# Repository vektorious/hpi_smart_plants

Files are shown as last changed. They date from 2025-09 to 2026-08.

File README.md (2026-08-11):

# Smart Plants Starter Kit

A hands-on introduction to building low-power, Wi-Fi-connected plant monitoring systems.
You'll learn the basics of microcontroller programming, soil moisture sensing, and Wi-Fi data
transfer — all while building a device that actually keeps your plants alive.

The device wakes from deep sleep, reads soil moisture (and optionally temperature, humidity,
light, and battery level), sends data to an online dashboard, then sleeps again to conserve
battery.

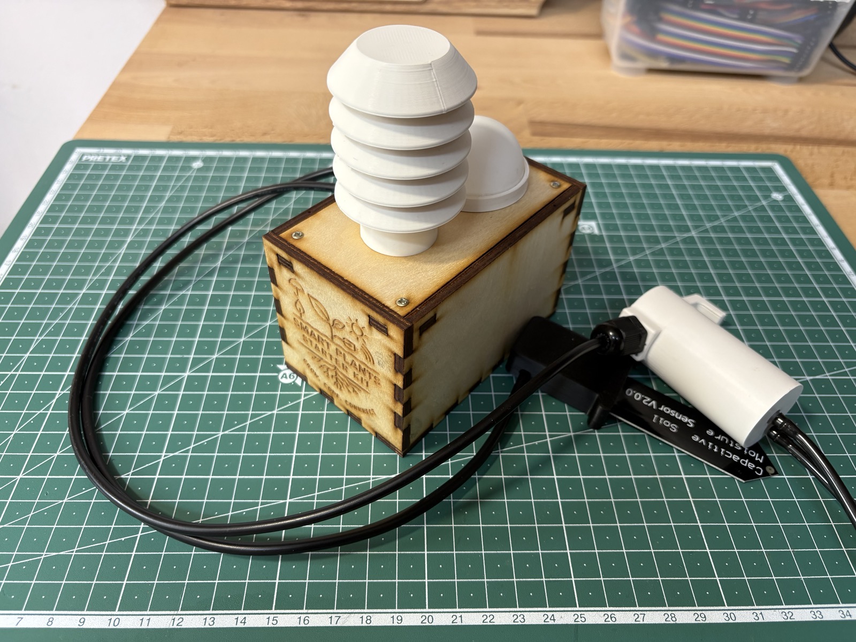
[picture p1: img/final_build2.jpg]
Smart Plants rev2 build


---

## What You'll Build

By the end of the workshop you'll have a battery-powered soil moisture sensor that:
- Measures soil moisture every hour (configurable)
- Sends data to an online dashboard via Wi-Fi
- Sleeps between measurements to conserve battery
- Waters your plant automatically when the soil gets too dry

No soldering experience required — but you'll get the chance to try!

---

## What's in the Kit

- Waveshare ESP32-C6 Zero microcontroller
- Smart Plants breakout PCB
- Capacitive soil moisture sensor + cable
- BME280 sensor (temperature, humidity, pressure)
- TSL2591 sensor (light)
- Mini diaphragm pump
- Battery pack
- Laser-cut housing
- 3D-printed sensor and pump housings
- Screws, velcro, cable gland

---

## Before You Begin

Make sure you have:
- A computer with a USB-C port (or adapter) and a **Chrome, Edge, or Opera** browser
  (used by the browser-based firmware installer)
- A USB-C **data** cable
- A 2.4 GHz Wi-Fi network

Everything else — firmware and configuration — is covered step by step in the build instructions
below. You install the firmware straight from the browser; only building it from source needs the
[Arduino IDE](https://www.arduino.cc/en/software).

---

## Build Instructions

**Start here:** [`instructions/build_instructions.md`](instructions/build_instructions.md)

That guide covers the full assembly, programming, calibration, and deployment for the main
Waveshare build — from soldering the PCB to seeing your first readings on the dashboard.

Firmware installs from the browser — no toolchain needed — via the web flasher:
**<https://vektorious.github.io/hpi_smart_plants/>**.

---

## Learning Goals

- Read analog sensor data and convert it to meaningful values
- Understand how to minimise power consumption with deep sleep
- Send data securely to a server over Wi-Fi using HTTP
- Learn how a cloud dashboard receives and displays live sensor readings

---

## Configured on the Device

All per-device settings — Wi-Fi, device name, sleep interval, moisture calibration, and
which sensors and the pump are enabled — are configured **on the device through a Wi-Fi setup
portal** after flashing, and stored in non-volatile memory. No code edits or recompiling: one
flashed binary works for every configuration.

The setup portal opens automatically on first boot (or on a double-press of the reset button) and
also shows **live sensor readings** and an **API connection test** so you can confirm everything
works. The `DEFAULT_*` values in `code/sp_modular/config.h` are only the factory defaults applied
on first boot. Building from source? See
[`instructions/firmware_from_source.md`](instructions/firmware_from_source.md).

---

## Board Variants

Two controller boards are supported. Both run the same firmware (`code/sp_modular/`).

| Variant | Board | PCB | Who it's for |
|---|---|-----|---|
| **Main build** | Waveshare ESP32-C6 Zero | `smart_plants_breakout_ws-board_rev2` | Student workshops |
| **Alternative** | SEEED Studio XIAO ESP32-C6 | `smart_plants_breakout_rev1` | Alternative / reference build |

---

## Repository Structure

```
code/
  sp_modular/              Modular firmware (current, for all builds)
    config.h               Factory defaults (DEFAULT_*), pin assignments, structs
    settings.ino           Runtime settings stored in NVS/Preferences
    portal.ino             WiFiManager setup portal + live sensor page
    sp_modular.ino         Entry point
    *.ino                  Sensor and actuator modules
  legacy/                  Old monolithic sketches (breadboard era, unsupported)

web-flasher/               Browser-based firmware installer (ESP Web Tools)

hardware/
  pcb/
    smart_plants_breakout_ws-board_rev2/   Main build PCB (Waveshare)
    smart_plants_breakout_rev1/            Alternative build PCB (XIAO)
    legacy/                                Older PCB revisions
    ext_files/                             KiCAD footprints and symbols
  3d-print/
    bme_housing/           Miniature Stevenson screen for BME280
    light_sensor/          TSL2591 mount with diffuser
    moisture_sensor/       Soil probe housing
    pump/                  Diaphragm pump enclosure
    cable_plugs/           M12 cable gland plug
  laser_files/
    SmartPlants_4mm_v3.svg Current enclosure template (4 mm material)
    legacy/                Older enclosure versions

instructions/
  build_instructions.md    Main build guide — start here
  firmware_from_source.md  Build/upload from Arduino IDE + component test sketches
  background_information.md Sensor theory, system overview, design rationale
  quick_reference/         Printable one-page build reference (md, html, pdf)
  legacy/                  Old breadboard-era guides (unsupported)

img/                       Photos and diagrams referenced by the instructions
```

---

## Background Reading

[`instructions/background_information.md`](instructions/background_information.md) covers:

- **Sensor selection** — why capacitive over resistive moisture sensors, why BME280 and TSL2591
  were chosen over simpler alternatives, and the trade-offs involved
- **Pump control** — how MOSFETs and relays work, and why this design uses an IRLZ14
- **How the system works** — the full data path from firmware wake-up cycle through the FastAPI
  server and PostgreSQL database to the live Grafana dashboard
- **Similar projects** — related open-source plant monitoring builds for further inspiration

Useful context for understanding *why* things are built the way they are.

---

## Licenses

| Component | License |
|---|---|
| Software (`code/`) | [MIT](LICENSE.code) |
| Hardware (`hardware/`) | [CERN-OHL-W 2.0](LICENSE.hardware) |
| Documentation (`instructions/`, `README.md`, `img/`) | [CC-BY 4.0](LICENSE.docs) |

Open Source Licenses

This project is certified open source hardware by OSHWA under certification ID `DE000173`.

OSHWA certification mark

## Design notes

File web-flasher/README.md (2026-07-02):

# Smart Plants — Web Flasher

A browser-based installer for the Smart Plants firmware, built on
[ESP Web Tools](https://esphome.github.io/esp-web-tools/). Students open a web page,
click **Connect**, and flash the board — no Arduino IDE or drivers needed.

## Files

| File | Purpose |
|---|---|
| `index.html` | The flasher page with the install button |
| `manifest.json` | Tells ESP Web Tools which chip + binary to flash |
| `firmware/smart_plants.bin` | The merged firmware image (generated — see below) |

## Requirements (for the student flashing)

- **Chrome, Edge, or Opera** on a desktop (Web Serial is not in Firefox/Safari or on iOS).
- The page must be served over **HTTPS** (or `http://localhost` for testing). Web Serial
  refuses to run on plain `http://`.
- A **USB-C data cable** (not charge-only).

## Building / updating the firmware image

The firmware is a single merged image flashed at offset `0x0`. The ESP32 Arduino core
produces this automatically — no manual `esptool merge_bin` step is needed.

### Option A — Arduino IDE

1. Open `code/sp_modular/` in Arduino IDE.
2. Select board **Waveshare ESP32-C6-Zero**, and under
   **Tools → Partition Scheme** choose **Huge APP (3MB No OTA/1MB SPIFFS)**.
   (The default partition is too small — the build won't fit.)
3. **Sketch → Export Compiled Binary.**
4. In the sketch's `build/…/` output folder, find `sp_modular.ino.merged.bin`.
5. Copy it to `web-flasher/firmware/smart_plants.bin`.

### Option B — arduino-cli

```bash
cd code
arduino-cli compile \
  --fqbn esp32:esp32:waveshare_esp32_c6_zero:PartitionScheme=huge_app \
  --output-dir /tmp/sp-build \
  sp_modular

cp /tmp/sp-build/sp_modular.ino.merged.bin \
   ../web-flasher/firmware/smart_plants.bin
```

After copying, bump `"version"` in `manifest.json` so returning users get the update.

> The merged image is a full 4 MB flash image starting at `0x0` (bootloader + partition
> table + app), which is exactly what the manifest expects: a single part at offset 0.

## Hosting

**Live at:** <https://vektorious.github.io/hpi_smart_plants/>
(served over HTTPS, which Web Serial requires).

GitHub Pages can only publish from a branch root or `/docs`, not an arbitrary subfolder, so the
site is published from a dedicated **`gh-pages`** branch that mirrors this folder at its root:

```
gh-pages/
├── index.html          # copy of web-flasher/index.html
├── manifest.json       # copy of web-flasher/manifest.json
├── .nojekyll
└── firmware/
    └── smart_plants.bin   # the merged image (tracked here, not on main)
```

The 4 MB binary lives only on `gh-pages` to keep `main` history clean.

**To publish a new firmware build:**

```bash
git worktree add /tmp/ghpages gh-pages           # check out the branch
cp web-flasher/index.html web-flasher/manifest.json /tmp/ghpages/
cp <build>/sp_modular.ino.merged.bin /tmp/ghpages/firmware/smart_plants.bin
# bump "version" in /tmp/ghpages/manifest.json
git -C /tmp/ghpages commit -am "Update flasher firmware" && git -C /tmp/ghpages push
git worktree remove /tmp/ghpages
```

## Local testing

```bash
cd web-flasher
python3 -m http.server 8000
# open http://localhost:8000  (localhost is treated as secure by Web Serial)
```

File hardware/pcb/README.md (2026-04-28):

# PCB Designs

Two active PCB designs are maintained, one per supported controller board. Both route sensors
to the same GPIO numbers, so no firmware changes are needed between variants.

## Active designs

### Waveshare ESP32-C6 Zero — `smart_plants_breakout_ws-board_rev2/` (main build)

The primary board used in student workshops. Designed for the
[Waveshare ESP32-C6 Zero](https://www.waveshare.com/wiki/ESP32-C6-Zero).

- **Gerber files:** `sp_ws_breakout_rev2/` folder and `sp_ws_breakout_rev2.zip`
- **KiCAD project:** `smart_plants_breakout_ws-board_rev2.kicad_pro`
- **Firmware pin config:** active block in `code/sp_modular/config.h`

### SEEED Studio XIAO ESP32-C6 — `smart_plants_breakout_rev1/` (alternative build)

Alternative build based on the [XIAO ESP32-C6](https://wiki.seeedstudio.com/xiao_esp32c6_getting_started/).

- **Gerber files:** `smart_plants_breakout_rev1_gerber/` folder and `smart_plants_breakout_rev1_gerber.zip`
- **KiCAD project:** `smart_plants_breakout_rev1.kicad_pro`
- **BOM:** `smart_plants_breakout_rev1.csv`
- **Firmware pin config:** see the commented-out XIAO block in `code/sp_modular/config.h` (TODO: GPIO numbers need to be verified)

## Ordering PCBs

1. Download the Gerber `.zip` file for your chosen variant.
2. Upload it to a PCB fab of your choice (e.g., JLCPCB, PCBWay, Aisler).
3. Default settings (1.6 mm FR4, 2 layers, HASL finish) work fine.

## Opening in KiCAD

Open the `.kicad_pro` file in KiCAD 8 or later. External footprint libraries are in
`ext_files/` — KiCAD will prompt you to resolve them on first open; point it to that folder.

## Legacy designs

Older PCB revisions are in `legacy/`. They are archived for reference only.

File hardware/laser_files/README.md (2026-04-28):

# Laser-Cut Housing Files

## Current design

**`SmartPlants_4mm_v3.svg`** — use this file.

Designed for **4 mm material** (plywood or MDF recommended). Cut on any CO2 or diode laser cutter.

## Legacy designs

Older versions are in the `legacy/` subfolder. They are kept for reference but are not recommended:

| File | Notes |
|---|---|
| `SmartPlants_4mm_with_holes_v2.svg` | Previous version with ventilation holes |
| `SmartPlants_4mm_with_holes.svg` | Earlier hole variant |
| `SmartPlants_4mm_no_top_holes.svg` | No top holes variant |
| `SmartPlants_4mm.svg` | Original 4 mm design |
| `SmartPlants_3mm.svg` | 3 mm material variant |

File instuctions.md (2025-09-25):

# Build Instructions
## 1. Collect All Parts
At the beginning get all the necessary parts together. 

**List of parts**
- Breadboard
- XIAO ESP32C6 Microcontroller
- Battery Case
- 3x AA Batteries
- Schottky Diode
- Moisture Sensor
- Sensor Cable
- Sensor Housing
- 3x Jumper Cable
- 2x 220k Ohm Resistors
- laser-cut Housing
- 8x Wood Screws
- Velcro Tape

## 2. Prepare Parts
Some parts have to be prepared (soldered/crimped/glued). You have the option to get them pre-prepared from us if you feel unconfortable using the tools but you are encouraged to try even if you never used them before!

Obviously all preparation don't have to be done in an particular order. So if you see that some tools are in use that you need, just do some other preparation.

**Solder Microcontroller (skip if in the workshop)**\
Solder the pin header to the microcontroller and add wires to the battery pads.

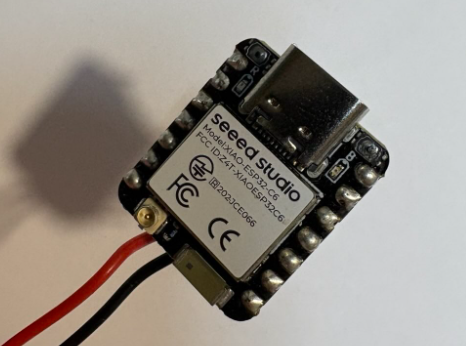
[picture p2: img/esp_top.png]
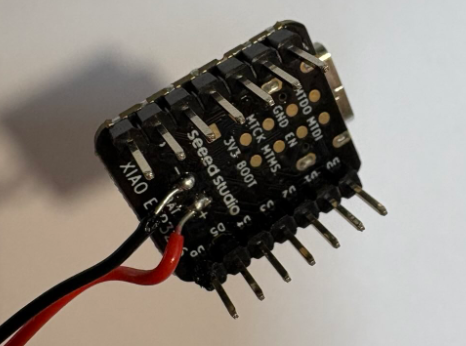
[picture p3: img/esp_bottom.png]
 

**Crimp Cable (skip if in the workshop)**\
Crimp one 3-pin JST (PH) connector on one side of the cable and a 3-pin male Dupont connector on the other. Make sure the wires follow the correct order: VCC (red), SIGNAL (yellow), GND (black). If you want the cable to fit tightly through the hole in the housing, feed the cable through the hole before crimping the connector, as crimped plugs won’t fit through small openings.

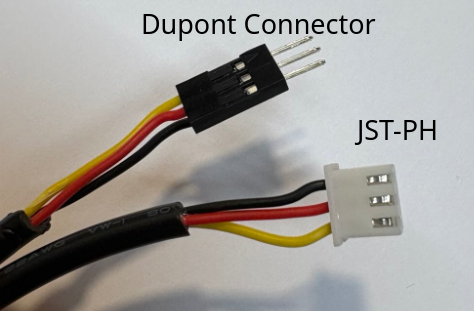
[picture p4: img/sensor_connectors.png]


**Prepare Sensor**\
_Discard the cable that comes with the sensor_ (give it to us). Connect the sensor with the longer round cable you just prepared. Put the sensor into the 3D-printed housing and screw it together. We recommend to push the black isolation of the cable into the housing hole so it seals it tightly.

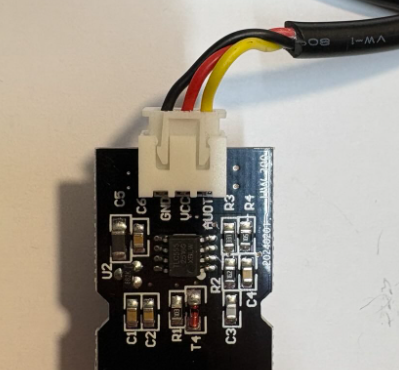
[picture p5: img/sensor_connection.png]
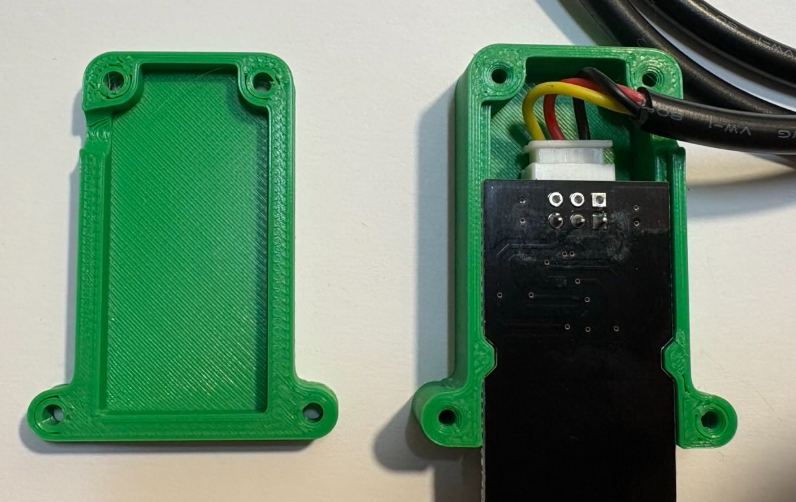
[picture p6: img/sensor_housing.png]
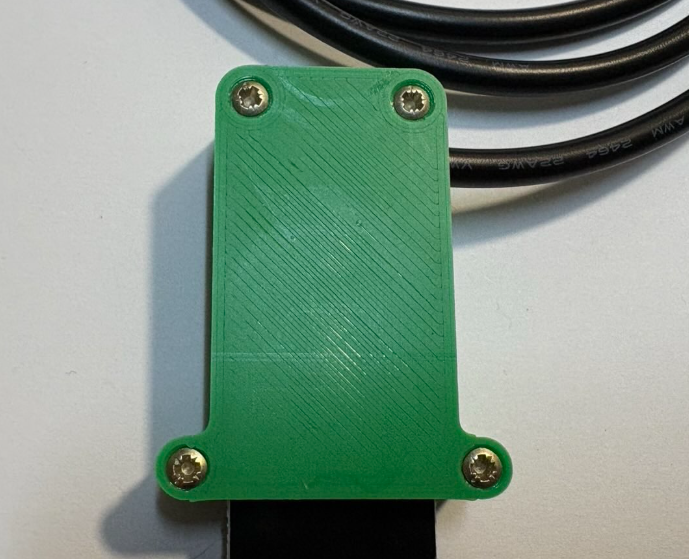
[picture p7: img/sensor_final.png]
  

**Prepare the Housing (skip if in the workshop and do it home or after everything else is done)**\
Assemble the laser-cut housing. Drill a hole into one wall for the sensor cable. Use a 8mm drill for the hole. If you want to have the cable fit very tightly in the hole, you can use a 5mm drill but you might need to remove the connector end of the cable to fit it through (or put it through the hole before crimping).

⚠️ Important: ADO NOT add the small corners at the end. Add them while you are connecting the sides. Otherwise you won't be able to fit them in there!

## 3. Assemble the Circuit
Add all parts to the breadboard as shown in the circuit below.
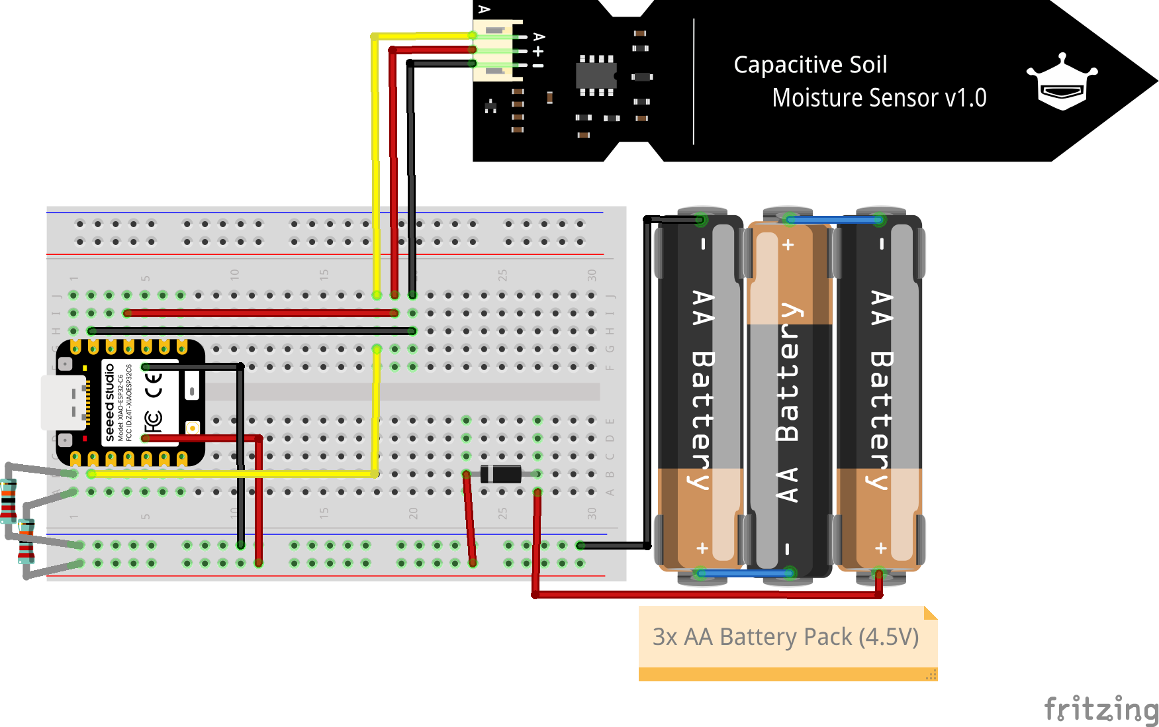
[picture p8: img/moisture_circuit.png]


XIAO ESP32C6 Pinout
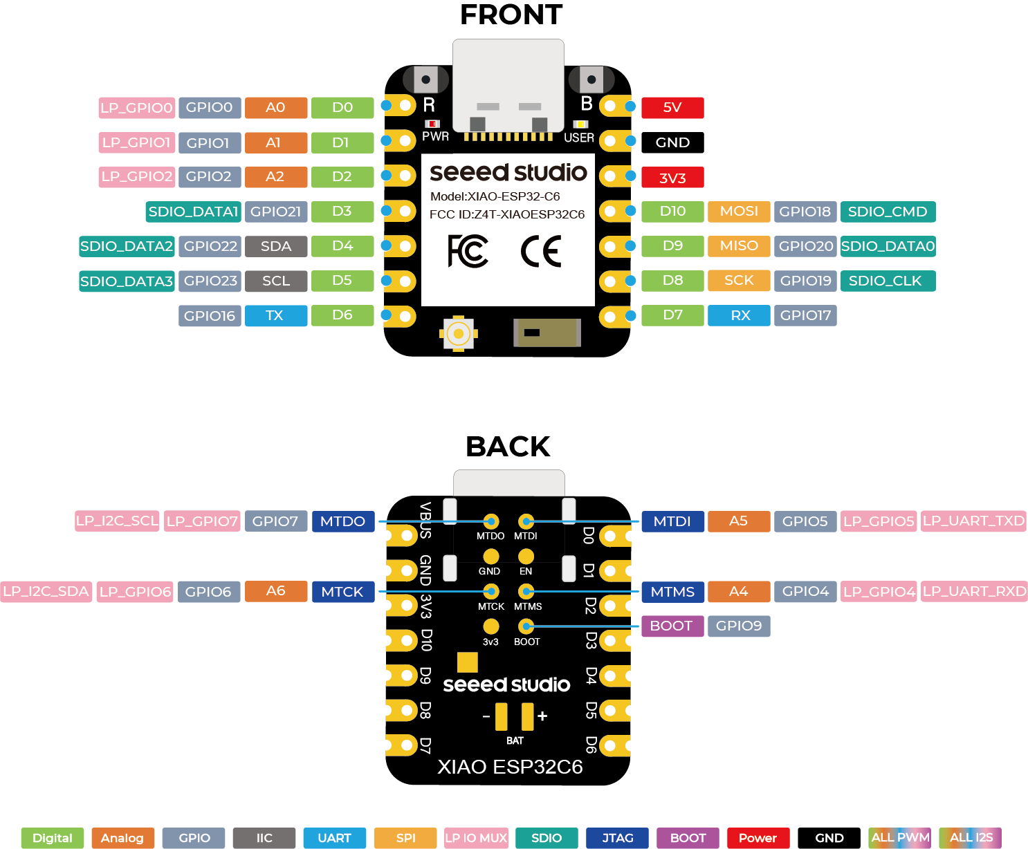
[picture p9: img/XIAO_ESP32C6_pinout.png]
XIAO ESP32C6 Pinout
 

⚠️ Important: Do not connect the battery pack yet. We’ll add it only after programming and testing to avoid accidental powering.

Here are all the connections written out:

Moisture Sensor:
- Signal pin (yellow cable) to board pin A1
- Vcc pin (power, red cable) to board pin D10
- GND pin (ground, black cable) to board GND

Microcontroller:
- Battery Pad + to the + rail in the breadboard
- Battery Pad - to the - rail in the breadboard
- Connect pin A0 to the + and - rail with a 220k Ohm Resistor (voltage divider). Be careful, the legs of the resistor on the rail side should not touch.

We will connect the battery pack through the Schottky diode in the last steps.

It should look like this in the end:

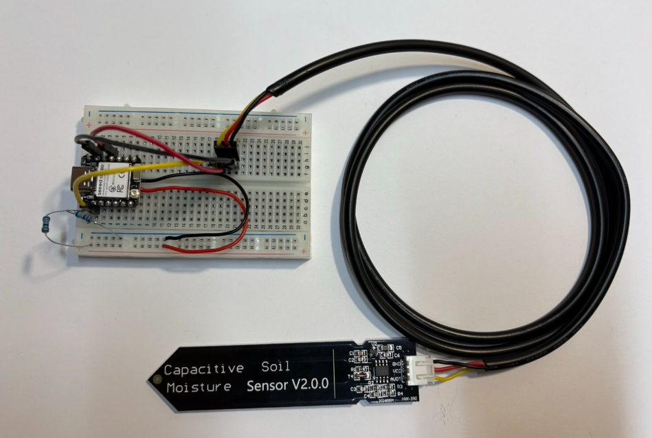
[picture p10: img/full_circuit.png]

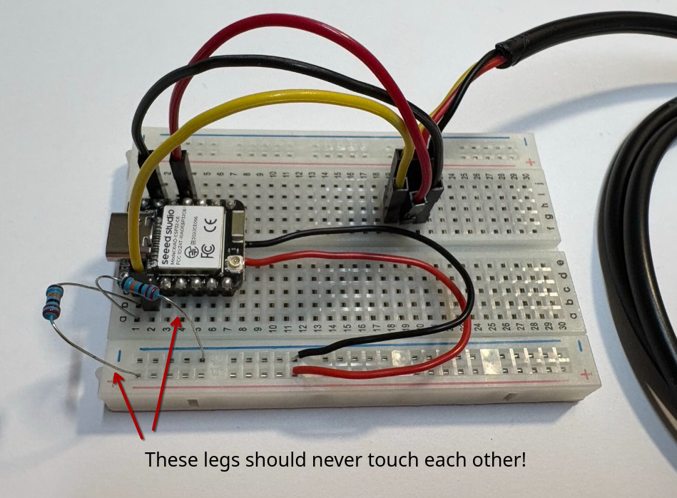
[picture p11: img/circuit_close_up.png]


## 4. Program the Microcontroller
### 4.1 Preparations
You should already have the Arduino IDE with the respective board libraries set up. If not, check out these [instructions](https://wiki.seeedstudio.com/xiao_esp32c6_getting_started/#software-preparation).

### 4.2 Install the WiFiManager Library
You still need to install the WiFiManager libary. In the Arduino IDE select Tools > Manage Libraries. In the search bar enter "wifimanager" and install the library from "tzapu" (see below).

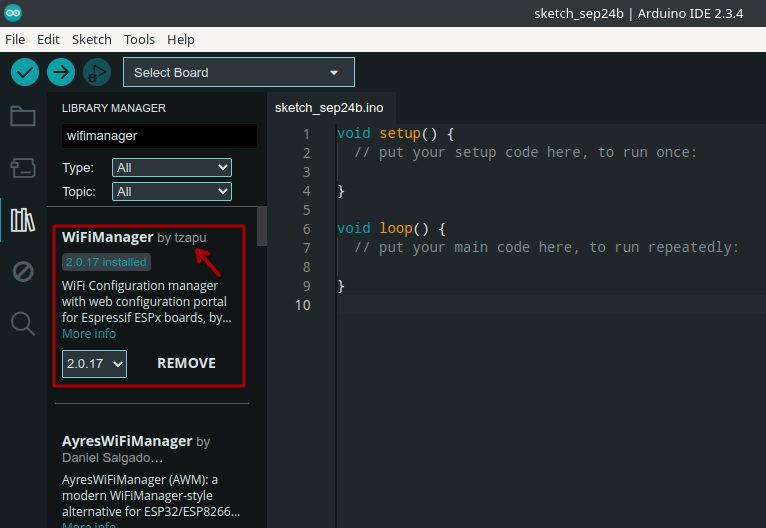
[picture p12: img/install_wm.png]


### 4.3 How to upload code to the Microcontroller
Here are the general steps to upload a programm to your microcontroller:
1. Connect your _XIAO ESP32-C6_ to your computer via USB
2. In the Arduino IDE:
    - Select the correct board under Tools > Board (the correct board is "XIAO_ESP32-C6")
    - Select the correct port under Tools > Port (this is usually already preselected)
3. Click the Upload button

⚠️ If the upload fails because the device is in deep sleep (only if you have programmed it before):

1. Unplug the board
2. Hold the BOOT button
3. Plug it back in while still holding BOOT
4. Release the button after 2 seconds
5. Try uploading again

### 4.4 Test Moisture Sensor
Copy this script into your Arduino IDE and flash the ESP with it. You should see output in the Serial Monitor (if not active yet, Tools>Serial Monitor)

Note: Make sure the sensor cable is fully plugged in and the metal prongs of the sensor are not touching each other. Readings may be unstable if the power to the sensor is not reliable.

```cpp
const int moisturePin = A1;
const int moisturePower = D10;

const float minMoistureVoltage = 0.5;
const float maxMoistureVoltage = 2.5;

float readMoistureVoltage() {
  uint32_t sum = 0;
  for (int i = 0; i < 16; i++) {
    sum += analogReadMilliVolts(moisturePin);
  }
  return sum / 16.0 / 1000.0;
}

float moistureVoltageToPercent(float voltage) {
  float percent = (maxMoistureVoltage - voltage) / (maxMoistureVoltage - minMoistureVoltage) * 100.0;
  return constrain(percent, 0.0, 100.0);
}

void setup() {
  Serial.begin(115200);
  delay(1000);
  Serial.println("Moisture Sensor Test");
  Serial.println();
}

void loop() {
  pinMode(moisturePower, OUTPUT);
  digitalWrite(moisturePower, HIGH);
  delay(200);  // sensor warm-up time

  float moistureVoltage = readMoistureVoltage();
  float moisturePercent = moistureVoltageToPercent(moistureVoltage);

  digitalWrite(moisturePower, LOW);

  Serial.println("Sensor Reading:");
  Serial.println("---------------------------");
  Serial.printf("Moisture Voltage : %.3f V\n", moistureVoltage);
  Serial.printf("Moisture Percent : %.1f %%\n", moisturePercent);
  Serial.println("---------------------------\n");

  delay(5000);  // wait 5 seconds
}

```

### 4.5 Moisture Sensor Calibration (skip if in the workshop)

The moisture sensor gives you a voltage that decreases as moisture increases. To convert this into a percentage, you need to define two reference points:

- Dry: The voltage when the sensor is in air or dry soil (corresponds to 0%).
- Wet: The voltage when the sensor is in water or fully saturated soil (corresponds to 100%).

These voltages vary slightly between sensors, so calibrating each one improves accuracy.

Steps:
Dry measurement:

- Leave the sensor in air.
- Wait a few seconds and note the voltage value printed to the Serial Monitor.
- This is your maximum voltage (corresponds to 0% moisture).

Wet measurement:

- Insert the sensor tips into very wet soil or a glass of water (only the metal part).
- Wait a few seconds and note the voltage value.
- This is your minimum voltage (corresponds to 100% moisture).

Update your code:

Set the minMoistureVoltage and maxMoistureVoltage constants in your code to match the measured values:

```cpp
const float minMoistureVoltage = 0.5;
const float maxMoistureVoltage = 2.5;

```
Note: Use these values in the final code as well!

### 4.6 Upload Final Script
Download or copy the final code from this repository.

Before uploading the final code, open the sketch in Arduino IDE and scroll to the "USER SETTINGS" section at the top. Adjust the following values to match your setup:

```cpp
#include <WiFi.h>
#include <HTTPClient.h>
#include <WiFiManager.h>  // https://github.com/tzapu/WiFiManager

// ================= USER SETTINGS =================

// Device identification
// Choose a unique name and short ID for your device
// You can use an UUID generator and just use the first part (8 symbols) of the generated ID
// https://www.uuidgenerator.net/version4
const char* deviceName = "Maker Universe";
const char* deviceUUID = "22593b21";

// API endpoint
const char* apiUrl  = "https://plants.makeruniverse.de/plants/measurements";
const char* apiKey  = "vKpsikScqRUt2CdC";

// Moisture sensor calibration
// Measure voltage when sensor is in water (100%) and dry soil or air (0%)
const float minMoistureVoltage = 0.60;
const float maxMoistureVoltage = 2.45;

// Battery voltage divider ratio
// Only change this if you are using a different resistor setup
const float batteryDividerRatio = 2.0;

// Measurement interval (in seconds)
// 300 = 5 minutes, 3600 = 1 hour
// Measuring every hour is recommended for longer battery life
#define TIME_TO_SLEEP 3600 

// ================= PIN CONFIG ====================
const int moisturePin     = A1;
const int batteryPin      = A0;
const int sensorPowerPin  = D10;

#define uS_TO_S_FACTOR 1000000ULL
RTC_DATA_ATTR int bootCount = 0;

/// ========== FUNCTIONS ==========

void printWakeupReason() {
  esp_sleep_wakeup_cause_t reason = esp_sleep_get_wakeup_cause();
  switch (reason) {
    case ESP_SLEEP_WAKEUP_TIMER:
      Serial.println("Wakeup: Timer");
      break;
    default:
      Serial.printf("Wakeup not from timer: %d\n", reason);
      break;
  }
}

void setupWiFi() {
  WiFi.mode(WIFI_STA);
  WiFi.begin();

  Serial.print("Connecting to Wi-Fi");
  int retries = 0;
  while (WiFi.status() != WL_CONNECTED && retries < 20) {
    delay(500);
    Serial.print(".");
    retries++;
  }
  Serial.println();

  if (WiFi.status() == WL_CONNECTED) {
    Serial.println("Wi-Fi connected: " + WiFi.localIP().toString());
    return;
  }

  Serial.println("Wi-Fi failed. Starting WiFiManager...");
  WiFiManager wm;
  String apName = "SmartPlant-Setup-" + String(deviceName);
  wm.setConfigPortalTimeout(120);  // 2 min timeout
  if (!wm.autoConnect(apName.c_str())) {
    Serial.println("WiFiManager failed or timed out. Sleeping...");
    shutdownAndSleep();
  }
}

float readBatteryVoltage() {
  analogRead(batteryPin);
  delay(50);
  uint32_t Vbatt = 0;
  for (int i = 0; i < 16; i++) {
    Vbatt += analogReadMilliVolts(batteryPin);
  }
  return batteryDividerRatio * Vbatt / 16 / 1000.0;
}

float readMoistureVoltage() {
  delay(50);
  uint32_t Vraw = 0;
  for (int i = 0; i < 16; i++) {
    Vraw += analogReadMilliVolts(moisturePin);
  }
  return Vraw / 16.0 / 1000.0;
}

float moistureVoltageToPercent(float voltage) {
  float percent = (maxMoistureVoltage - voltage) / (maxMoistureVoltage - minMoistureVoltage) * 100.0;
  return constrain(percent, 0.0, 100.0);
}

void sendData(float moistureVoltage, float moisturePercent, float batteryVoltage) {
  if (WiFi.status() == WL_CONNECTED) {
    HTTPClient http;
    http.begin(apiUrl);
    http.addHeader("Content-Type", "application/json");
    http.addHeader("x-api-key", apiKey);

    String json = "{";
    json += "\"name\": \"" + String(deviceName) + "\",";
    json += "\"device_uuid\": \"" + String(deviceUUID) + "\",";
    json += "\"sensors\": {";
    json += "\"moisture_voltage\": {\"value\": " + String(moistureVoltage, 3) + ", \"unit\": \"V\"},";
    json += "\"moisture\": {\"value\": " + String(moisturePercent, 1) + ", \"unit\": \"%\"},";
    json += "\"battery_voltage\": {\"value\": " + String(batteryVoltage, 2) + ", \"unit\": \"V\"}";
    json += "}}";

    int httpResponseCode = http.POST(json);
    Serial.println("POST response code: " + String(httpResponseCode));
    Serial.println("Payload: " + json);
    http.end();
  } else {
    Serial.println("WiFi not connected, skipping data send.");
  }
}

void shutdownAndSleep() {
  digitalWrite(sensorPowerPin, LOW);
  WiFi.disconnect(true);
  WiFi.mode(WIFI_OFF);
  delay(200);
  Serial.flush();
  Serial.end();
  esp_sleep_enable_timer_wakeup(TIME_TO_SLEEP * uS_TO_S_FACTOR);
  esp_deep_sleep_start();
}

// ========== MAIN ==========

void setup() {
  Serial.begin(115200);
  delay(1000);

  ++bootCount;
  Serial.println("Boot #" + String(bootCount));
  printWakeupReason();

  setupWiFi();

  pinMode(sensorPowerPin, OUTPUT);
  digitalWrite(sensorPowerPin, HIGH);
  delay(200);
  float moistureVoltage = readMoistureVoltage();
  float moisturePercent = moistureVoltageToPercent(moistureVoltage);
  digitalWrite(sensorPowerPin, LOW);

  float batteryVoltage = readBatteryVoltage();

  Serial.println("Moisture voltage: " + String(moistureVoltage, 3) + " V");
  Serial.println("Moisture percent: " + String(moisturePercent, 1) + " %");
  Serial.println("Battery voltage: " + String(batteryVoltage, 2) + " V");

  sendData(moistureVoltage, moisturePercent, batteryVoltage);
  shutdownAndSleep();
}

void loop() {
  // Nothing here
}

```

### 4.7 How to Use the Sensor
This project uses WiFiManager, a user-friendly tool that allows the device to connect to a Wi-Fi network without hardcoded credentials. When powered on for the first time (or if no connection can be established), the device automatically starts a temporary Wi-Fi access point for 2 minutes, where users can enter their home Wi-Fi details via a web interface. After configuration, the device connects automatically in future sessions without needing to re-enter the credentials. You can always re-trigger the launch of the access point by switching the device off and on again.

Upload the code, look out for a Wi-Fi access point named "SmartPlant-Setup-DEVICE_NAME". Connect to it and enter the Wifi credentials. Now monitor the dashboard at ([plants.makeruniverse.de](plants.makeruniverse.de). You should see your plant/device coming up soon! If that worked, you are ready for the final Assembly.

Tip: For battery-powered operation, it's best to set the sleep time to 3600 seconds (1 hour). This gives you a good balance between data frequency and battery life.

## 5.Final Test and Assembly

Unplug the Microcontroller and add the battery pack to the circuit (keep it switched off first). Connect the - of the battery pack to the - rail. Connect  the + of the pack to the + rail through the Schottky diode. The diode protects the batteries. Take a close look at the orientation of the diode!

If everything is connected correctly (double check) and no USB is connected to the microcontroller, flip the switch of the battery pack and watch for your data coming in on the dashboard.

If that worked, you are ready for putting everything into the housing. Switch off the battery pack first! I recommend gluing the the breadboard to the back of the housing by removing parts of the cover of the tape on the back of it. Add the velco tape to the battery pack and the inner side of the housing lid so it can be attached there. Before you screw on the lid, switch on the battery pack again. 

⚠️ Note: Switching the battery off and on again, re-triggers a measurement. If there is a Wifi connection, you should see the values appearing on the dashboard.

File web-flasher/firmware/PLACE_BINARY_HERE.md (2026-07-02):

# Firmware image goes here

The flasher expects the merged firmware image at:

    web-flasher/firmware/smart_plants.bin

It is **not committed** — generate it with Arduino IDE or arduino-cli and copy it here.
See [`../README.md`](../README.md) → "Building / updating the firmware image".

Once `smart_plants.bin` is in this folder, the flasher page is ready to serve.

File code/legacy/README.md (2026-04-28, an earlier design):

# Legacy Sketches

These are the original monolithic Arduino sketches from the breadboard era of this project.

They are **no longer maintained or supported**. The current firmware is `code/sp_modular/`.

## Why they are kept

Preserved here for reference in case you want to understand the project's history or run a
stripped-down build without the full modular setup. The full breadboard-era repository state
is also available at git tag `v0-breadboard`.

## What's here

| Folder | What it does |
|---|---|
| `moisture/` | Moisture sensor only — no pump, no I2C sensors |
| `moisture-pump/` | Moisture sensor + pump control |
| `moisture-pump-BME280/` | + BME280 (temperature, humidity, pressure) |
| `moisture-pump-BME280-TSL2591/` | + TSL2591 light sensor (full feature set) |

## Important differences from sp_modular

- These sketches use **different GPIO pin assignments** than the current PCB design.
- They are **monolithic** — all code is in one `.ino` file per sketch.
- They target **breadboard wiring**, not the PCB.
- No `SensorPacket` struct — sensor values are passed as individual function parameters.

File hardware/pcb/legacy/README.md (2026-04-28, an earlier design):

# Legacy PCB Designs

These PCB revisions have been superseded and are kept here for reference only.

| Folder | Board | Notes |
|---|---|---|
| `smart_plants_breakout_ws-board_rev1/` | Waveshare ESP32-C6 Zero | First PCB iteration, superseded by rev2 |

The current Waveshare board design is `hardware/pcb/smart_plants_breakout_ws-board_rev2/`.

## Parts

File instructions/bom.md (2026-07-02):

# Bill of Materials — Smart Plants Starter Kit (ws-board rev2)

Complete parts list for one device. PCB components are the discrete parts soldered onto the
Smart Plants Breakout PCB; the Electronics, Mechanical, and Tools sections cover everything
else needed for the full build.

## PCB Components

| Reference | Component | Qty | Value | Notes |
|---|---|-----|---|---|
| — | Smart Plants Breakout PCB (bare board) | 1 | ws-board rev2 | Populated with the components below |
| R1, R2 | Resistor | 2 | 220 kΩ | Battery voltage divider |
| R3 | Resistor | 1 | 10 kΩ | MOSFET gate pull-down |
| R4 | Resistor | 1 | 22 Ω | MOSFET gate protection |
| R5, R6 | Resistor | 2 | 4.7 kΩ | I2C pull-up |
| D1 | Diode | 1 | 1N4001 | Flyback diode — stripe (cathode) faces pump + |
| D2 | Diode | 1 | 1N5817 | Schottky diode — stripe (cathode) per silkscreen |
| C2 | Capacitor | 1 | 220 µF | Electrolytic — long leg to + hole |
| C3 | Capacitor | 1 | 22 µF | Electrolytic — long leg to + hole |
| Q1 | MOSFET | 1 | IRLZ14 | Flat side matches silkscreen outline |
| J3, J5, J6, J11 | I2C JST connector | 4 | 4-pin JST XH | |
| J9 | Moisture sensor connector | 1 | 3-pin JST XH | |
| J7, SW1 | Battery / switch connector | 2 | 2-pin JST XH | |
| J10 | Pump connector | 1 | 2-pin JST XH | |
| J4 | USB-C power connector | 1 | 2-pin JST PH | Smaller pitch (2.0 mm) than the XH connectors |
| J1, J2 | Microcontroller socket | 2 | 9-pin pin socket | Solder to PCB; insert the Waveshare board after |

## Electronics

| Item | Qty | Spec | Notes |
|---|-----|---|---|
| Microcontroller | 1 | Waveshare ESP32-C6 Zero | |
| Capacitive soil moisture sensor | 1 | | |
| 3-core cable | 1 | | Self-crimped for the moisture sensor |
| 3-pin female JST XH connector | 2 | 3-pin JST XH | For the moisture sensor cable (both ends) |
| BME280 sensor module | 1 | Temperature/humidity/pressure | |
| TSL2591 sensor module | 1 | Light | |
| Pre-crimped 4-core cable | 2 | 4-pin JST XH | For BME280 and TSL2591 sensors |
| Mini diaphragm pump | 1 | | |
| 2-core cable | 1 | | Self-crimped for the pump |
| 2-pin female JST XH connector | 1 | 2-pin JST XH | For the pump cable |
| Battery pack | 1 | 3× AA | |
| USB-C connector | 1 | | With cable |
| On/Off switch | 1 | | |
| Pre-crimped 2-core cable | 1 | 2-pin JST XH | For the on/off switch |

## Mechanical

| Item | Qty | Notes |
|---|-----|---|
| 3D-printed battery housing and PCB mount | 1 | |
| 3D-printed moisture sensor housing + lid | 1 | |
| 3D-printed pump housing | 1 | |
| 3D-printed BME280 housing | 1 | Stevenson Screen |
| 3D-printed TSL2591 housing | 1 | |
| Ping pong ball half | 1 | Diffusor for the TSL2591 light sensor |
| 3D-printed cable plugs | 2 | |
| Laser-cut enclosure | 1 | |
| Wood screws | 12 | |
| Velcro tape | 1 | |
| PG7 cable gland | 1 | For pump cable |
| Tubes | 2 | Pump inlet/outlet |

## Tools

| Item | Qty | Notes |
|---|-----|---|
| Soldering iron + solder | 1 | |
| Crimping tool | 1 | For JST connectors |
| Wire cutters / flush cutters | 1 | |
| Wire strippers | 1 | |
| Screwdriver | 1 | |
| Hot-glue gun | 1 | Or other glue |
| Drill with 8 mm bit | 1 | Only needed if the housing cable hole is not pre-cut |

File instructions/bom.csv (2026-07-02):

Category | Item | Reference | Qty | Value/Spec | Notes
PCB Component | Smart Plants Breakout PCB (bare board) |  | 1 | ws-board rev2 | Populated with the components below
PCB Component | Resistor | R1, R2 | 2 | 220 kΩ | Battery voltage divider
PCB Component | Resistor | R3 | 1 | 10 kΩ | MOSFET gate pull-down
PCB Component | Resistor | R4 | 1 | 22 Ω | MOSFET gate protection
PCB Component | Resistor | R5, R6 | 2 | 4.7 kΩ | I2C pull-up
PCB Component | Diode | D1 | 1 | 1N4001 | Flyback diode — stripe (cathode) faces pump +
PCB Component | Diode | D2 | 1 | 1N5817 | Schottky diode — stripe (cathode) per silkscreen
PCB Component | Capacitor | C2 | 1 | 220 µF | Electrolytic — long leg to + hole
PCB Component | Capacitor | C3 | 1 | 22 µF | Electrolytic — long leg to + hole
PCB Component | MOSFET | Q1 | 1 | IRLZ14 | Flat side matches silkscreen outline
PCB Component | I2C JST connector | J3, J5, J6, J11 | 4 | 4-pin JST XH
PCB Component | Moisture sensor connector | J9 | 1 | 3-pin JST XH
PCB Component | Battery / switch connector | J7, SW1 | 2 | 2-pin JST XH
PCB Component | Pump connector | J10 | 1 | 2-pin JST XH
PCB Component | USB-C power connector | J4 | 1 | 2-pin JST PH | Smaller pitch (2.0 mm) than the XH connectors
PCB Component | Microcontroller socket | J1, J2 | 2 | 9-pin pin socket | Solder to PCB; insert the Waveshare board after
Electronics | Microcontroller |  | 1 | Waveshare ESP32-C6 Zero
Electronics | Capacitive soil moisture sensor |  | 1
Electronics | 3-core cable |  | 1 |  | Self-crimped for the moisture sensor
Electronics | 3-pin female JST XH connector |  | 2 | 3-pin JST XH | For the moisture sensor cable (both ends)
Electronics | BME280 sensor module |  | 1 | Temperature/humidity/pressure
Electronics | TSL2591 sensor module |  | 1 | Light
Electronics | Pre-crimped 4-core cable |  | 2 | 4-pin JST XH | For BME280 and TSL2591 sensors
Electronics | Mini diaphragm pump |  | 1
Electronics | 2-core cable |  | 1 |  | Self-crimped for the pump
Electronics | 2-pin female JST XH connector |  | 1 | 2-pin JST XH | For the pump cable
Electronics | Battery pack |  | 1 | 3× AA
Electronics | USB-C connector |  | 1 |  | With cable
Electronics | On/Off switch |  | 1
Electronics | Pre-crimped 2-core cable |  | 1 | 2-pin JST XH | For the on/off switch
Mechanical | 3D-printed battery housing and PCB mount |  | 1
Mechanical | 3D-printed moisture sensor housing + lid |  | 1
Mechanical | 3D-printed pump housing |  | 1
Mechanical | 3D-printed BME280 housing |  | 1 | Stevenson Screen
Mechanical | 3D-printed TSL2591 housing |  | 1
Mechanical | Ping pong ball half |  | 1 |  | Diffusor for the TSL2591 light sensor
Mechanical | 3D-printed cable plugs |  | 2
Mechanical | Laser-cut enclosure |  | 1
Mechanical | Wood screws |  | 12
Mechanical | Velcro tape |  | 1
Mechanical | PG7 cable gland |  | 1 |  | For pump cable
Mechanical | Tubes |  | 2 |  | Pump inlet/outlet
Tool | Soldering iron + solder |  | 1
Tool | Crimping tool |  | 1 |  | For JST connectors
Tool | Wire cutters / flush cutters |  | 1
Tool | Wire strippers |  | 1
Tool | Screwdriver |  | 1
Tool | Hot-glue gun |  | 1 |  | Or other glue
Tool | Drill with 8 mm bit |  | 1 |  | Only needed if the housing cable hole is not pre-cut

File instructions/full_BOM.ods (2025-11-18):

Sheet: recommended_equipment
Part | Comment
Crimp Equipment
JST Connectors
Dupont Connectors
Velcro tape
3-core cable
2-core cable
jumper cable
tubing

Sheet: base_module_batteries
Part | Quantity | Comment
Breadboard | 1
ESP32C6 board | 1
Battery case | 1
AA Alkaline batteries | 3
Schottky diode | 1
Moisture sensor | 1
3D-printed moisture sensor housing | 1
220k Ohm resistor | 2
Device housing | 1
Wood screws | 8

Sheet: base_module_li-ion
Part | Quantity | Comment
Breadboard | 1
ESP32C6 board | 1
18650 battery holder | 1
18650 li-ion cell | 1
Moisture sensor | 1
3D-printed moisture sensor housing | 1
220k Ohm resistor | 2
Laser-cut device housing | 1
Wood screws | 8

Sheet: pump_add-on
Part | Quantity | Comment
Diaphragm pump | 1
MOSFET (IRLZ14) | 1
PG cable gland | 1
3D-printed pump housing | 1
10k Ohm resistor | 1
22 Ohm resistor | 1
Schottky diode | 1

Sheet: i2c_sensor_add-on
Part | Quantity | Comment
GY-BME280 Sensor breakout | 1
TSL25911 Sensor breakout | 1
3D-printed BME280 housing (4 parts) | 1
3D-printed TSL25911 housing | 1
Half ping pong ball | 1 | diffusor for the TSL25911 housing

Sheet: convenience_add-on
Part | Quantity | Comment
Power switch | 1
USB-C Power socket | 1

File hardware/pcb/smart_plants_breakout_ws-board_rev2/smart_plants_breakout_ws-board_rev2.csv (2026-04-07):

# | Reference | Qty | Value | Footprint | DNP
1 | C2 | 1 | 220µF | Capacitor_THT:CP_Radial_D8.0mm_P3.50mm
2 | C3 | 1 | 22µF | Capacitor_THT:CP_Radial_D8.0mm_P3.50mm
3 | D1 | 1 | 1N4001 | Diode_THT:D_DO-41_SOD81_P10.16mm_Horizontal
4 | D2 | 1 | 1N5817 | Diode_THT:D_DO-41_SOD81_P10.16mm_Horizontal
5 | J1, J2 | 2 | Conn_01x09_Pin | Connector_PinSocket_2.54mm:PinSocket_1x09_P2.54mm_Vertical
6 | J3, J6 | 2 | I2C | Connector_JST:JST_XH_B4B-XH-A_1x04_P2.50mm_Vertical
7 | J4 | 1 | USB-C Power | Connector_JST:JST_PH_B2B-PH-K_1x02_P2.00mm_Vertical
8 | J5 | 1 | I2C D2-powered | Connector_JST:JST_XH_B4B-XH-A_1x04_P2.50mm_Vertical
9 | J7 | 1 | Battery | Connector_JST:JST_XH_B2B-XH-A_1x02_P2.50mm_Vertical
10 | J9 | 1 | Moisture Sensor | Connector_JST:JST_XH_B3B-XH-A_1x03_P2.50mm_Vertical
11 | J10 | 1 | Pump | Connector_JST:JST_XH_B2B-XH-A_1x02_P2.50mm_Vertical
12 | J11 | 1 | I2C D3-powered | Connector_JST:JST_XH_B4B-XH-A_1x04_P2.50mm_Vertical
13 | Q1 | 1 | IRLZ14 | Package_TO_SOT_THT:TO-220-3_Vertical
14 | R1, R2 | 2 | 220k | Resistor_THT:R_Axial_DIN0207_L6.3mm_D2.5mm_P10.16mm_Horizontal
15 | R3 | 1 | 10k | Resistor_THT:R_Axial_DIN0207_L6.3mm_D2.5mm_P10.16mm_Horizontal
16 | R4 | 1 | 22R | Resistor_THT:R_Axial_DIN0207_L6.3mm_D2.5mm_P10.16mm_Horizontal
17 | R5, R6 | 2 | 4k7 | Resistor_THT:R_Axial_DIN0207_L6.3mm_D2.5mm_P10.16mm_Horizontal
18 | SW1 | 1 | Power Switch | Connector_JST:JST_XH_B2B-XH-A_1x02_P2.50mm_Vertical
19 | U1 | 1 | Waveshare ESP32-C6-Nano | ws-esp32c6:Waveshare-ESP32-C6-Zero

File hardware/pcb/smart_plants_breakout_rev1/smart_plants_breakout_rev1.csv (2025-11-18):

Reference | Qty | Value | DNP | Exclude from BOM | Exclude from Board | Footprint | Datasheet
C1 | 1 | 100nF |  |  |  | Capacitor_THT:C_Disc_D3.0mm_W1.6mm_P2.50mm | ~
C2 | 1 | 470µF |  |  |  | Capacitor_THT:CP_Radial_D8.0mm_P3.50mm | ~
D1 | 1 | 1N4001 |  |  |  | Diode_THT:D_DO-41_SOD81_P10.16mm_Horizontal | http://www.vishay.com/docs/88503/1n4001.pdf
J1,J2 | 2 | Conn_01x07_Pin |  |  |  | Connector_PinHeader_2.54mm:PinHeader_1x07_P2.54mm_Vertical | ~
J3,J4,J5,J6 | 4 | Conn_01x04_Pin |  |  |  | Connector_JST:JST_XH_B4B-XH-A_1x04_P2.50mm_Vertical | ~
J7,J8,J10 | 3 | Conn_01x02_Pin |  |  |  | Connector_JST:JST_XH_B2B-XH-A_1x02_P2.50mm_Vertical | ~
J9 | 1 | Conn_01x03_Pin |  |  |  | Connector_JST:JST_XH_B3B-XH-A_1x03_P2.50mm_Vertical | ~
Q1 | 1 | Q_NMOS_GDS |  |  |  | Package_TO_SOT_THT:TO-220-3_Vertical | ~
R1,R2 | 2 | 220k |  |  |  | Resistor_THT:R_Axial_DIN0207_L6.3mm_D2.5mm_P10.16mm_Horizontal | ~
R3 | 1 | 10k |  |  |  | Resistor_THT:R_Axial_DIN0207_L6.3mm_D2.5mm_P10.16mm_Horizontal | ~
R4 | 1 | 22R |  |  |  | Resistor_THT:R_Axial_DIN0207_L6.3mm_D2.5mm_P10.16mm_Horizontal | ~
R5,R6,R7,R8,R9,R10,R11,R12 | 8 | 4k7 |  |  |  | Resistor_THT:R_Axial_DIN0207_L6.3mm_D2.5mm_P10.16mm_Horizontal | ~
SW1 | 1 | SW_SPST |  |  |  | Connector_JST:JST_XH_B2B-XH-A_1x02_P2.50mm_Vertical | ~
U1 | 1 | XIAO-ESP32-C6 |  |  |  | XIAO ESP32 Family:XIAO-ESP32C6-DIP

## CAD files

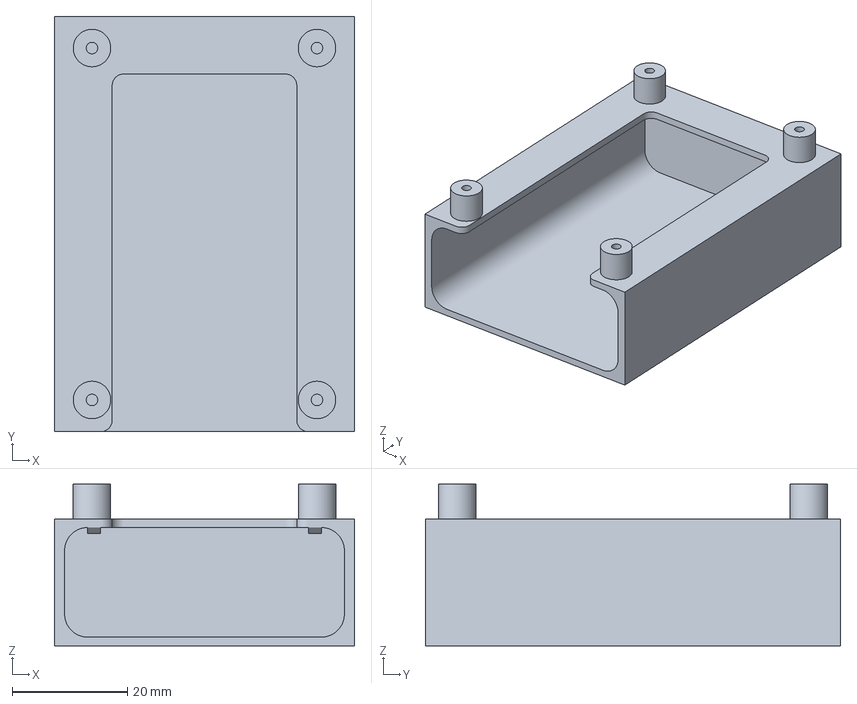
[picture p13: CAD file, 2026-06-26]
hardware/3d-print/battery_pcb_mount/battery_case-Body6.3mf
52.0 x 72.0 x 28.0 mm

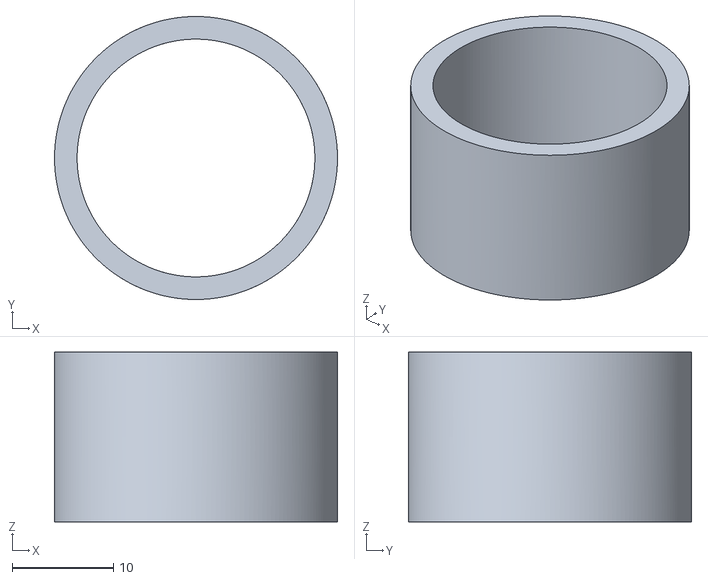
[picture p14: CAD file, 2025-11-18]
hardware/3d-print/bme_housing/tube_scaled.stl
28.0 x 28.0 x 16.8

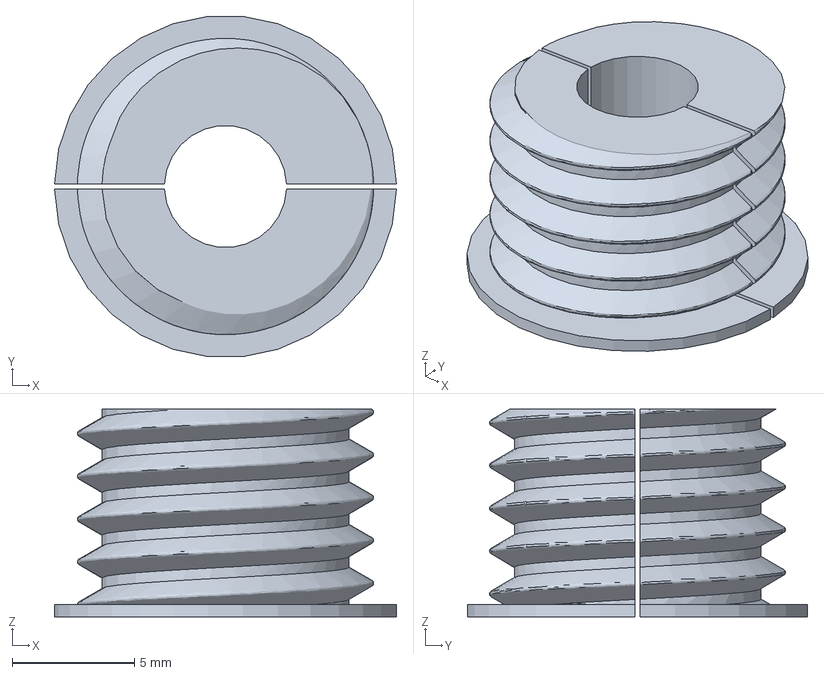
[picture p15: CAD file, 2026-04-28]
hardware/3d-print/cable_plugs/cable_plug_m12.3mf
14.0 x 13.9 x 8.50 mm

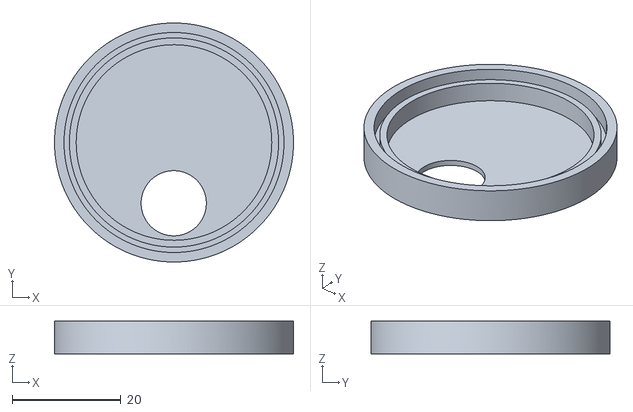
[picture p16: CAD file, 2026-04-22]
hardware/3d-print/light_sensor/light_sensor_bottom.stl
44.0 x 44.0 x 6.00

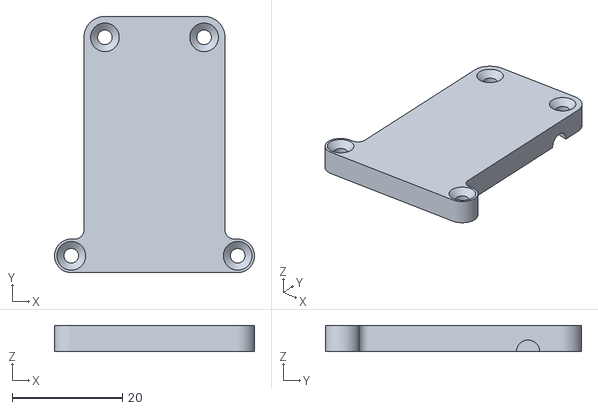
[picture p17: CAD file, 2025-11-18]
hardware/3d-print/moisture_sensor/moisture_sensor_lid.stl
36.3 x 46.5 x 4.80

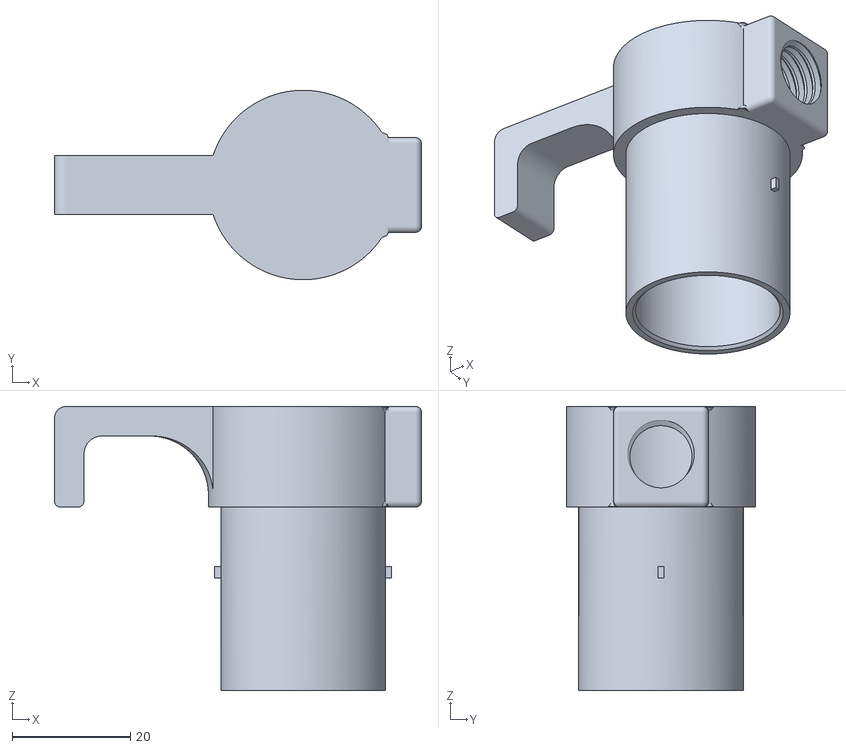
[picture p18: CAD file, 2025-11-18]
hardware/3d-print/pump/pump_housing-Top_large.obj
62.0 x 32.0 x 48.0

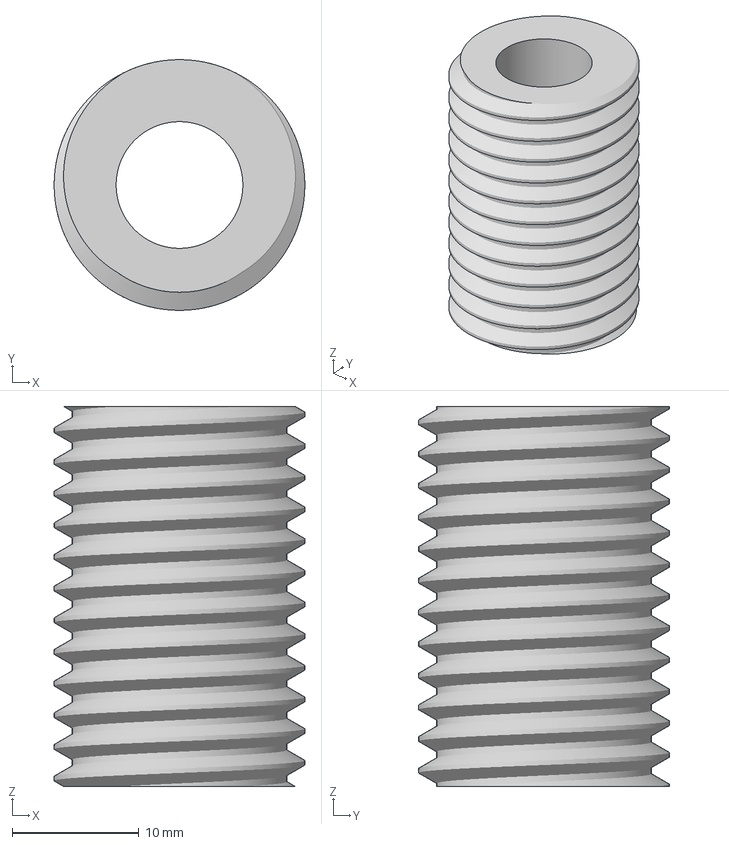
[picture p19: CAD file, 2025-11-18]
hardware/3d-print/src/thread.3mf
19.8 x 19.8 x 30.0 mm

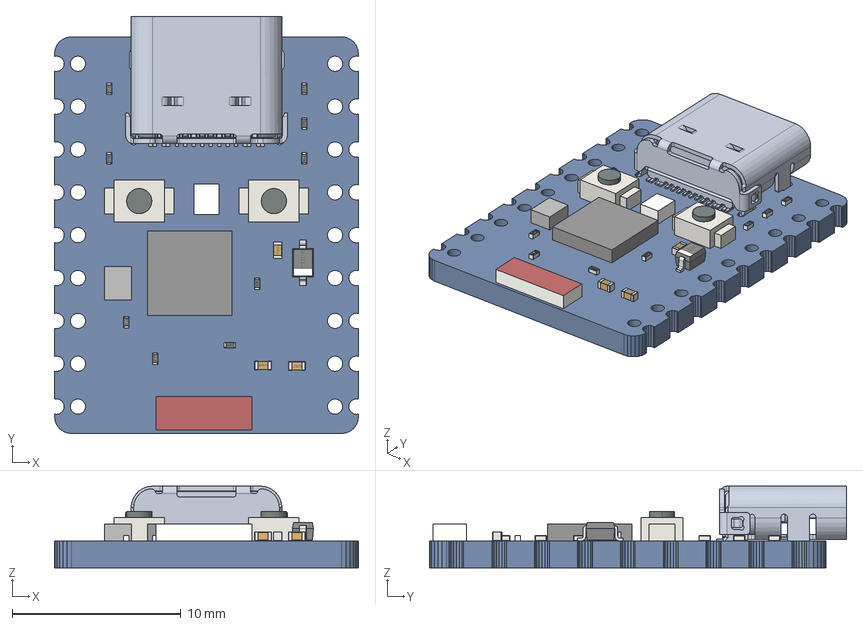
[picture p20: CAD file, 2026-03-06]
hardware/pcb/ext_files/Waveshare-ESP32-C6-Zero.step
18.0 x 24.7 x 4.85 mm
BOARD
USER_LIBRARY-RES_0603-0201_1 x 9
USER_LIBRARY-RES_0603-0201_2 x 9
USER_LIBRARY-RES_0603-0201_3 x 9
USER_LIBRARY-RES_0603-0201_4 x 9
EXTRUDED-29178
2_A x 13
EXTRUDED-51780
EXTRUDED-52493 x 2
SOD323
3_1_A x 3
CORE
CA-C03

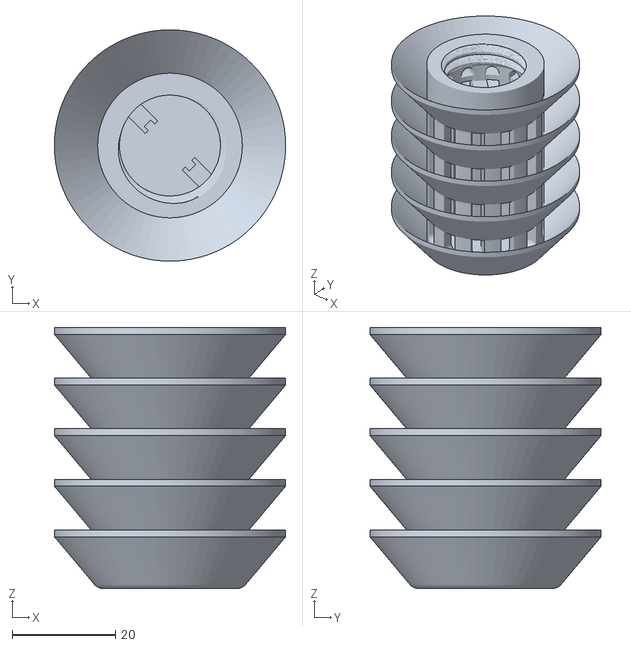
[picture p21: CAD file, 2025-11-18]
hardware/3d-print/bme_housing/stevenson_hat_scaled.stl
44.8 x 44.8 x 50.6

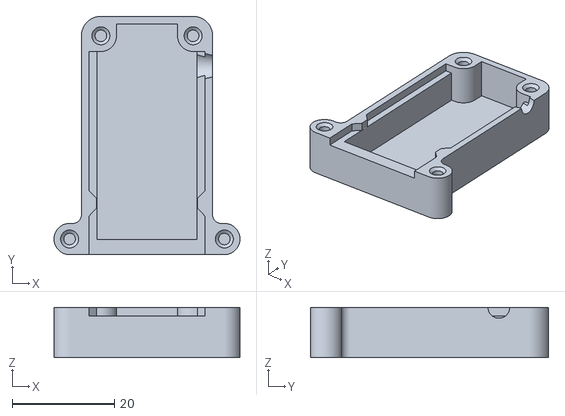
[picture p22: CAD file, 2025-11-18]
hardware/3d-print/moisture_sensor/moisture_sensor_housing.stl
36.3 x 46.5 x 9.80

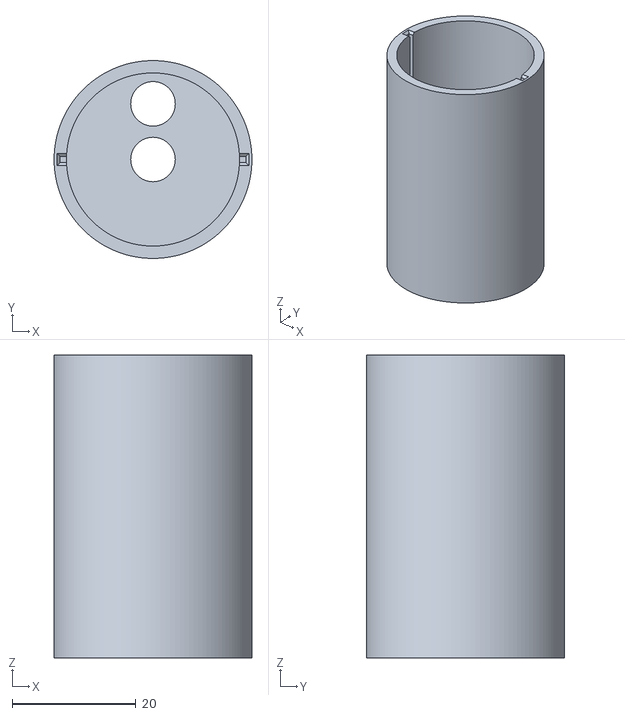
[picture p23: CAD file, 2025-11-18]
hardware/3d-print/pump/pump_housing-Bottom.obj
32.0 x 32.0 x 49.0

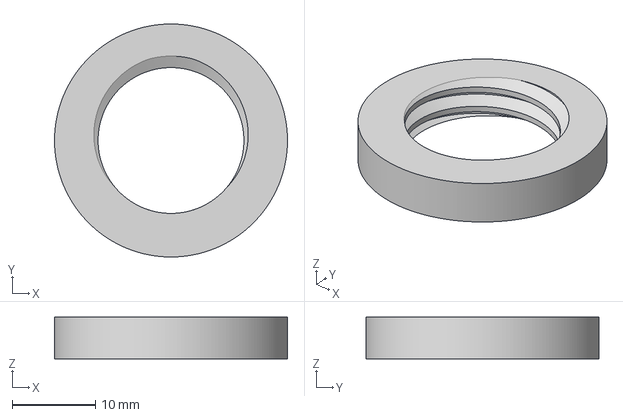
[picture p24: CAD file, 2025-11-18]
hardware/3d-print/src/ring_smaller.3mf
28.0 x 28.0 x 5.00 mm

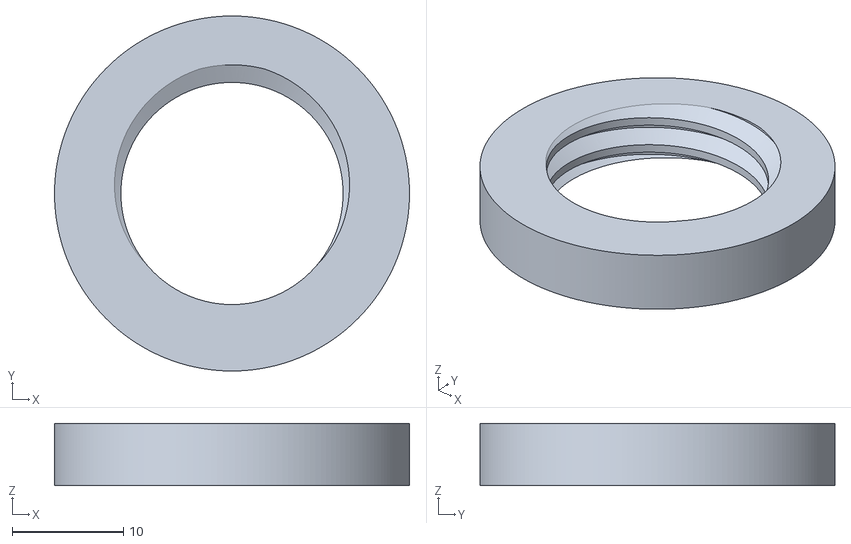
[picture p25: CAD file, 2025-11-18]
hardware/3d-print/bme_housing/ring_smaller_scaled.stl
31.9 x 31.9 x 5.60

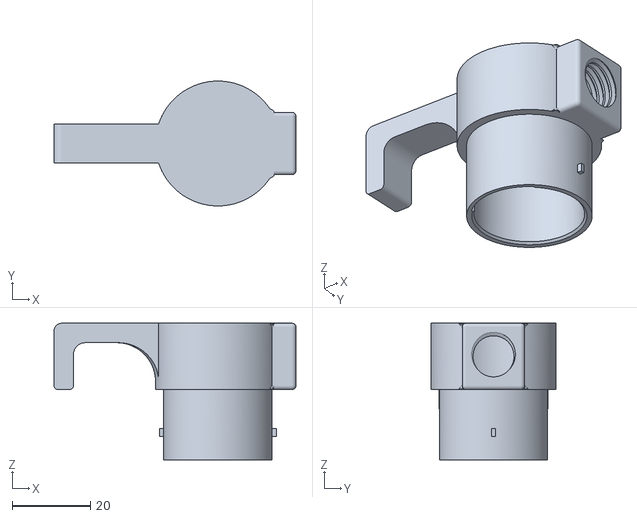
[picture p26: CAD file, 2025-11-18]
hardware/3d-print/pump/pump_housing-Top.obj
62.0 x 32.0 x 35.0

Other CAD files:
hardware/3d-print/src/light_sensor_bottom.3mf
hardware/3d-print/bme_housing/thread_scaled.stl
hardware/3d-print/pump/pump_housing-Bottom_large.obj
hardware/3d-print/src/ring.3mf
hardware/3d-print/cable_plugs/cable_plug_nut_m12.stl
hardware/3d-print/src/tube.3mf

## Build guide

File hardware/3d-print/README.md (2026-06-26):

# 3D-Printed Parts

All parts can be printed in PLA. No supports needed unless otherwise noted.

## Parts by folder

| Folder | Parts | Used for |
|---|---|---|
| `battery_pcb_mount/` | `battery_case-Body6.3mf` | Battery housing and mount for the PCB |
| `moisture_sensor/` | `moisture_sensor_housing.stl`, `moisture_sensor_lid.stl` | Enclosure for the capacitive soil moisture sensor |
| `bme_housing/` | `ring_smaller_scaled.stl`, `stevenson_hat_scaled.stl`, `thread_scaled.stl`, `tube_scaled.stl` | Stevenson screen — protects the BME280 from direct sun/rain while allowing airflow |
| `light_sensor/` | `light_sensor_bottom.stl` | Mount for the TSL2591 light sensor |
| `pump/` | `pump_housing-Bottom.obj`, `pump_housing-Top.obj` | Housing for the diaphragm pump (`_large` variants for wider pumps) |
| `cable_plugs/` | `a8-i48-t3_cable_plug-Body.obj`, etc. | JST/Dupont cable strain-relief plugs |
| `src/` | `.3mf` files | Editable source files for the models above (open in PrusaSlicer / Bambu Studio) |

## Attribution

- Moisture sensor housing adapted from:
  https://www.printables.com/model/247398-capacitive-soil-moisture-sensor-v20-cover
- Stevenson screen adapted from:
  https://www.printables.com/model/411004-compact-stevenson-screen

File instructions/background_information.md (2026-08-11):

# Background Information

## Sensor Choice
### Soil Moisture Sensors
#### Overview

| Sensor Type | Measurement Principle | Advantages | Limitations |
|---|---|---|---|
| Capacitive | Measures dielectric constant of the soil | Durable, accurate | Sensitive to nearby objects and interference |
| Resistive | Measures electrical resistance | Cheap, easy to use | Corrodes over time (potentially toxic) |

In addition to resistive and capacitive sensors, there are more advanced methods used in agriculture and research, such as tensiometers, Time Domain Reflectometry or Frequency Domain Reflectometry TDR/FDR sensors, and thermal or capillary-based systems. These offer higher accuracy or different measurement principles (like soil water tension) but are often more complex or expensive.

#### DIY Sensors

Tension Sensors (e.g. Tensiometer, Capillary Sensor)
- Measure how tightly water is held in the soil.
- Simulate what plants "feel" when extracting water.
- Use porous ceramic tips and water-filled tubes to show suction or pressure changes.
- analog output but requires pressure sensor to read electronically -> fun but complex to integrate.

Resistive Sensors (e.g. Nail Electrodes, Gypsum Block)
- Measure electrical resistance between two conductors.
- Moist soil conducts better, dry soil worse (but soil type/quality has an impact too!).
- Simple to build with nails, wires, or embedded in gypsum for more stability.
- analog output (voltage) which is very easy to read with microcontrollers -> simple and easy to integrate.

Tensiometers provide more biologically meaningful data, but are harder to read electronically. Resistive sensors are easier to connect and automate, making them ideal for basic watering systems.

#### Workshop Sensor Choice

For this workshop I recommend using the an off-the-shelf capacitive sensor. They are are more stable and durable than resistive ones. They don’t corrode as quickly, provide smoother readings, and are widely available as well as affordable. This makes them ideal for beginner projects and long-term use in automated watering systems. There are standard sensors that are sold by various shops (see image below). However, they are often faulty. Check this video before you buy some: [Capacitive Soil Moisture Sensors don't work correctly + Fix for v2.0 v1.2 Arduino ESP32 Raspberry Pi](https://www.youtube.com/watch?app=desktop&v=IGP38bz-K48)



### Environmental Sensors (Temperature, Humidity, Pressure)

#### Overview

| Sensor | Measures | Interface | Advantages | Limitations |
|---|---|---|---|---|
| DHT11 / DHT22 | Temperature, humidity | 1-Wire | Cheap, very common in tutorials | Slow (1 reading/sec), low accuracy |
| SHT31 / SHT40 | Temperature, humidity | I2C | High accuracy, fast, compact | Slightly more expensive |
| BMP280 | Temperature, pressure | I2C / SPI | Compact, low power | No humidity |
| **BME280** | **Temperature, humidity, pressure** | **I2C / SPI** | **All-in-one, accurate, low power, well-supported** | **Sensitive to self-heating if powered continuously** |

#### Background

Temperature and humidity sensors are used in countless IoT projects. The main trade-offs are accuracy, update speed, and what quantities they measure. Simple sensors like the DHT11 are popular in beginner tutorials due to their low cost, but they are slow and imprecise. More modern I2C sensors are generally faster, more accurate, and easier to wire since they share the bus with other components.

Pressure adds another useful dimension: it reflects altitude, weather trends, and — in indoor setups — rough air quality changes. Few sensors combine all three at a good price point.

#### Workshop Sensor Choice

For this project we use the **Bosch BME280**. It measures temperature, relative humidity, and barometric pressure in a single compact package. It communicates over I2C (address `0x76` on this PCB), is well-supported by the Adafruit BME280 library, and draws very little current in forced mode — important for a battery-powered device.

One caveat: the BME280 is sensitive to heat from nearby components. The PCB isolates the sensor from the microcontroller, and the 3D-printed miniature Stevenson screen in `hardware/3d-print/bme_housing/` illustrates the principle of shielding a sensor from direct sunlight and rain while allowing airflow. At this scale it has a limited practical effect, but it is a good way to understand why professional weather stations use the same concept at a much larger scale.

---

### Light Sensors

#### Overview

| Sensor | Measurement | Interface | Dynamic Range | Advantages | Limitations |
|---|---|---|---|---|---|
| LDR (photoresistor) | Relative light level | Analog  | Low | Extremely cheap, no library needed | Not calibrated, non-linear response |
| BH1750 | Lux | I2C | 1 – 65535 lux | Simple, calibrated lux output | Saturates in direct sunlight |
| VEML7700 | Lux, white channel | I2C | 0.0036 – 120000 lux  | Very wide range, low power | Slower at high gain settings |
| **TSL2591** | **Lux, IR, full spectrum** | **I2C** | **188 μlux – 88000 lux** | **Extremely wide dynamic range, separate IR channel** | **Can saturate in direct noon sun** |

#### Background

Light is a key factor in plant health, but the range of light intensities that matter spans many orders of magnitude — from a dimly lit indoor shelf (~50 lux) to bright outdoor sun (~100 000 lux). Simple sensors like LDRs give a rough relative reading but are not calibrated to any physical unit. Calibrated lux sensors give more meaningful data that can be compared across devices and locations.

The separate IR channel available on some sensors is particularly useful: plants respond mainly to visible light (photosynthetically active radiation), while IR is absorbed less. Comparing the full-spectrum and IR channels gives a rough estimate of the visible component.

#### Workshop Sensor Choice

For this project we use the **AMS TSL2591**. Its extremely wide dynamic range makes it useful both indoors and outdoors without needing to change settings. It exposes both a full-spectrum channel and a separate IR channel over I2C, which the firmware uses to calculate lux and log raw channel values for later analysis.

The sensor is housed in the small mount in `hardware/3d-print/light_sensor/` to shield it from direct contact while keeping it exposed to ambient light. A half ping-pong ball glued over the sensor acts as a diffuser: it scatters incoming light so the sensor integrates illumination from a wide angle rather than a narrow beam. This makes readings less sensitive to the exact orientation of the device and prevents direct sunlight from saturating the sensor from a single direction — the same principle used in professional lux meters and pyranometers.

---

### Pump Systems

| Pump Type | Working Principle | Advantages | Suitable For |
|---|---|---|---|
| Submersible Pump  | Impeller submerged in water reservoir | High flow rate, robust | Raised beds, greenhouses |
| Diaphragm Pump | Oscillating membrane creates pressure/vacuum  | Stable pressure, self-priming | Distributed watering systems |
| Peristaltic Pump  | Fluid pushed through flexible tube by rollers | Precise dosage, no backflow | Potted plants, indoor setups |

For this workshop, we will use a diaphragm pump. They are reliable, self-priming, and can handle small amounts of water with consistent pressure. They work well in compact systems and are easy to control with a relay or MOSFET. Their sealed design also makes them less prone to leaking or clogging — perfect for small-scale automated irrigation projects.

### Controlling the Pump

Microcontrollers like ESP32 or Arduinos cannot power pumps directly. You need an electronic switch that can handle higher current. There are two common ways to do this: Using a relay or a MOSFET.

| Feature | Relay Module | MOSFET Module |
|---|---|---|
| Switching type | Mechanical (electromagnetic switch) | Electronic (transistor-based) |
| Sound | Audible “click” when switching | Silent |
| Speed | Slow switching (ms range) | Fast switching (μs range), suitable for PWM |
| Load types | Good for AC and DC | Typically used for DC only |
| Efficiency | Some power loss (mechanical contact) | High efficiency, low heat generation |
| Use case example | Simple on/off pump control | Precise or PWM pump control (e.g. speed) |
| Complexity | Easy to wire and understand | Requires correct polarity and pin setup |

For this workshop, we will use a MOSFET (IRLZ14). This logic-level MOSFET can be triggered directly from a microcontroller (e.g. Arduino or micro:bit) and is capable of switching up to 60 V DC and 10 A — more than enough for most small pumps or valves. It's silent, efficient, and ideal for low-voltage DC systems.
While the pumps used in this setup typically draw far less current (around 500 mA), using a higher-rated MOSFET gives us more flexibility. It ensures that the same circuit can also be used safely with larger pumps or other components in future projects.

(Wiring example check [here](https://learn.adafruit.com/rgb-led-strips/usage)) 

NOTE: Microcontroller AND MOSFET/Pump Power Source MUST HAVE THE SAME GROUND!!

## How the System Works

### The Firmware

The code running on the microcontroller follows the same cycle every time the device wakes up:

1. **Wake up** — the ESP32 wakes from deep sleep on a timer (default: every hour). Deep sleep draws less than 10 µA, which is why the batteries last weeks instead of hours.
2. **Read sensors** — moisture, battery voltage, temperature, humidity, air pressure, and light level are all read in sequence.
3. **Connect to Wi-Fi** — the device connects to the saved Wi-Fi network. If no network is saved yet, it opens a temporary access point so you can enter your credentials.
4. **Send data** — the readings are packaged as a JSON message and sent to the API server over HTTPS.
5. **Go back to sleep** — Wi-Fi is switched off and the chip enters deep sleep until the next cycle.

The code lives in `code/sp_modular/`. The main file (`sp_modular.ino`) ties the modules together; everything you need to configure is in `config.h`.

### Sending Data — What is an API?

An **API** (Application Programming Interface) is a defined way for two programs to talk to each other. In this project, the device acts as a *client* that sends data, and a server receives it.

Each time the device wakes up, it sends a small **JSON** message — a structured text format that both machines and humans can read — that looks roughly like this:

```json
{
  "name": "my-plant",
  "device_id": "smartplant-a1b2c3d4",
  "project": "workshop-2026",
  "sensors": {
    "moisture": { "value": 62.3, "unit": "%" },
    "temperature": { "value": 21.4, "unit": "C" },
    "battery_voltage": { "value": 4.1, "unit": "V" }
  }
}
```

This message is sent using **HTTP POST** — the same protocol your browser uses when you submit a form on a website. The server checks the API key in the request header to confirm the device is authorised, then stores the reading.

### The Server

The server runs a **FastAPI** service at `diy-sensor.org`. FastAPI is a modern Python web framework designed for building APIs quickly. When it receives a reading from your device, it validates the data and writes it to an **SQLite** database. Every measurement from every device in the workshop is stored there, identified by the device ID (generated automatically from the board's chip ID — see the portal home page). The optional `project` field lets the dashboard group a whole class's devices together. The database schema is generic — one row per (device, sensor, time) — so any sensor a device reports shows up on the dashboard without server-side changes.

### The Dashboard

The readings are visualised on a dashboard that builds itself from the data: every sensor a device reports becomes a chart. Your plant's page is at `https://diy-sensor.org/dashboard/device/<device-id>` (the device ID is shown at the top of the setup portal), and if you set a **project**, the whole class's devices are overlaid at `https://diy-sensor.org/dashboard/project/<project>`.

```
[Device]
   │  wakes up, reads sensors
   │  sends JSON over HTTPS
   ▼
[FastAPI server]
   │  validates API key
   │  stores reading
   ▼
[PostgreSQL database]
   │  queried by Grafana
   ▼
[Grafana dashboard]
   │  shows live + historical data
   ▼
[You]
```

---

## Similar Projects

### Self-Watering Flower Pot "Flaura"
This 3D-printable self-watering flower pot project integrates a soil moisture sensor, a microcontroller (ESP8266), and a small water pump to automate plant care. It also includes a mobile app interface using Blynk, allowing users to monitor soil moisture and trigger manual watering remotely.

https://www.thingiverse.com/thing:4921885

### Watering System without microcontroller
This project builds a simple automatic plant watering system without using a microcontroller. It uses soil probes to detect moisture, a BC547 transistor to trigger a relay, and a small water pump. When the soil is dry, the pump automatically turns on; when the soil is wet, it turns off. It's a low-cost solution with no programming required.

https://circuitdigest.com/electronic-circuits/automatic-plant-watering-system-without-arduino

### Elecrow Smart Plant

A compact IoT plant monitor built around an ESP32‑S2 microcontroller, featuring a built‑in capacitive soil moisture probe, ambient light and air temperature/humidity sensors, and an optional 2.9″ e‑paper display for live data. It streams data over Wi‑Fi (compatible with Home Assistant via ESPHome) and is ideal for visualizing plant health, though it does not include a pump or watering system

https://www.elecrow.com/smart-plant.html

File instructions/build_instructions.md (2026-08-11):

# Build Instructions — Waveshare ESP32-C6 Zero + PCB

This guide covers the **main workshop build**: the Waveshare ESP32-C6 Zero on the
`smart_plants_breakout_ws-board_rev2` PCB powered by 3 AA batteries. All sensors (BME280, TSL2591) and the
pump circuit are integrated on the PCB — no breadboard or loose resistors needed.

---

> **Known issue — PCB rev2 silkscreen:** The moisture sensor power connector is labelled
> **"D1-powered"** on the board, but the correct GPIO is **21**. This is a labelling error
> on the PCB and does not affect functionality — just ignore the label and plug the connector
> in as shown in the instructions.

---

## 1. Collect All Parts

Get all parts together before you start. The PCB replaces the breadboard, jumper wires,
and discrete resistors from the old build.

> For a complete itemised parts list (including all PCB components, cables, and quantities),
> see the [Bill of Materials](bom.md) ([CSV version](bom.csv)).

**Electronics**
- Waveshare ESP32-C6 Zero microcontroller
- Smart Plants Breakout PCB (ws-board rev2) + all components
  - 2× 220 kΩ resistor (R1, R2 — battery voltage divider)
  - 1× 10 kΩ resistor (R3 — MOSFET gate pull-down)
  - 1× 22 Ω resistor (R4 — MOSFET gate protection)
  - 2× 4.7 kΩ resistor (R5, R6 — I2C pull-up)
  - 1× 1N4001 diode (D1 — flyback diode)
  - 1× 1N5817 Schottky diode (D2)
  - 1× 220 µF electrolytic capacitor (C2)
  - 1× 22 µF electrolytic capacitor (C3)
  - 1× IRLZ14 MOSFET (Q1)
  - 4× 4-pin JST XH connector (J3, J5, J6, J11 — I2C)
  - 1× 3-pin JST XH connector (J9 — moisture sensor)
  - 2× 2-pin JST XH connector (J7, SW1 — battery / switch)
  - 1× 2-pin JST XH connector (J10 — pump)
  - 1× 2-pin JST PH connector (J4 — USB-C power, 2.0 mm pitch)
  - 2× 9-pin pin socket (J1, J2 — microcontroller socket)
- Capacitive soil moisture sensor + 3-core cable
- BME280 sensor module (temperature, humidity, pressure) + pre-crimped 4-core cable
- TSL2591 sensor module (light) + pre-crimped 4-core cable
- Mini diaphragm pump + 2-core cable
- Battery pack (3× AA)
- USB-C connector with cable
- On/Off Switch

**Mechanical**
- 3D-printed battery housing and PCB mount
- 3D-printed moisture sensor housing + lid
- 3D-printed pump housing
- 3D-printed BME280 housing (Stevenson Screen)
- 3D-printed TSL2591 housing + half ping pong ball as diffusor
- 3D-printed cable plugs (2x)
- Laser-cut enclosure
- 12× wood screws
- Velcro tape
- PG7 cable gland (for pump cable)
- Tubes (pump inlet/outlet)

**Tools**
- Soldering iron + solder
- Crimping tool (for JST connectors)
- Wire cutters / flush cutters
- Wire strippers
- Screwdriver
- Hot-glue gun (or other glue)
- Drill with 8 mm bit (only needed if the housing cable hole is not pre-cut)

---

## 2. Prepare Parts

Several parts need preparation before assembly. These steps can be done in any order —
if a tool you need is in use, move on to another step.

### 2.1 Prepare the PCB

Solder all components on the PCB (suggested order below). Component orientation is indicated by the silkscreen markings. All components but the resistors are orientation sensitive!

| Reference | Component | Qty | Value | Notes |
|---|---|-----|---|---|
| R1, R2 | Resistor | 2 | 220 kΩ | Battery voltage divider |
| R3 | Resistor | 1 | 10 kΩ | MOSFET gate pull-down |
| R4 | Resistor | 1 | 22 Ω | MOSFET gate protection |
| R5, R6 | Resistor | 2 | 4.7 kΩ | I2C pull-up |
| D1 | Diode | 1 | 1N4001 | Flyback diode — stripe (cathode) faces pump + |
| D2 | Diode | 1 | 1N5817 | Schottky diode — stripe (cathode) per silkscreen |
| C2 | Capacitor | 1 | 220 µF | Electrolytic — long leg to + hole |
| C3 | Capacitor | 1 | 22 µF | Electrolytic — long leg to + hole |
| Q1 | MOSFET | 1 | IRLZ14 | Flat side matches silkscreen outline |
| J3, J5, J6, J11 | I2C JST connector | 4 | 4-pin JST XH | |
| J9 | Moisture sensor connector | 1 | 3-pin JST XH | |
| J7, SW1 | Battery / switch connector | 2 | 2-pin JST XH | |
| J10 | Pump connector | 1 | 2-pin JST XH | |
| J4 | USB-C power connector | 1 | 2-pin JST PH | Smaller pitch (2.0 mm) than the XH connectors |
| J1, J2 | Microcontroller socket | 2 | 9-pin pin socket | Solder to PCB; insert the Waveshare board after |

Resistors are not orientation-sensitive. All other components are — match the silkscreen carefully.

Suggested soldering order:
1. Resistors, Diodes
2. JST connectors. Tip: place all connectors, put a paper on it and try to flip the PCB holding all connectors in place with the paper. Solder the connector pins on the back
3. Microcontroller socket
4. Capacitors, Mosfet
5. optional: pin header to expose microcontroller pins

> **First time soldering?** Ask a workshop helper for a quick demo. A cold solder joint here will cause intermittent problems that are hard to debug later.

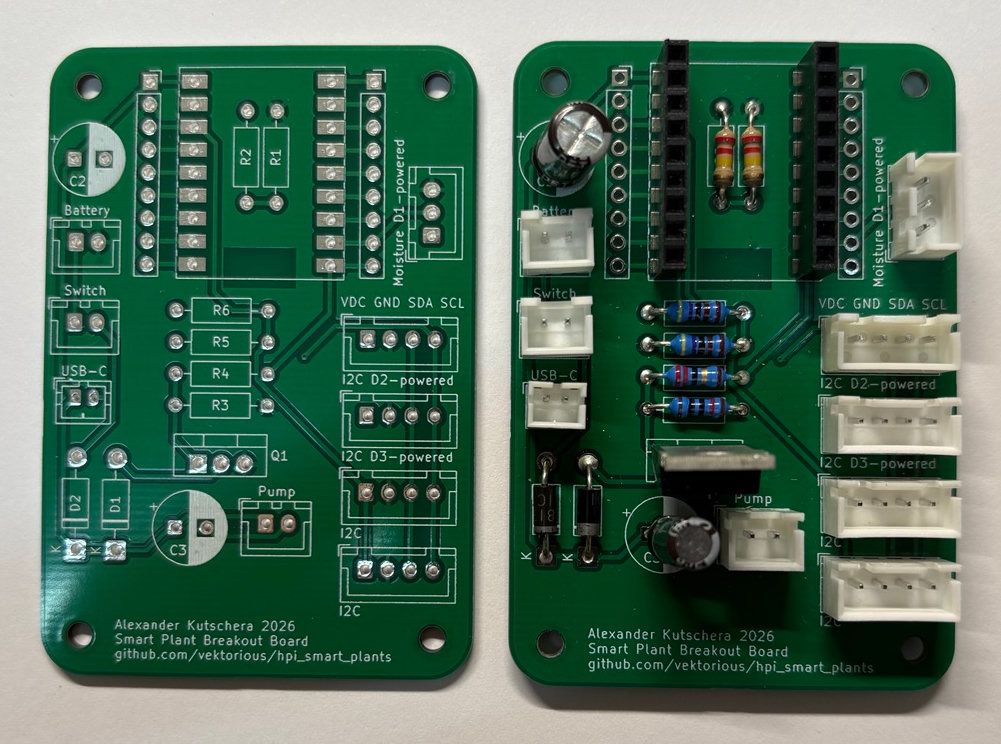
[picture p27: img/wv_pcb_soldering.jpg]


### 2.2 Crimp the Moisture Sensor Cable

The moisture sensor uses a custom cable with a JST connector on either side.

1. Cut the 3-core cable to your preferred length.
2. Crimp **3-pin JST PH** connectors on both ends.
3. Wire order: **GND (black) — VCC (red) — SIGNAL (yellow)** . This must match the sensor
   connector and the PCB header labels.

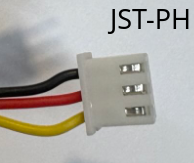
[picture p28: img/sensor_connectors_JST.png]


### 2.3 Assemble the Moisture Sensor

1. Discard the short cable that ships with the sensor — use the cable you just crimped.
2. Connect the sensor to the cable.
3. Insert the sensor into the 3D-printed housing and screw on the lid.
4. Push the cable jacket into the housing hole to seal it against dirt and moisture.

  

### 2.4 Prepare the Pump

1. Solder a two-core cable to the pump terminals.
2. Insert the pump into the 3D-printed pump housing.
3. Thread the cable through the housing hole, fit the PG7 cable gland, and screw it tight.
4. Crimp a **2-pin JST PH** connector on the free cable end.

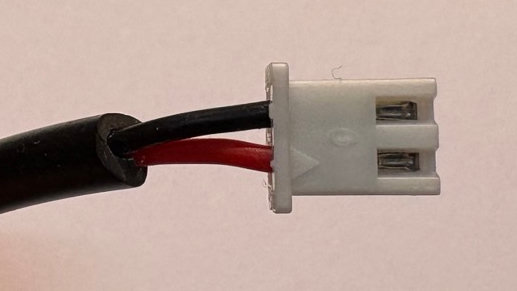
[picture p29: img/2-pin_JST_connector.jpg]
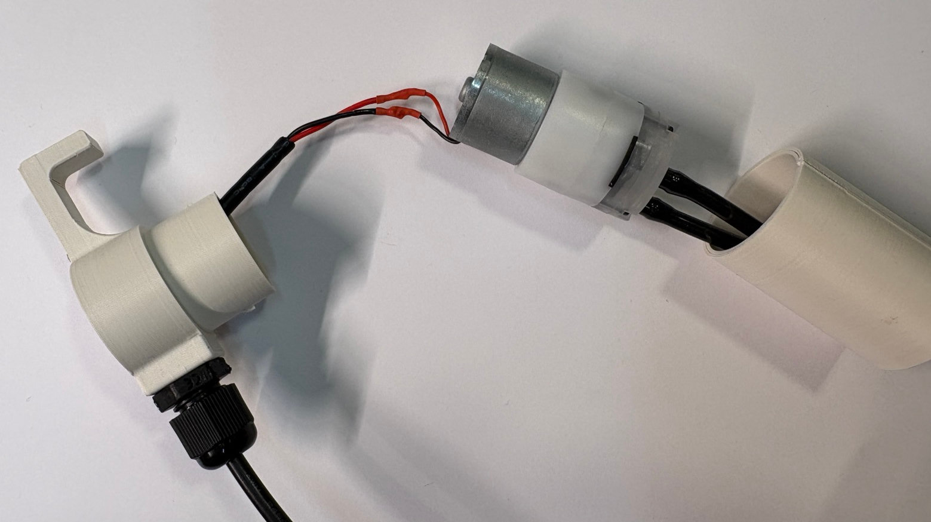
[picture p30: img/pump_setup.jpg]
 

### 2.5 Prepare the BME280 Sensor

1. Solder the pre-crimped cable to the sensor.
2. Wire order: **VCC (black) — GND (red) — SCL (yellow) — SDA (white)**
3. Insert the sensor into the 3D-printed mini Stevenson screen.
4. Thread the cable through the threaded tube and screw it into the Stevenson screen.

> **Note:** The black/red wire colours are swapped relative to convention — black is VCC and red is GND. This is a quirk of the pre-crimped cables. Double-check against the labels above before soldering.

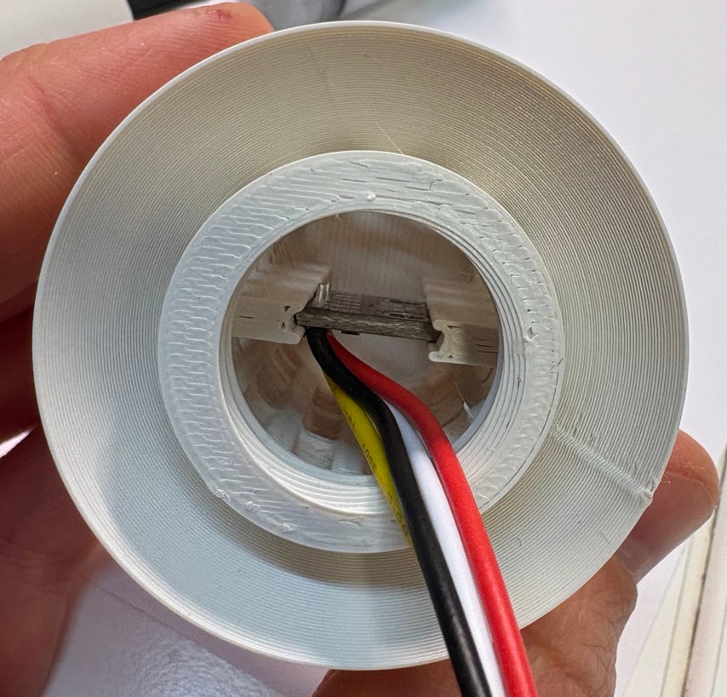
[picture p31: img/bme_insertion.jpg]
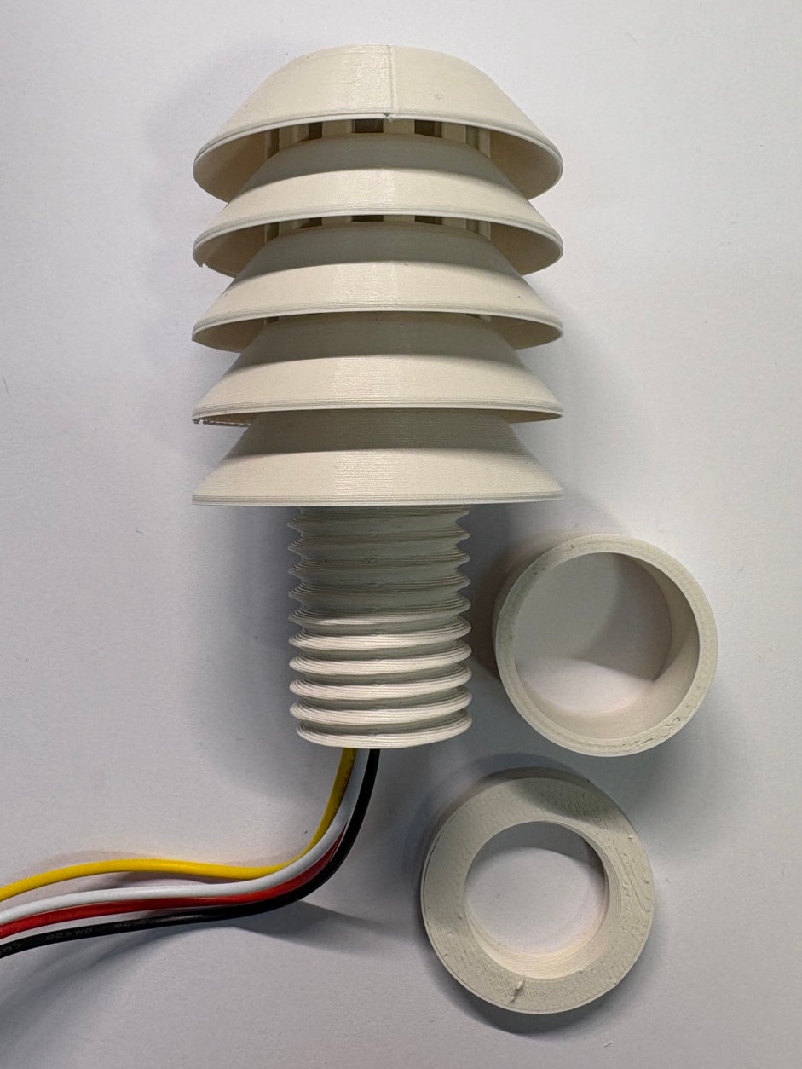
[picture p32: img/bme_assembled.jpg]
 

### 2.6 Prepare the TSL2591 Sensor

1. Solder the pre-crimped cable to the sensor. Wires should not be on the sensor side (see pictures).
2. Wire order: **VCC (black) — GND (red) — SCL (yellow) — SDA (white)**
3. Thread the cables through the housing bottom and hot-glue the sensor onto it. The sensor should face upwards.
4. Cut a ping-pong ball in half and glue it onto the sensor housing as a diffuser. It should fit tightly into the groove.

> **Note:** The black/red wire colours are swapped relative to convention — black is VCC and red is GND. This is a quirk of the pre-crimped cables. Double-check against the labels above before soldering.

The ping-pong ball half acts as a diffuser: it scatters incoming light so the sensor measures ambient light from a wide angle rather than a narrow beam from one direction. This makes readings less sensitive to the exact orientation of the housing and reduces the effect of direct sunlight hitting the sensor from a single spot. The same principle is used in professional lux meters and pyranometers.

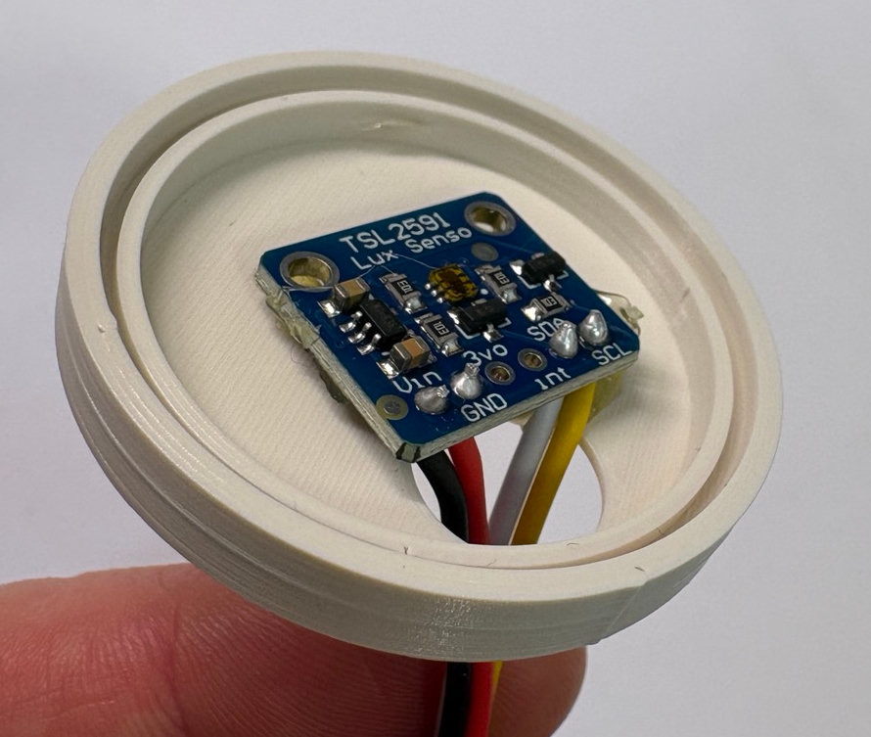
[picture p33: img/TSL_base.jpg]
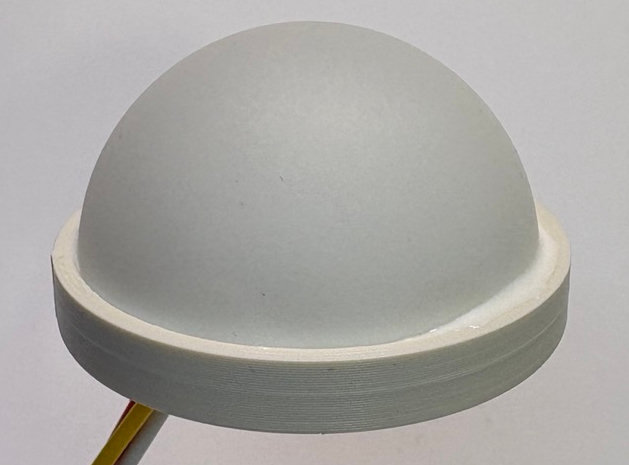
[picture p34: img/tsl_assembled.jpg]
 

### 2.7 Prepare the Switch

1. Solder two wires to the switch.
2. Add a 2-pin JST XH connector.
3. Wire order does not matter for a switch, but to stay consistent: VCC (black), GND (red).

### 2.8 Prepare the battery pack

1. Add a 2-pin JST XH connector to the battery cables.
2. Wire order: VCC (black), GND (red).

### 2.9 Assemble the Laser-Cut Enclosure

Assemble the housing panels before anything goes inside — it is much harder to add panels
after components are mounted.

1. Slot the side panels together. Add the small corner pieces **while joining the sides**,
   not after — they won't fit in later.
2. If the sensor cable hole is not pre-cut, drill one with an **8 mm bit**. For a tighter
   fit use 5 mm, but you may need to thread the cable before crimping.

---

## 3. Assembly

### 3.1 Mount Sensors to the Lid

1. BME280: slide the distance piece onto the threaded tube, insert it through the hole in the housing lid, and fix it with the locking piece on the other side.
2. Hot-glue the TSL2591 housing to the lid.

> Keep as much distance between the two sensors as possible — the Stevenson screen can otherwise cast a shadow on the TSL2591.

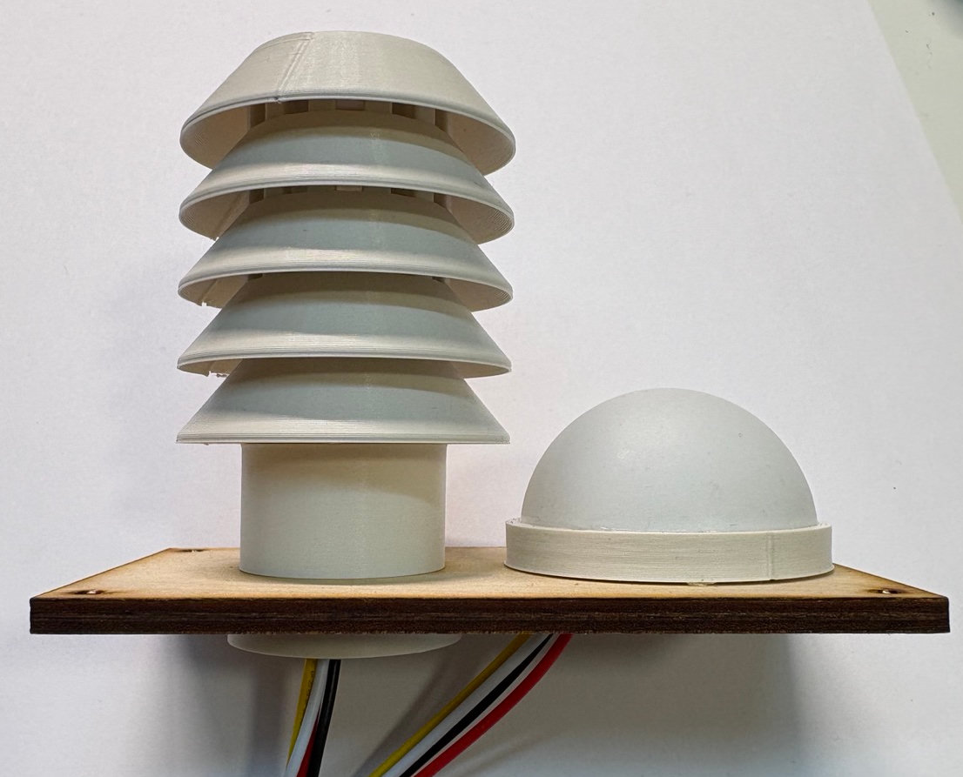
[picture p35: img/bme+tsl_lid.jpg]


### 3.2 Prepare the Housing

1. Insert the switch into the housing. Make sure it is switched off (flipped to the O-marked side).
2. Insert the USB-C connector into the housing.
3. Feed the pump and moisture sensor cables into the housing.
4. Optional: secure both cables using the 3D-printed cable plugs.

### 3.3 Add the PCB Mount

1. Insert the battery pack into the battery/PCB mount with the switch facing outward.
2. Screw the PCB to the PCB mount.
3. Insert the Waveshare microcontroller into the PCB socket.
4. Attach a small strip of velcro (~2 cm) to the bottom of the PCB mount and a matching strip inside the housing. Keeping it short makes it easier to remove later.
5. You can now fix the battery/PCB mount inside the housing — but wait until after programming. If you position the PCB mount close to the walls, you might be able to access the microcontroller for programming while inside the housing. Just try it. (Section 4).

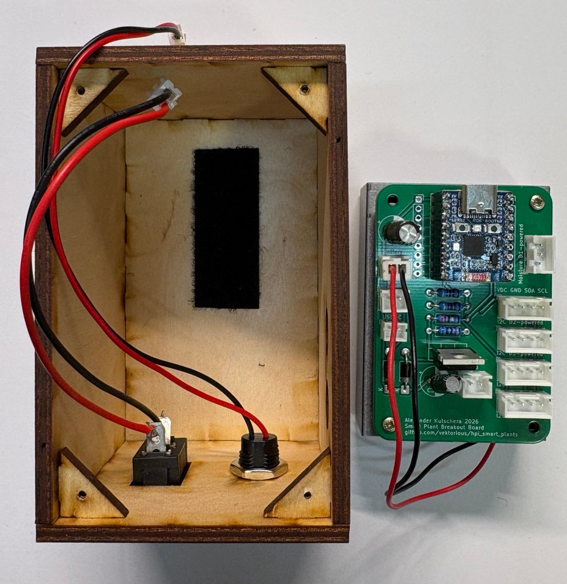
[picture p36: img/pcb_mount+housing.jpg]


### 3.4 Connect Components to the PCB

The PCB has labelled connectors for every component. Match the connector to its label on
the silkscreen. Connect the BME280 to "I2C D2-powered" and the TSL2591 to "I2C D3-powered".

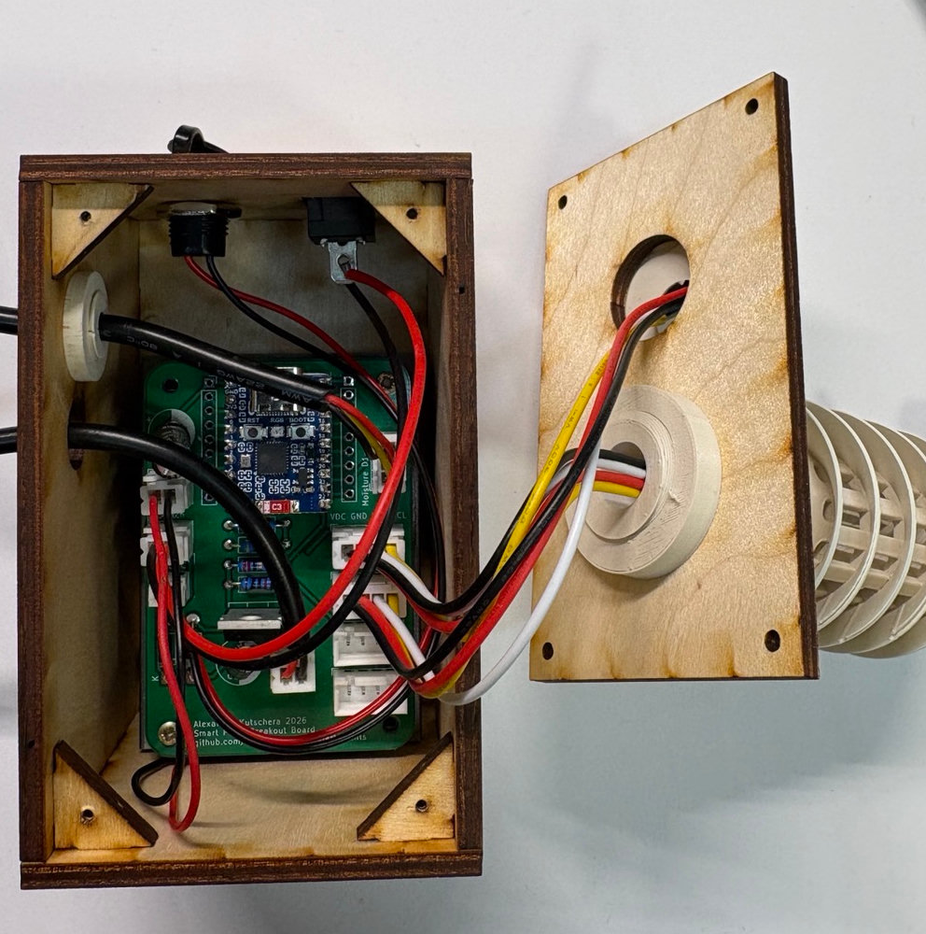
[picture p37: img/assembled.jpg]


---

## 4. Install & Configure the Firmware

You flash the firmware from your **browser** — no Arduino IDE or drivers needed — then configure
everything (Wi-Fi, sensors, calibration) on the device itself through a setup page. Nothing in the
code needs editing.

> Prefer to build and upload from source (to change the code, or if your browser isn't supported)?
> See [`firmware_from_source.md`](firmware_from_source.md), then come back to
> [4.2 Configure via the setup portal](#42-configure-via-the-setup-portal).

### 4.1 Flash the firmware (web flasher)

You'll need **Chrome, Edge, or Opera** on a desktop computer (Web Serial isn't in Firefox/Safari
or on phones) and a USB-C **data** cable.

1. **Put the board into flashing mode.** The firmware sleeps a few seconds after boot, which
   disconnects the USB port, so start it in its bootloader first:
   1. Unplug the board.
   2. Hold the **BOOT** button.
   3. Plug in the USB-C cable while still holding BOOT.
   4. Release BOOT after ~2 seconds.
2. Open the flasher page: **[vektorious.github.io/hpi_smart_plants](https://vektorious.github.io/hpi_smart_plants/)**.
3. Click **Connect**, choose the `USB JTAG/serial debug unit` port, then **Install Smart Plants
   Firmware** and wait for it to finish.
4. The board reboots automatically. Continue below.

### 4.2 Configure via the setup portal

On first boot the device has no Wi-Fi yet, so it opens its own temporary Wi-Fi access point.

1. On your phone or laptop, connect to the network named **`SmartPlant-XXXXXXXX-Setup`**
   (each board has a unique name/ID, so many students can set up side by side without clashing).
   No password required.
2. A setup page opens automatically (if not, browse to `http://192.168.4.1`).
3. Tap **Configure WiFi**, pick your network, and enter the password. You can also set:
   - **Device name** — change it to something friendlier for the dashboard if you like,
   - **Project** — an optional group name (e.g. `workshop-2026`) that clusters your class's
     devices together on the dashboard; leave it blank to stay ungrouped,
   - which **sensors / pump** are enabled (tick/untick),
   - **sleep interval**, **moisture calibration**, and **pump** thresholds.
   The **API key** is already filled in. Your **Device ID** — the board's permanent ID, derived
   from its chip (e.g. `smartplant-1a2b3c4d`) — is shown at the top of the setup menu, together with
   the dashboard link for your plant. It identifies your plant on the dashboard and **can't be
   changed**.
4. **Save.** The device connects to your Wi-Fi and keeps the setup page open so you can check it
   works (next step). The saved-confirmation page links you straight there.

> **Reopen the setup page later** (to change Wi-Fi or settings) by **pressing the reset button
> twice quickly** (a double-press). It also opens automatically whenever the saved Wi-Fi can't be
> found.

### 4.3 Check the sensors and test the connection

From the setup menu, open **Live Sensor Readings**:

- The values **refresh every 10 seconds** — gently breathe on the humidity sensor or shade the
  light sensor and watch them change.
- The **Wi-Fi badge** at the top turns green with your network name and IP once connected.
- If a sensor shows **"not detected"**, its cable or wire order is wrong — re-check the
  colour order from sections 2.5 / 2.6.
- Click **Send to API (test connection)**. A green **✓ 200 OK** confirms the whole chain works
  (Wi-Fi + API key + server). The very first send of a brand-new device answers **201** instead —
  that means the server just registered your device ID, and is equally fine. Anything else points
  at the Wi-Fi or key.

### 4.4 Finish

Click **Finish setup & start monitoring**. The device takes a measurement and begins its normal
cycle: wake every hour, read sensors, send data, sleep. Your device appears on the dashboard at
`https://diy-sensor.org/dashboard/device/<your-device-id>` — the link is printed under the Device
ID on the setup menu.

---

## 5. Troubleshooting

Most problems can be diagnosed right in the **Live Sensor Readings** page (section 4.3) — no extra
tools needed:

| Symptom | Likely cause / fix |
|---|---|
| Sensor shows **"not detected"** | Connector not fully seated, or wrong wire order — recheck sections 2.5 / 2.6. |
| **Moisture** stuck near 0 % or 100 % | Sensor cable not seated, or needs calibration (below). |
| **Send to API** not `200` | `Not connected to WiFi` → Wi-Fi wrong; other codes → wrong API key or server issue. |
| Wi-Fi badge stays red | Wrong password, or network out of range / 5 GHz-only (the ESP32-C6 needs 2.4 GHz). |
| No setup AP appears | Board is asleep — press reset twice, or power-cycle, to open the portal. |

### Calibrate the moisture sensor

The moisture-to-percent conversion uses a wet and a dry reference voltage that vary slightly per
sensor. On the **Live Sensor Readings** page, read the **moisture voltage**:

- **In open air** → this is your **dry** voltage (0 %). Enter it as *Moisture dry voltage*.
- **With only the metal prongs in water / saturated soil** → this is your **wet** voltage (100 %).
  Enter it as *Moisture wet voltage*.

Set both in the setup portal (double-press reset to reopen it) and **Save** — no reflash needed.

### Deeper component testing

For standalone test sketches (moisture, pump, I2C bus scan) and Serial-Monitor debugging, see
[`firmware_from_source.md` → Component test sketches](firmware_from_source.md#5-component-test-sketches-advanced-troubleshooting).

---

## 6. Final Test and Deployment

1. With the USB cable still connected, confirm data appears on the dashboard at
   `https://diy-sensor.org/dashboard/device/<your-device-id>`.
2. **Disconnect USB** and flip the power switch on.
3. The device should wake, connect to Wi-Fi, send a reading, and go back to sleep.
4. Confirm a new reading appears on the dashboard.

Once confirmed:

5. Fix the PCB mount inside the housing using the velcro strips.
6. Place the moisture sensor cable through the housing hole.
7. Screw on the lid.

> Switching the device off and on again triggers an immediate measurement — useful for
> testing without waiting an hour.

---

## What's Next?

Your device now measures soil moisture, temperature, humidity, light, and battery voltage,
and waters automatically when the soil gets too dry. All readings appear on the dashboard.

For background on how the sensors work and why certain design choices were made, see
[`background_information.md`](background_information.md).

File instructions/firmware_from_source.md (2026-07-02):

# Firmware from Source (Arduino IDE)

> **Most people should use the web flasher instead** — see
> [`build_instructions.md` → Install the Firmware](build_instructions.md#4-install--configure-the-firmware).
> It flashes the exact same firmware from the browser with no toolchain to install.

Use this guide only if you want to **build and upload the firmware yourself** — for example to
change the code, if your browser doesn't support the web flasher (only Chrome/Edge/Opera do), or
for advanced component testing with the sketches at the end.

All per-device settings (WiFi, device name, calibration, which sensors are enabled) are configured
at runtime in the setup portal after flashing — you do **not** need to edit the code for a normal
build. See [Configure via the setup portal](build_instructions.md#42-configure-via-the-setup-portal).

---

## 1. Install Arduino IDE and the ESP32 board package

1. Download and install [Arduino IDE](https://www.arduino.cc/en/software).
2. Open **File > Preferences** and add this URL to *Additional Boards Manager URLs*:
   `https://dl.espressif.com/dl/package_esp32_index.json`
3. Go to **Tools > Board > Boards Manager**, search for `esp32`, and install the
   **ESP32 by Espressif Systems** package.
4. Select board: **Tools > Board > ESP32 Arduino > Waveshare ESP32-C6-Zero**
   (or search for "ESP32-C6-Zero" in the board list).

## 2. Install the required libraries

In **Tools > Manage Libraries**, search for and install:

| Library | Author |
|---|---|
| WiFiManager | tzapu |
| Adafruit BME280 Library | Adafruit |
| Adafruit TSL2591 Library | Adafruit |
| Adafruit Unified Sensor | Adafruit |

> All sensor libraries are required even if you don't use every sensor — the firmware compiles
> all sensor code in and enables/disables each one at runtime. When installing the Adafruit BME280
> or TSL2591 libraries, click **Install All** if asked about dependencies.



## 3. Set the partition scheme

**Tools > Partition Scheme > "Huge APP (3MB No OTA/1MB SPIFFS)".**

This is required — the firmware does not fit the default partition. If you leave it on the
default you'll get a "text section exceeds available space" / "sketch too big" error.

## 4. Upload

1. Open `code/sp_modular/sp_modular.ino` in Arduino IDE.
2. (Optional) Open `code/sp_modular/config.h` if you want to change the **factory defaults** —
   e.g. the device-name prefix or default calibration. These only apply on first boot or after a
   factory reset; a configured device keeps whatever you set in the portal. You do **not** need to
   touch this file for a normal build.
3. Connect the Waveshare board via USB-C, select **Tools > Port**, and click **Upload**.

> **Upload fails?** The board may be in deep sleep from the running firmware, which disconnects
> the USB port. Put it into flashing mode:
> 1. Unplug the board.
> 2. Hold the **BOOT** button.
> 3. Plug back in while holding BOOT.
> 4. Release after ~2 seconds, then retry Upload.

After uploading, continue with
[Configure via the setup portal](build_instructions.md#42-configure-via-the-setup-portal).

### Building a web-flasher image (optional)

The ESP32 core also emits a single merged image at `sp_modular.ino.merged.bin` (in the
Export-Compiled-Binary output). That's what the web flasher serves — see
[`../web-flasher/README.md`](../web-flasher/README.md) for details.

---

## 5. Component test sketches (advanced troubleshooting)

For a quick "is this sensor alive?" check you normally don't need these — use the **Live Sensor
Readings** page in the portal instead. These standalone sketches are for deeper debugging: upload
each separately and open the **Serial Monitor** at **115200 baud**.

### 5.1 Test the moisture sensor

```cpp
const int moisturePin   = 1;   // GPIO 1 (A1) on Waveshare
const int moisturePower = 21;  // GPIO 21 — sensor power gate

const float minMoistureVoltage = 0.60;
const float maxMoistureVoltage = 2.45;

float readMoistureVoltage() {
  uint32_t sum = 0;
  for (int i = 0; i < 16; i++) sum += analogReadMilliVolts(moisturePin);
  return sum / 16.0 / 1000.0;
}

float moistureVoltageToPercent(float v) {
  return constrain((maxMoistureVoltage - v) /
    (maxMoistureVoltage - minMoistureVoltage) * 100.0, 0.0, 100.0);
}

void setup() {
  Serial.begin(115200);
  delay(1000);
}

void loop() {
  pinMode(moisturePower, OUTPUT);
  digitalWrite(moisturePower, HIGH);
  delay(200);

  float v = readMoistureVoltage();
  Serial.printf("Voltage: %.3f V  |  Moisture: %.1f %%\n", v, moistureVoltageToPercent(v));

  digitalWrite(moisturePower, LOW);
  delay(5000);
}
```

You should see a reading every 5 seconds. The voltage decreases as the soil gets wetter.
If you see a constant value near 0 V or 3.3 V, check that the sensor cable is fully seated.

### 5.2 Calibrate the moisture sensor

You can calibrate straight from the portal's **Live Sensor Readings** page — read the moisture
voltage in the two states below and enter them into the portal's *Moisture wet/dry voltage*
fields. To do it from this sketch instead:

**Dry (= 0 % moisture):** hold the sensor in open air — this voltage is `MAX_MOIST_V` (dry).
**Wet (= 100 % moisture):** put only the metal prongs into water or saturated soil — this
voltage is `MIN_MOIST_V` (wet).

Enter both values in the setup portal (they're saved per device), or, if building from source,
update the `DEFAULT_MIN_MOIST_V` / `DEFAULT_MAX_MOIST_V` defaults in `code/sp_modular/config.h`.

### 5.3 Test the pump

```cpp
const int PIN_PUMP = 22;  // GPIO 22 on Waveshare

void setup() {
  Serial.begin(115200);
  delay(1000);
  pinMode(PIN_PUMP, OUTPUT);

  Serial.println("Pump ON for 2 seconds...");
  digitalWrite(PIN_PUMP, HIGH);
  delay(2000);
  digitalWrite(PIN_PUMP, LOW);
  Serial.println("Pump OFF.");
}

void loop() {}
```

You should hear the pump run and see water flow through the tube. If nothing happens,
check that the pump connector is fully seated and that the power supply can deliver
enough current (USB power alone may be insufficient — use batteries).

### 5.4 Test the I2C sensors (BME280 + TSL2591)

This sketch scans the I2C bus and reads both sensors. Expected I2C addresses are
`0x76` (BME280) and `0x29` (TSL2591).

```cpp
#include <Wire.h>
#include <Adafruit_BME280.h>
#include <Adafruit_TSL2591.h>

const int PIN_BME_POWER = 2;
const int PIN_TSL_POWER = 3;
const int PIN_SDA       = 4;
const int PIN_SCL       = 5;

Adafruit_BME280    bme;
Adafruit_TSL2591   tsl(2591);

void setup() {
  Serial.begin(115200);
  delay(1000);

  pinMode(PIN_BME_POWER, OUTPUT);
  pinMode(PIN_TSL_POWER, OUTPUT);
  digitalWrite(PIN_BME_POWER, HIGH);
  digitalWrite(PIN_TSL_POWER, HIGH);
  delay(300);

  Wire.begin(PIN_SDA, PIN_SCL);

  // I2C bus scan
  Serial.println("Scanning I2C bus...");
  int found = 0;
  for (byte addr = 1; addr < 127; addr++) {
    Wire.beginTransmission(addr);
    if (Wire.endTransmission() == 0) {
      Serial.printf("  Device at 0x%02X\n", addr);
      found++;
    }
  }
  if (found == 0) Serial.println("  No devices found — check wiring and power gates.");
  Serial.println();

  // BME280
  if (bme.begin(0x76, &Wire)) {
    Serial.printf("BME280  — Temp: %.1f °C  Humidity: %.1f %%  Pressure: %.0f hPa\n",
      bme.readTemperature(), bme.readHumidity(), bme.readPressure() / 100.0f);
  } else {
    Serial.println("BME280  — not found. Check connector and wire order.");
  }

  // TSL2591 (Adafruit_I2CDevice requires Wire to be re-initialised)
  Wire.begin(PIN_SDA, PIN_SCL);
  if (tsl.begin()) {
    tsl.setGain(TSL2591_GAIN_MED);
    tsl.setTiming(TSL2591_INTEGRATIONTIME_100MS);
    uint32_t lum  = tsl.getFullLuminosity();
    uint16_t ir   = lum >> 16;
    uint16_t full = lum & 0xFFFF;
    Serial.printf("TSL2591 — Lux: %.1f  IR: %d  Full: %d\n",
      tsl.calculateLux(full, ir), ir, full);
  } else {
    Serial.println("TSL2591 — not found. Check connector and wire order.");
  }
}

void loop() {}
```

If a sensor is not found but appears on the I2C scan, the most likely cause is a
wrong wire order on the connector — double-check the colour order from section 2.5/2.6 of the
[build instructions](build_instructions.md).

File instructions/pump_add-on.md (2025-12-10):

# Pump Add-On Build Instructions
The pump add-on lets your SmartPlants device automatically water your plant whenever the soil gets too dry. You will upgrade your base module with a pump, a MOSFET switch, and a flyback diode for protection.

## 1. Collect All Parts

**List of parts**
- Mini diaphragm pump (3–6 V, depending on your power source)
- IRLZ14 (or other logic-level N-MOSFET)
- 1× 1N4148 or 1N4001 diode (flyback diode)
- 1× 22 Ω resistor (gate protection resistor, optional but recommended)
- 1× 10k Ω resistor (gate pull-down resistor, optional but recommended)
- 1x PG7 cable gland (optional but recommended)
- 1x 3D-printed pump-housing
- 1x 2-core cable (0.5 - 1m)
- Extra jumper cables
- Tubes (for pump inlet/outlet)
- Water container

## 2. Understand the Pump Circuit

The ESP32 cannot power a pump directly. It uses a MOSFET that acts as an electronic switch.

- D7 → Gate (through 22 Ω, pulled-down to GND through a 10k Ω resistor)
- Pump + → Battery +
- Pump – → MOSFET Drain
- MOSFET Source → Ground
- Diode across pump wires (stripe to pump +)

⚠️ Important: The MOSFET must share ground with the ESP32!

## 3. Prepare the Pump

Solder a two-core cable to the pumps connectors. Insert the pump into the housing and pull the cable through the hole. Add the PG7 cable gland and screw it into the pump housing. Crimp a 2-pin dupont connector to the other end of the pump cable. 

## 4. Assemble the Pump Add-On Circuit

Follow the diagram:

**Battery Pack Version**
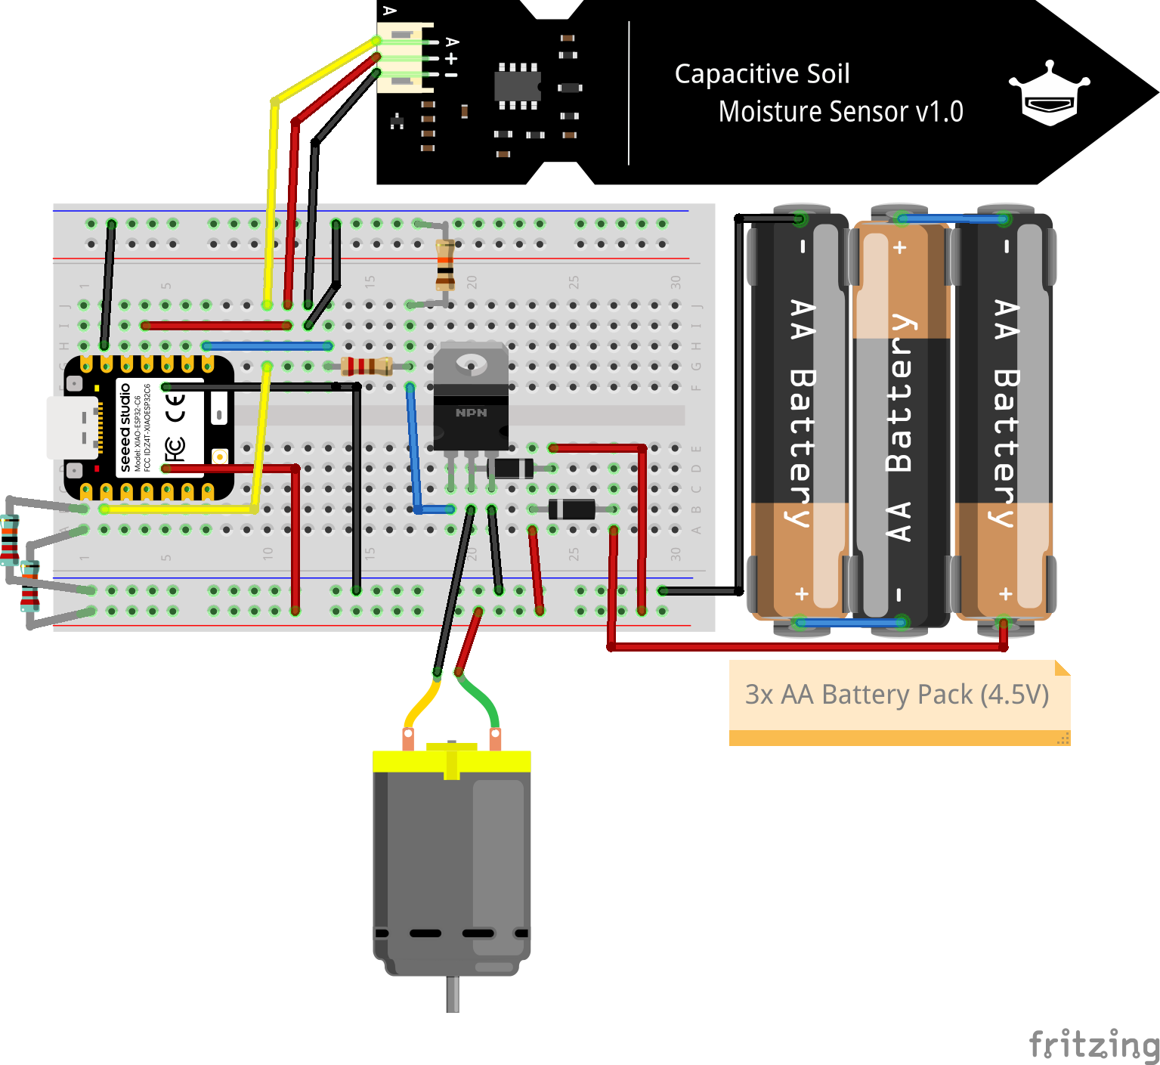
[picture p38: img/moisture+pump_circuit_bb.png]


**Li-ion/Lipo Version**
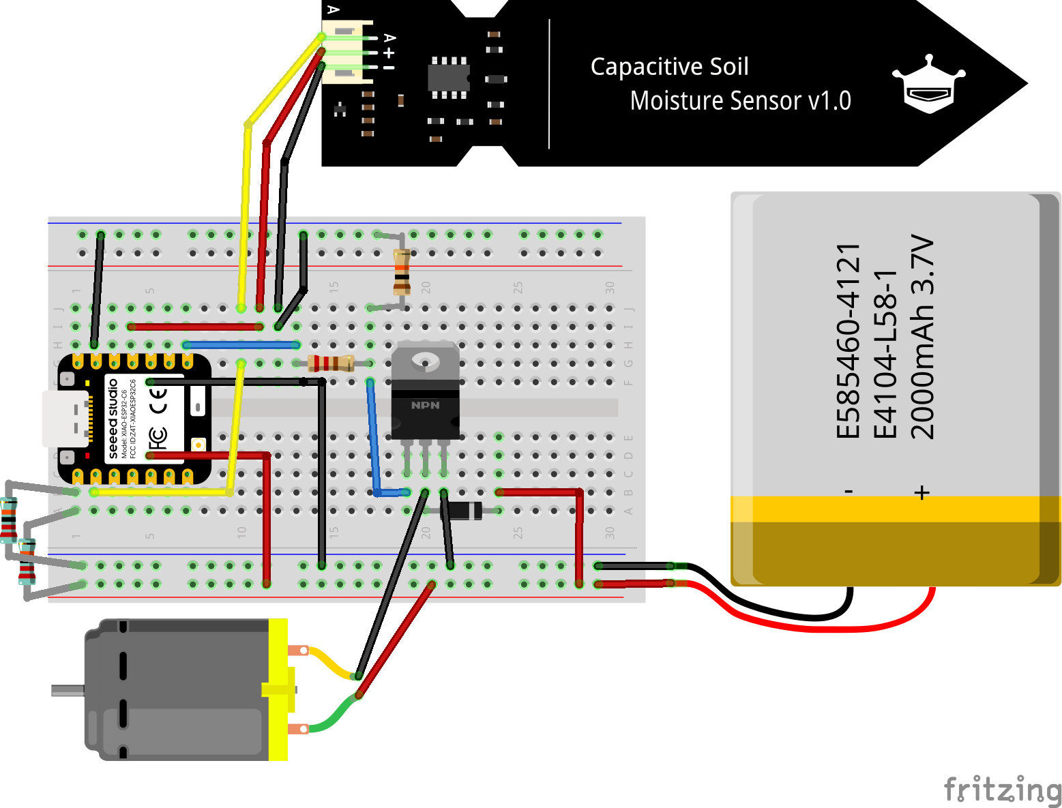
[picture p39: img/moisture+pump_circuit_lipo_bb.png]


Here are all the connections written out:

Pump
- Pump + → Battery +
- Pump – → MOSFET Drain

MOSFET IRLZ14 (Front view, legs down: Gate, Drain, Source = GDS)
- Gate → D7 via 22 Ω resistor, pulled-down to GND through a 10k Ω resistor 
- Drain → Pump –
- Source → GND

Diode
- Stripe → Pump +
- Other side → Pump –

## 5. Test the pump
Copy this script into your Arduino IDE and flash the ESP with it. The pump should turn on and off two times. 

```cpp
// Simple Pump Test for XIAO ESP32-C6
// Turns pump on/off two times for 1 second each

const int pumpPin = D7;  // MOSFET gate pin

void setup() {
  Serial.begin(115200);
  delay(1000);
  Serial.println("Pump Test Starting...");

  pinMode(pumpPin, OUTPUT);
  digitalWrite(pumpPin, LOW);  // ensure pump is off

  for (int i = 1; i <= 2; i++) {
    Serial.printf("Test cycle %d: Pump ON\n", i);
    digitalWrite(pumpPin, HIGH);   // turn pump on
    delay(1000);

    Serial.printf("Test cycle %d: Pump OFF\n", i);
    digitalWrite(pumpPin, LOW);    // turn pump off
    delay(1000);
  }

  Serial.println("Pump Test Completed.");
}

void loop() {
  // nothing here
}

```

## 6. Upload final script

Upload the full code from code/moisture-pump and adjust the user settings. Under "Pump control" you can set the "moistureThreshold" and the "pumpDuration".

⚠️ Note: After pumping the water the moisture is measured again in the next wakeup cycle. This allows for the soil to soak up all the water. If the moisture increases only by a few percent, increase the pump duration.

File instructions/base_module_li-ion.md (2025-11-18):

# Build Instructions Base Module
## 1. Collect All Parts
At the beginning get all the necessary parts together. 

**List of parts**
- Breadboard
- XIAO ESP32C6 Microcontroller
- 18650 battery holder
- 18650 Li-ion cell
- Moisture Sensor
- Sensor Cable
- Sensor Housing
- 3x Jumper Cable
- 2x 220k Ohm Resistors
- laser-cut Housing
- 8x Wood Screws
- Velcro Tape

## 2. Prepare Parts
Some parts have to be prepared (soldered/crimped/glued). You have the option to get them pre-prepared from us if you feel unconfortable using the tools but you are encouraged to try even if you never used them before!

Obviously all preparation don't have to be done in an particular order. So if you see that some tools are in use that you need, just do some other preparation.

**Solder Microcontroller**\
Solder the pin header to the microcontroller and add wires to the battery pads.

 

**Crimp Cable**\
Crimp one 3-pin JST (PH) connector on one side of the cable and a 3-pin male Dupont connector on the other. Make sure the wires follow the correct order: VCC (red), SIGNAL (yellow), GND (black). If you want the cable to fit tightly through the hole in the housing, feed the cable through the hole before crimping the connector, as crimped plugs won’t fit through small openings.



**Prepare Sensor**\
_Discard the cable that comes with the sensor_ (give it to us). Connect the sensor with the longer round cable you just prepared. Put the sensor into the 3D-printed housing and screw it together. We recommend to push the black isolation of the cable into the housing hole so it seals it tightly.

  

**Prepare the Housing**\
Assemble the laser-cut housing. If there is not yet a hole for the sensor cable, drill one (use a 8mm drill). If you want to have the cable fit very tightly in the hole, you can use a 5mm drill but you might need to remove the connector end of the cable to fit it through (or put it through the hole before crimping). You can also use the cable plugs to have neat cable exits. 

⚠️ Important: ADO NOT add the small corners of the housing at the end. Add them while you are connecting the sides. Otherwise you won't be able to fit them in there!

## 3. Assemble the Circuit
Add all parts to the breadboard as shown in the circuit below.
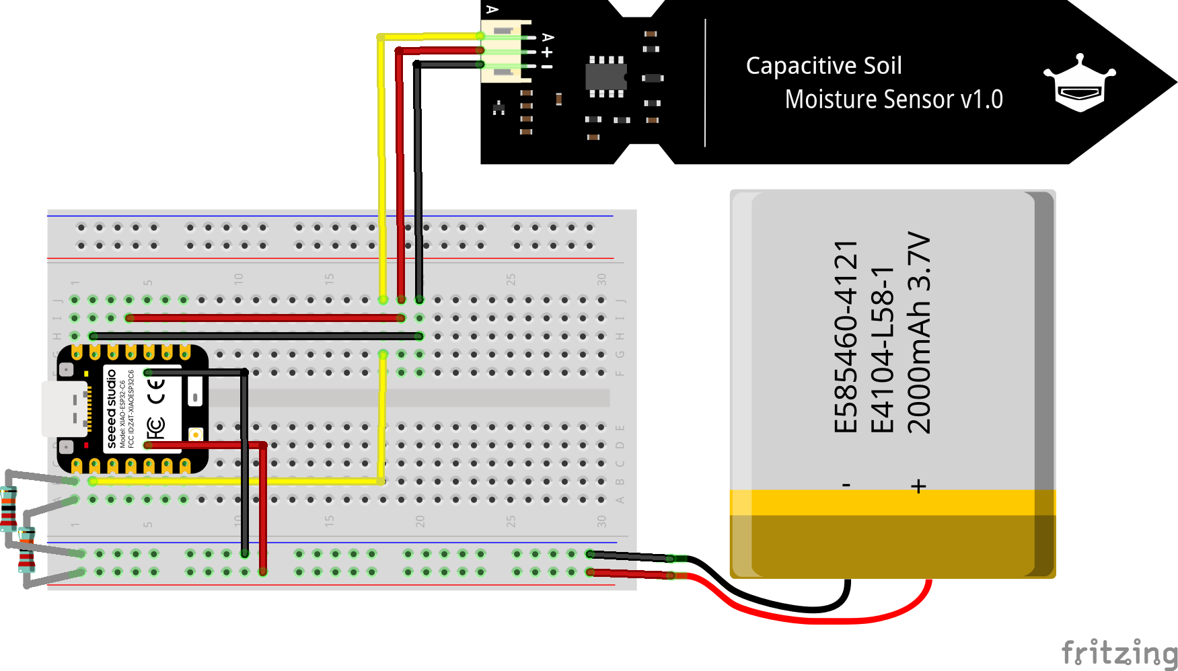
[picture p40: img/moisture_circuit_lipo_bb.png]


XIAO ESP32C6 Pinout
XIAO ESP32C6 Pinout 

⚠️ Important: Do not connect the li-ion battery yet. We’ll add it only after programming and testing to avoid accidental powering.

Here are all the connections written out:

Moisture Sensor:
- Signal pin (yellow cable) to board pin A1
- Vcc pin (power, red cable) to board pin D10
- GND pin (ground, black cable) to board GND

Microcontroller:
- Battery Pad + to the + rail in the breadboard
- Battery Pad - to the - rail in the breadboard
- Connect pin A0 to the + and - rail with a 220k Ohm Resistor (voltage divider). Be careful, the legs of the resistor on the rail side should not touch.

It should look like this in the end:




## 4. Program the Microcontroller
### 4.1 Preparations
You should already have the Arduino IDE with the respective board libraries set up. If not, check out these [instructions](https://wiki.seeedstudio.com/xiao_esp32c6_getting_started/#software-preparation).

### 4.2 Install the WiFiManager Library
You still need to install the WiFiManager libary. In the Arduino IDE select Tools > Manage Libraries. In the search bar enter "wifimanager" and install the library from "tzapu" (see below).



### 4.3 How to upload code to the Microcontroller
Here are the general steps to upload a programm to your microcontroller:
1. Connect your _XIAO ESP32-C6_ to your computer via USB
2. In the Arduino IDE:
    - Select the correct board under Tools > Board (the correct board is "XIAO_ESP32-C6")
    - Select the correct port under Tools > Port (this is usually already preselected)
3. Click the Upload button

⚠️ If the upload fails because the device is in deep sleep (only if you have programmed it before):

1. Unplug the board
2. Hold the BOOT button
3. Plug it back in while still holding BOOT
4. Release the button after 2 seconds
5. Try uploading again

### 4.4 Test Moisture Sensor
Copy this script into your Arduino IDE and flash the ESP with it. You should see output in the Serial Monitor (if not active yet, Tools>Serial Monitor)

Note: Make sure the sensor cable is fully plugged in and the metal prongs of the sensor are not touching each other. Readings may be unstable if the power to the sensor is not reliable.

```cpp
const int moisturePin = A1;
const int moisturePower = D10;

const float minMoistureVoltage = 0.5;
const float maxMoistureVoltage = 2.5;

float readMoistureVoltage() {
  uint32_t sum = 0;
  for (int i = 0; i < 16; i++) {
    sum += analogReadMilliVolts(moisturePin);
  }
  return sum / 16.0 / 1000.0;
}

float moistureVoltageToPercent(float voltage) {
  float percent = (maxMoistureVoltage - voltage) / (maxMoistureVoltage - minMoistureVoltage) * 100.0;
  return constrain(percent, 0.0, 100.0);
}

void setup() {
  Serial.begin(115200);
  delay(1000);
  Serial.println("Moisture Sensor Test");
  Serial.println();
}

void loop() {
  pinMode(moisturePower, OUTPUT);
  digitalWrite(moisturePower, HIGH);
  delay(200);  // sensor warm-up time

  float moistureVoltage = readMoistureVoltage();
  float moisturePercent = moistureVoltageToPercent(moistureVoltage);

  digitalWrite(moisturePower, LOW);

  Serial.println("Sensor Reading:");
  Serial.println("---------------------------");
  Serial.printf("Moisture Voltage : %.3f V\n", moistureVoltage);
  Serial.printf("Moisture Percent : %.1f %%\n", moisturePercent);
  Serial.println("---------------------------\n");

  delay(5000);  // wait 5 seconds
}

```

### 4.5 Moisture Sensor Calibration (optional!)

The moisture sensor gives you a voltage that decreases as moisture increases. To convert this into a percentage, you need to define two reference points:

- Dry: The voltage when the sensor is in air or dry soil (corresponds to 0%).
- Wet: The voltage when the sensor is in water or fully saturated soil (corresponds to 100%).

These voltages vary slightly between sensors, so calibrating each one improves accuracy.

Steps:
Dry measurement:

- Leave the sensor in air.
- Wait a few seconds and note the voltage value printed to the Serial Monitor.
- This is your maximum voltage (corresponds to 0% moisture).

Wet measurement:

- Insert the sensor tips into very wet soil or a glass of water (only the metal part).
- Wait a few seconds and note the voltage value.
- This is your minimum voltage (corresponds to 100% moisture).

Update your code:

Set the minMoistureVoltage and maxMoistureVoltage constants in your code to match the measured values:

```cpp
const float minMoistureVoltage = 0.5;
const float maxMoistureVoltage = 2.5;

```
Note: Use these values in the final code as well!

### 4.6 Upload Final Script
Download or copy the final code from this repository.

Before uploading the final code, open the sketch in Arduino IDE and scroll to the "USER SETTINGS" section at the top. Adjust the following values to match your setup:

```cpp
#include <WiFi.h>
#include <HTTPClient.h>
#include <WiFiManager.h>  // https://github.com/tzapu/WiFiManager

// ================= USER SETTINGS =================

// Device identification
// Choose a unique name and short ID for your device
// You can use an UUID generator and just use the first part (8 symbols) of the generated ID
// https://www.uuidgenerator.net/version4
const char* deviceName = "Maker Universe";
const char* deviceUUID = "22593b21";

// API endpoint
const char* apiUrl  = "https://plants.makeruniverse.de/plants/measurements";
const char* apiKey  = "vKpsikScqRUt2CdC";

// Moisture sensor calibration
// Measure voltage when sensor is in water (100%) and dry soil or air (0%)
const float minMoistureVoltage = 0.60;
const float maxMoistureVoltage = 2.45;

// Battery voltage divider ratio
// Only change this if you are using a different resistor setup
const float batteryDividerRatio = 2.0;

// Measurement interval (in seconds)
// 300 = 5 minutes, 3600 = 1 hour
// Measuring every hour is recommended for longer battery life
#define TIME_TO_SLEEP 3600 

// ================= PIN CONFIG ====================
const int moisturePin     = A1;
const int batteryPin      = A0;
const int sensorPowerPin  = D10;

#define uS_TO_S_FACTOR 1000000ULL
RTC_DATA_ATTR int bootCount = 0;

/// ========== FUNCTIONS ==========

void printWakeupReason() {
  esp_sleep_wakeup_cause_t reason = esp_sleep_get_wakeup_cause();
  switch (reason) {
    case ESP_SLEEP_WAKEUP_TIMER:
      Serial.println("Wakeup: Timer");
      break;
    default:
      Serial.printf("Wakeup not from timer: %d\n", reason);
      break;
  }
}

void setupWiFi() {
  WiFi.mode(WIFI_STA);
  WiFi.begin();

  Serial.print("Connecting to Wi-Fi");
  int retries = 0;
  while (WiFi.status() != WL_CONNECTED && retries < 20) {
    delay(500);
    Serial.print(".");
    retries++;
  }
  Serial.println();

  if (WiFi.status() == WL_CONNECTED) {
    Serial.println("Wi-Fi connected: " + WiFi.localIP().toString());
    return;
  }

  Serial.println("Wi-Fi failed. Starting WiFiManager...");
  WiFiManager wm;
  String apName = "SmartPlant-Setup-" + String(deviceName);
  wm.setConfigPortalTimeout(120);  // 2 min timeout
  if (!wm.autoConnect(apName.c_str())) {
    Serial.println("WiFiManager failed or timed out. Sleeping...");
    shutdownAndSleep();
  }
}

float readBatteryVoltage() {
  analogRead(batteryPin);
  delay(50);
  uint32_t Vbatt = 0;
  for (int i = 0; i < 16; i++) {
    Vbatt += analogReadMilliVolts(batteryPin);
  }
  return batteryDividerRatio * Vbatt / 16 / 1000.0;
}

float readMoistureVoltage() {
  delay(50);
  uint32_t Vraw = 0;
  for (int i = 0; i < 16; i++) {
    Vraw += analogReadMilliVolts(moisturePin);
  }
  return Vraw / 16.0 / 1000.0;
}

float moistureVoltageToPercent(float voltage) {
  float percent = (maxMoistureVoltage - voltage) / (maxMoistureVoltage - minMoistureVoltage) * 100.0;
  return constrain(percent, 0.0, 100.0);
}

void sendData(float moistureVoltage, float moisturePercent, float batteryVoltage) {
  if (WiFi.status() == WL_CONNECTED) {
    HTTPClient http;
    http.begin(apiUrl);
    http.addHeader("Content-Type", "application/json");
    http.addHeader("x-api-key", apiKey);

    String json = "{";
    json += "\"name\": \"" + String(deviceName) + "\",";
    json += "\"device_uuid\": \"" + String(deviceUUID) + "\",";
    json += "\"sensors\": {";
    json += "\"moisture_voltage\": {\"value\": " + String(moistureVoltage, 3) + ", \"unit\": \"V\"},";
    json += "\"moisture\": {\"value\": " + String(moisturePercent, 1) + ", \"unit\": \"%\"},";
    json += "\"battery_voltage\": {\"value\": " + String(batteryVoltage, 2) + ", \"unit\": \"V\"}";
    json += "}}";

    int httpResponseCode = http.POST(json);
    Serial.println("POST response code: " + String(httpResponseCode));
    Serial.println("Payload: " + json);
    http.end();
  } else {
    Serial.println("WiFi not connected, skipping data send.");
  }
}

void shutdownAndSleep() {
  digitalWrite(sensorPowerPin, LOW);
  WiFi.disconnect(true);
  WiFi.mode(WIFI_OFF);
  delay(200);
  Serial.flush();
  Serial.end();
  esp_sleep_enable_timer_wakeup(TIME_TO_SLEEP * uS_TO_S_FACTOR);
  esp_deep_sleep_start();
}

// ========== MAIN ==========

void setup() {
  Serial.begin(115200);
  delay(1000);

  ++bootCount;
  Serial.println("Boot #" + String(bootCount));
  printWakeupReason();

  setupWiFi();

  pinMode(sensorPowerPin, OUTPUT);
  digitalWrite(sensorPowerPin, HIGH);
  delay(200);
  float moistureVoltage = readMoistureVoltage();
  float moisturePercent = moistureVoltageToPercent(moistureVoltage);
  digitalWrite(sensorPowerPin, LOW);

  float batteryVoltage = readBatteryVoltage();

  Serial.println("Moisture voltage: " + String(moistureVoltage, 3) + " V");
  Serial.println("Moisture percent: " + String(moisturePercent, 1) + " %");
  Serial.println("Battery voltage: " + String(batteryVoltage, 2) + " V");

  sendData(moistureVoltage, moisturePercent, batteryVoltage);
  shutdownAndSleep();
}

void loop() {
  // Nothing here
}

```

### 4.7 How to Use the Sensor
This project uses WiFiManager, a user-friendly tool that allows the device to connect to a Wi-Fi network without hardcoded credentials. When powered on for the first time (or if no connection can be established), the device automatically starts a temporary Wi-Fi access point for 2 minutes, where users can enter their home Wi-Fi details via a web interface. After configuration, the device connects automatically in future sessions without needing to re-enter the credentials. You can always re-trigger the launch of the access point by switching the device off and on again.

Upload the code, look out for a Wi-Fi access point named "SmartPlant-Setup-DEVICE_NAME". Connect to it and enter the Wifi credentials. Now monitor the dashboard at ([plants.makeruniverse.de](plants.makeruniverse.de). You should see your plant/device coming up soon! If that worked, you are ready for the final Assembly.

Tip: For battery-powered operation, it's best to set the sleep time to 3600 seconds (1 hour). This gives you a good balance between data frequency and battery life.

## 5.Final Test and Assembly

Unplug the Microcontroller and add the li-ion battery to the circuit (keep it switched off first). Connect the - of the battery holder to the - rail. 

If everything is connected correctly (double check) watch for your data coming in on the dashboard.

If that worked, you are ready for putting everything into the housing. I recommend gluing the the breadboard to the back of the housing by removing parts of the cover of the tape on the back of it. Add the velco tape to the battery holder and the inner side of the housing lid so it can be attached there.

⚠️ Note: Switching the battery connection off and on again, re-triggers a measurement. If there is a Wifi connection, you should see the values appearing on the dashboard.

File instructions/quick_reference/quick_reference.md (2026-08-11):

# Smart Plants — Quick Build Reference

## 1. Solder the PCB

Orientation-sensitive components must match the silkscreen. Resistors are not orientation-sensitive.

| Ref | Component | Value  | Notes |
| --- | --- | --- | --- |
| R1, R2 | Resistor | 220 kΩ | Battery voltage divider |
| R3 | Resistor | 10 kΩ  | MOSFET gate pull-down |
| R4 | Resistor | 22 Ω | MOSFET gate protection |
| R5, R6 | Resistor | 4.7 kΩ | optional, I2C pull-up |
| D1 | Diode | 1N4001 | orientation sensitive, Flyback — stripe per silkscreen |
| D2 | Diode | 1N5817 | orientation sensitive, Schottky — stripe per silkscreen |
| J3, J5, J6, J11 | JST XH 4-pin | — | I2C connectors, you only need the first two from the top.  |
| J9 | JST XH 3-pin | — | Moisture sensor |
| J7, SW1 | JST XH 2-pin | — | Battery, switch |
| J10 | JST XH 2-pin | — | Pump |
| J4 | JST PH 2-pin | — | USB-C power (2.0 mm pitch — smaller than XH) |
| J1, J2 | 9-pin socket | — | Microcontroller — insert Waveshare board after soldering |
| C2 | Capacitor | 220 µF | orientation sensitive, Electrolytic — long leg to + hole |
| C3 | Capacitor | 22 µF  | orientation sensitive, Electrolytic — long leg to + hole |
| Q1 | MOSFET | IRLZ14 | Flat side matches silkscreen outline |

Suggested soldering order: resistors + diodes → JST connectors → pin sockets → capacitors + MOSFET.

> **legacy PCB bug:** On old PCB versions the moisture connector (J9) is labelled "D1-powered" — the correct GPIO is 21. Ignore the label.

---

## 2. Prepare Sensors and Actuators

**Moisture sensor cable** — cut 3-core cable to length, crimp 3-pin JST XH on both ends.
Wire order: SIGNAL (yellow) — GND (black) — VCC (red). Discard the short cable that ships with the sensor.
Insert sensor into housing, screw on lid.

**Pump** — solder 2-core cable to pump terminals. Insert pump into housing, fit PG7 cable gland.
Crimp 2-pin JST XH on free end.

**BME280** — solder pre-crimped cable. Wire order: VCC (black) — GND (red) — SCL (yellow) — SDA (white).
⚠ Black = VCC, red = GND (reversed from convention). Insert into Stevenson screen housing, thread cable through tube.

**TSL2591** — solder pre-crimped cable (wires away from sensor face). Same wire order as BME280.
Hot-glue sensor into housing bottom, sensor facing up. Glue half a ping-pong ball into the groove as diffuser.

**Switch** — solder 2-core cable, crimp 2-pin JST XH. Wire order doesn't matter.

**Battery pack** — crimp 2-pin JST XH. Wire order: VCC (red) — GND (black).

---

## 3. Assemble the Enclosure

1. Slot the laser-cut side panels together; add corner pieces while joining — they won't fit in later.
2. Drill an 8 mm hole for sensor cables if not pre-cut.
3. Mount BME280 through the lid hole (distance piece + locking piece). Hot-glue TSL2591 housing to lid.
   Keep the two sensors as far apart as possible.
4. Insert switch and USB-C connector into the housing. Feed pump and moisture sensor cables in.
5. Insert battery pack into the PCB mount. Screw PCB to mount. Insert Waveshare board into socket.
6. Stick velcro to the PCB mount bottom and matching strip inside housing. Fix mount in place.
7. Connect all components to the labelled PCB connectors. BME280 → "I2C D2-powered", TSL2591 → "I2C D3-powered".

---

## 4. Flash the Firmware (from the browser)

Use **Chrome, Edge, or Opera** and a USB-C **data** cable.

1. Put the board in flashing mode: **unplug → hold BOOT → plug in → release after ~2 s**
   (the firmware sleeps quickly and drops the USB port, so start it in the bootloader).
2. Open **[vektorious.github.io/hpi_smart_plants](https://vektorious.github.io/hpi_smart_plants/)**.
3. **Connect** → pick the `USB JTAG/serial debug unit` port → **Install Smart Plants Firmware**.

> Building from source instead? See [`firmware_from_source.md`](../firmware_from_source.md).

---

## 5. Configure (setup portal)

On first boot the device opens a Wi-Fi hotspot named **`SmartPlant-XXXXXXXX-Setup`** (unique per board).

1. Connect to it (no password); the setup page opens automatically (or browse to `192.168.4.1`).
2. Set your **Wi-Fi**, and optionally the device name, which sensors/pump are enabled, and
   calibration. The API key is pre-filled. **Save.**

> Reopen the setup page later to change anything: **double-press the reset button**.

---

## 6. Check & Calibrate

Open **Live Sensor Readings** in the portal:

- Values refresh every 10 s; the Wi-Fi badge shows the connection.
- **Send to API** → green **200 OK** confirms Wi-Fi + API key + server.
- A sensor showing **"not detected"** → check that sensor's cable / wire order.

**Calibrate the moisture sensor** from the same page — read the *moisture voltage*:
- **In open air** (dry, 0 %) → enter as *Moisture dry voltage*.
- **Prongs in water** (wet, 100 %) → enter as *Moisture wet voltage*.

Save in the portal — no reflash. Defaults: wet 0.60 V, dry 2.45 V.

---

## 7. Finish & Deploy

Click **Finish setup** → the device takes a reading and starts its hourly cycle. Confirm it
appears on `diy-sensor.org/dashboard/device/<device-id>` (link shown in the portal). Disconnect USB, flip the
power switch on, screw the lid on. Done.

> A single reset triggers an immediate reading; a double-press reopens the setup page.

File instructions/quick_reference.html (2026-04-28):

# Smart Plants — Quick Build Reference

Waveshare ESP32-C6 Zero · smart_plants_breakout_ws-board_rev2

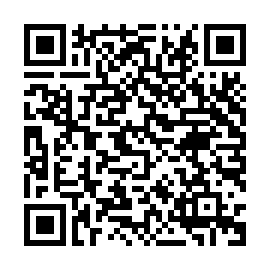
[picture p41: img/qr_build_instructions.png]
QR code
 Full instructions

## 1. Solder the PCB

Match orientation-sensitive components to the silkscreen. Resistors are not orientation-sensitive. Suggested order: resistors + diodes → JST connectors → pin sockets → capacitors + MOSFET.

Ref | Component | Value | Notes
R1, R2 | Resistor | 220 kΩ | Battery voltage divider
R3 | Resistor | 10 kΩ | MOSFET gate pull-down
R4 | Resistor | 22 Ω | MOSFET gate protection
R5, R6 | Resistor | 4.7 kΩ | I2C pull-up
D1 | Diode | 1N4001 | Flyback — stripe toward pump +
D2 | Diode | 1N5817 | Schottky — stripe per silkscreen
C2 | Capacitor | 220 µF | Electrolytic — long leg to +
C3 | Capacitor | 22 µF | Electrolytic — long leg to +
Q1 | MOSFET | IRLZ14 | Flat side matches silkscreen
J3, J5, J6, J11 | JST XH 4-pin | — | I2C connectors
J9 | JST XH 3-pin | — | Moisture sensor
J7, SW1 | JST XH 2-pin | — | Battery, switch
J10 | JST XH 2-pin | — | Pump
J4 | JST PH 2-pin | — | USB-C power (2.0 mm pitch)
J1, J2 | 9-pin socket | — | Insert Waveshare board after soldering

⚠ PCB label bug: moisture connector (J9) says "D1-powered" — correct GPIO is 21.

## 2. Prepare Sensors & Actuators

Moisture sensor cable — cut 3-core cable to length, crimp 3-pin JST XH on both ends.
Wire order: GND (black) — VCC (red) — SIGNAL (yellow). Discard the short cable from the sensor.
Insert sensor into housing, screw on lid.

Pump — solder 2-core cable to pump. Insert into housing, fit PG7 cable gland, crimp 2-pin JST XH on free end.

BME280 — solder pre-crimped cable: VCC (black) — GND (red) — SCL (yellow) — SDA (white).
Insert into Stevenson screen, thread cable through tube.

TSL2591 — same wire order as BME280. Wires away from sensor face.
Hot-glue sensor into housing (facing up). Glue half ping-pong ball into groove as diffuser.

⚠ Pre-crimped cables: black = VCC, red = GND — reversed from convention. Double-check before soldering.

Switch — solder 2-core cable, crimp 2-pin JST XH. Wire order doesn't matter.

Battery pack — crimp 2-pin JST XH: VCC (black) — GND (red).

## 3. Assemble the Enclosure

1. Slot laser-cut panels together; add corner pieces while joining sides.
2. Drill 8 mm hole for sensor cables if not pre-cut.
3. Mount BME280 through lid hole (distance piece + locking piece). Hot-glue TSL2591 housing to lid. Keep sensors as far apart as possible.
4. Insert switch and USB-C connector into housing. Feed pump and moisture cables in.
5. Insert battery pack into PCB mount. Screw PCB to mount. Insert Waveshare board into socket.
6. Velcro PCB mount to housing interior. Connect all components to labelled PCB connectors. BME280 → I2C D2-powered | TSL2591 → I2C D3-powered

## 4. Program

1. Install Arduino IDE. Add to Preferences → Additional Boards Manager URLs: https://dl.espressif.com/dl/package_esp32_index.json
2. Boards Manager → install ESP32 by Espressif Systems. Select board: Waveshare ESP32-C6-Zero.
3. Library Manager → install: WiFiManager (tzapu), Adafruit BME280, Adafruit TSL2591, Adafruit Unified Sensor. Click "Install All" when prompted.
4. Open code/sp_modular/sp_modular.ino. Edit config.h:

#define DEVICE_NAME  "my-plant"         // your plant name
#define DEVICE_UUID  "00000000"         // 8-char ID from dashboard
#define API_KEY      "vKpsikScqRUt2CdC"

5. Select port → Upload.

Upload fails? Unplug → hold BOOT → plug in → release after 2 s → retry Upload.

## 5. Connect to Wi-Fi

On first boot the device opens hotspot <DEVICE_NAME>-Setup (no password).
Connect, enter Wi-Fi credentials in the page that opens. Credentials are saved automatically.

## 6. Calibrate Moisture Sensor

Open Serial Monitor at 115200 baud after uploading the main sketch.

- Dry (0%): hold sensor in open air → note voltage → set as MAX_MOIST_V
- Wet (100%): submerge prongs in water → note voltage → set as MIN_MOIST_V

Edit config.h with your values and re-upload. Defaults: MIN 0.60 V / MAX 2.45 V.

## 7. Final Test & Deploy

1. Confirm a reading appears on plants.makeruniverse.de while on USB.
2. Disconnect USB, flip power switch on.
3. Confirm a new reading appears on the dashboard.
4. Velcro mount in place, feed moisture cable through housing hole, screw lid on.

💡 Switching off and on triggers an immediate reading — no need to wait an hour.

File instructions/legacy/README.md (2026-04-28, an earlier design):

# Legacy Instructions

These guides describe the **breadboard-based** build of the Smart Plants device using the
SEEED Studio XIAO ESP32-C6. They are kept for reference but are **no longer supported**.

The current PCB-based build is documented in `instructions/waveshare_pcb.md`.

| File | What it covers |
|---|---|
| `base_module_batteries.md` | Breadboard build, 3× AA battery power |
| `base_module_li-ion.md` | Breadboard build, 18650 Li-ion power |
| `pump_add-on.md` | Adding an automatic watering pump to the breadboard build |

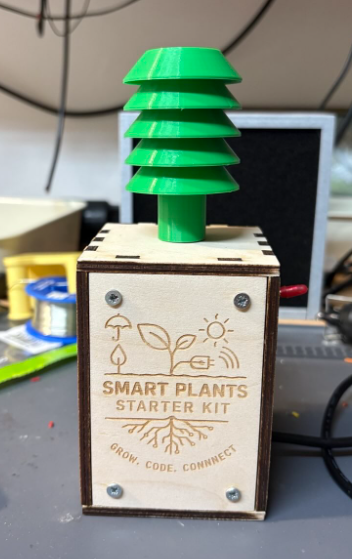
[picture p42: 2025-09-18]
img/final_build.png

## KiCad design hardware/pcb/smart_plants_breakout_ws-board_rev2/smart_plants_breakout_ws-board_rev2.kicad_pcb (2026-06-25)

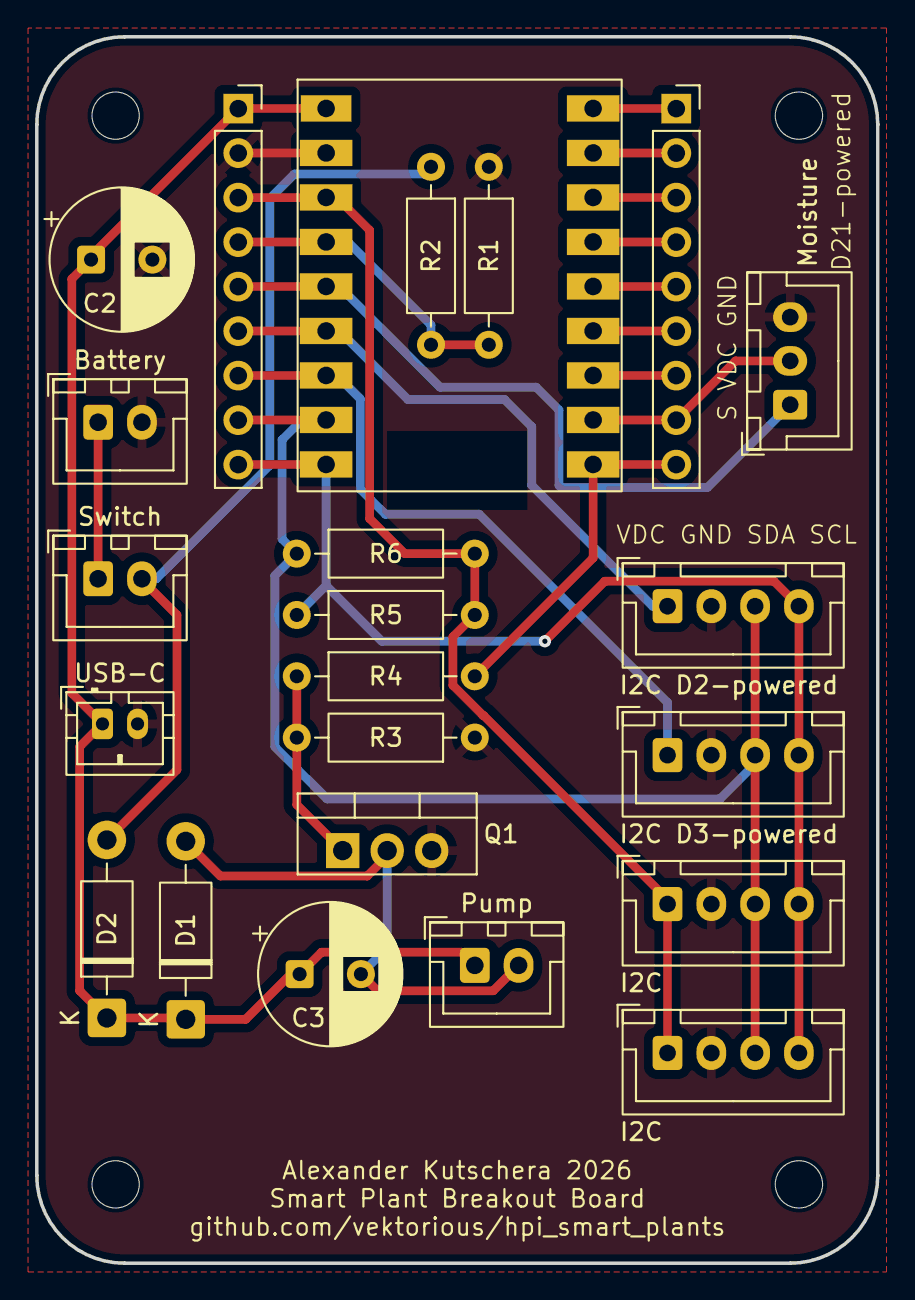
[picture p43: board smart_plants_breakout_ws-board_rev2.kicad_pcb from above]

Board: 2 copper layers, 48.0 x 70.0 mm, 27 parts (0 on the bottom side), 22 nets.

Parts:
Battery: Battery; JST_XH_B2B-XH-A_1x02_P2.50mm_Vertical
C2: 220µF; CP_Radial_D8.0mm_P3.50mm
C3: 22µF; CP_Radial_D8.0mm_P3.50mm
D1: 1N4001; D_DO-41_SOD81_P10.16mm_Horizontal
D2: 1N5817; D_DO-41_SOD81_P10.16mm_Horizontal
H1, H2, H3, H4: MountingHole; MountingHole_2.7mm_M2.5
I2C, I2C#2: I2C; JST_XH_B4B-XH-A_1x04_P2.50mm_Vertical
I2C D2-powered: I2C D2-powered; JST_XH_B4B-XH-A_1x04_P2.50mm_Vertical
I2C D3-powered: I2C D3-powered; JST_XH_B4B-XH-A_1x04_P2.50mm_Vertical
J1, J2: Conn_01x09_Pin; PinSocket_1x09_P2.54mm_Vertical
Moisture: Moisture Sensor; JST_XH_B3B-XH-A_1x03_P2.50mm_Vertical
Pump: Pump; JST_XH_B2B-XH-A_1x02_P2.50mm_Vertical
Q1: IRLZ14; TO-220-3_Vertical
R1, R2: 220k; R_Axial_DIN0207_L6.3mm_D2.5mm_P10.16mm_Horizontal
R3: 10k; R_Axial_DIN0207_L6.3mm_D2.5mm_P10.16mm_Horizontal
R4: 22R; R_Axial_DIN0207_L6.3mm_D2.5mm_P10.16mm_Horizontal
R5, R6: 4k7; R_Axial_DIN0207_L6.3mm_D2.5mm_P10.16mm_Horizontal
Switch: Power Switch; JST_XH_B2B-XH-A_1x02_P2.50mm_Vertical
U1: Waveshare ESP32-C6-Nano; Waveshare-ESP32-C6-Zero-THT
USB-C: USB-C Power; JST_PH_B2B-PH-K_1x02_P2.00mm_Vertical

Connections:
GND: Battery.2, C2.2, I2C.2, I2C D2-powered.2, I2C D3-powered.2, I2C#2.2, J1.2, Moisture.3, Q1.3 (S), R1.1, R3.1, U1.2 (GND), USB-C.2
unnamed: C3.2, D1.2 (A), Pump.2, Q1.2 (D)
unnamed: C2.1, C3.1, D1.1 (K), D2.1 (K), J1.1, Pump.1, U1.1 (VCC), USB-C.1
unnamed: D2.2 (A), R2.1, Switch.2 (B)
unnamed: J1.4, R1.2, R2.2, U1.4 (IO0)
unnamed: J1.5, Moisture.1, U1.5 (IO1)
unnamed: I2C D2-powered.1, J1.6, U1.6 (IO2)
unnamed: I2C D3-powered.1, J1.7, U1.7 (IO3)
unnamed: I2C.3, I2C D2-powered.3, I2C D3-powered.3, I2C#2.3, J1.8, R6.1, U1.8 (IO4)
unnamed: I2C.4, I2C D2-powered.4, I2C D3-powered.4, I2C#2.4, J1.9, R5.1, U1.9 (IO5)
unnamed: J2.1, U1.18 (TX)
unnamed: J2.2, U1.17 (RX)
unnamed: J2.3, U1.16 (IO14)
unnamed: J2.4, U1.15 (IO15)
unnamed: J2.5, U1.14 (IO18)
unnamed: J2.6, U1.13 (IO19)
unnamed: J2.7, U1.12 (IO20)
unnamed: J2.8, Moisture.2, U1.11 (IO21)
unnamed: J2.9, R4.2, U1.10 (IO22)
unnamed: Battery.1, Switch.1 (A)
unnamed: Q1.1 (G), R3.2, R4.1
VDC: I2C.1, I2C#2.1, J1.3, R5.2, R6.2, U1.3 (V3V)

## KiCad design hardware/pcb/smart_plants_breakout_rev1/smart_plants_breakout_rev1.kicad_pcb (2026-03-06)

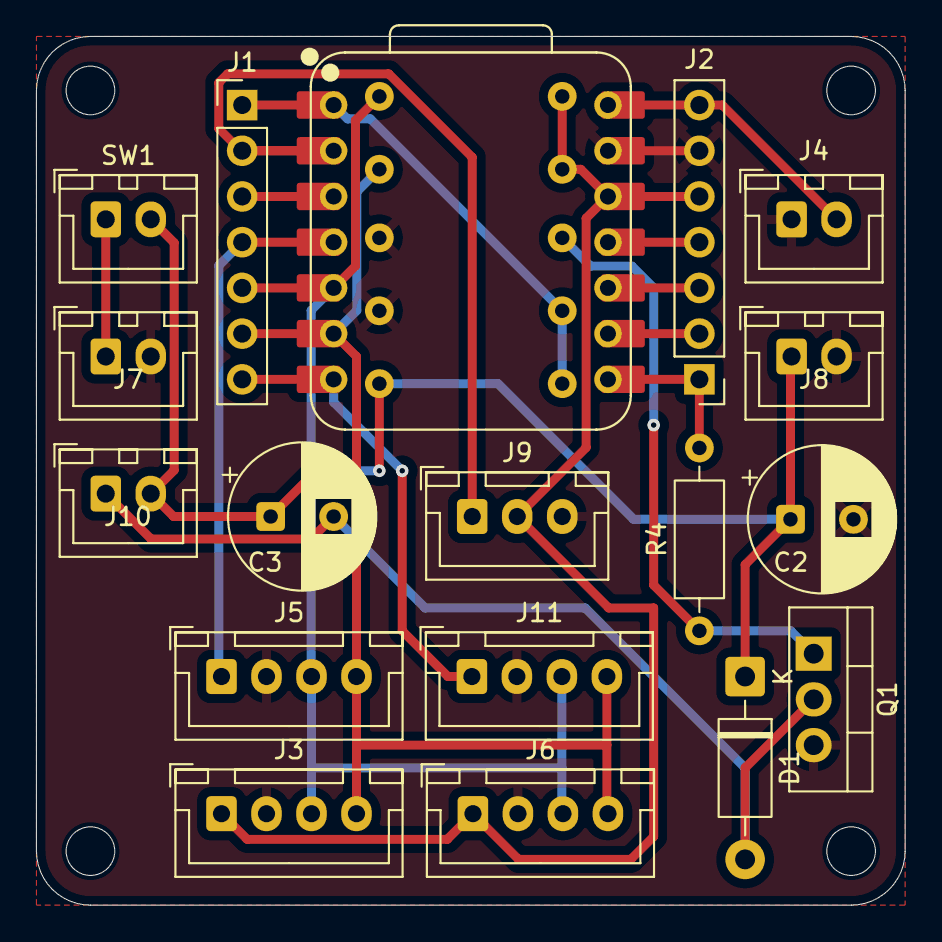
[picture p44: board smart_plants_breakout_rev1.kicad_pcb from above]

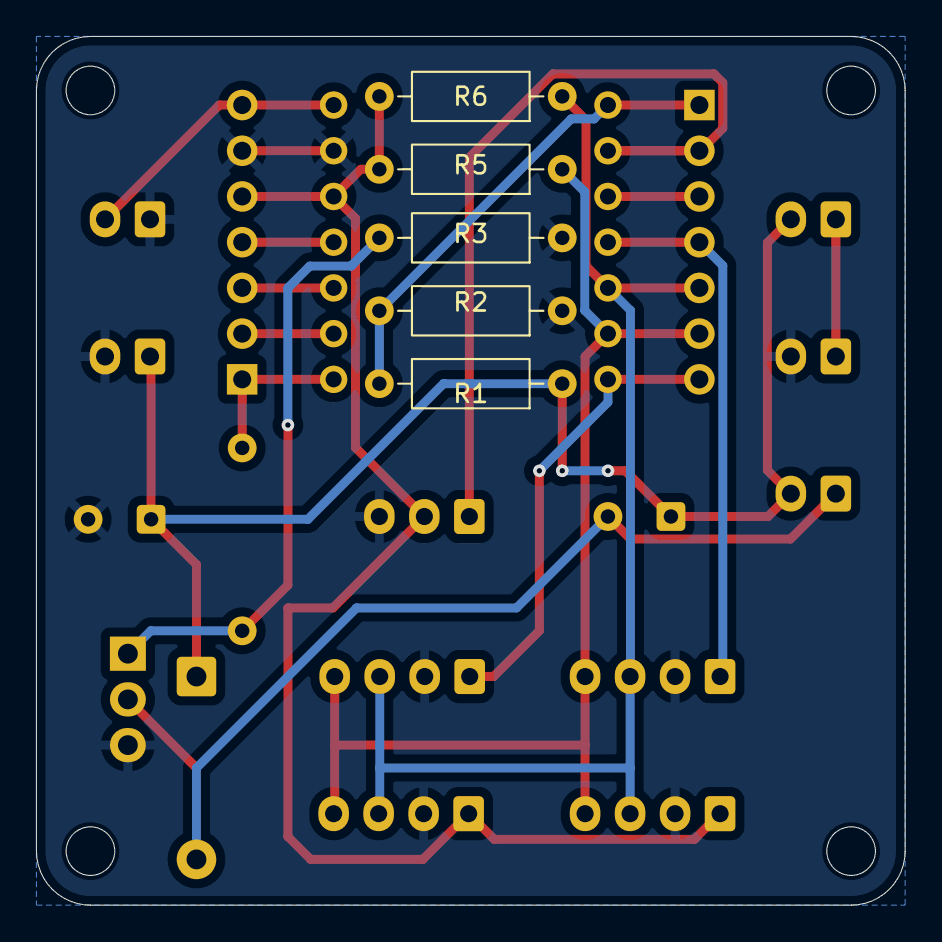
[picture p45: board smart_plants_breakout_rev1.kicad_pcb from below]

Board: 2 copper layers, 48.3 x 48.3 mm, 27 parts (5 on the bottom side), 18 nets.

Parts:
C2: 220µF; CP_Radial_D8.0mm_P3.50mm
C3: 22µF; CP_Radial_D8.0mm_P3.50mm
D1: 1N4001; D_DO-41_SOD81_P10.16mm_Horizontal
H1, H2, H3, H4: MountingHole; MountingHole_2.7mm_M2.5
J1, J2: Breakout; PinHeader_1x07_P2.54mm_Vertical
J3, J6: I2C; JST_XH_B4B-XH-A_1x04_P2.50mm_Vertical
J4: USB-C Power; JST_XH_B2B-XH-A_1x02_P2.50mm_Vertical
J5: I2C D3-powered; JST_XH_B4B-XH-A_1x04_P2.50mm_Vertical
J7: Battery; JST_XH_B2B-XH-A_1x02_P2.50mm_Vertical
J8: Board Power; JST_XH_B2B-XH-A_1x02_P2.50mm_Vertical
J9: Moisture Sensor; JST_XH_B3B-XH-A_1x03_P2.50mm_Vertical
J10: Pump; JST_XH_B2B-XH-A_1x02_P2.50mm_Vertical
J11: I2C D6-powered; JST_XH_B4B-XH-A_1x04_P2.50mm_Vertical
Q1: IRLZ14; TO-220-3_Vertical
R1, R2: 220k; R_Axial_DIN0207_L6.3mm_D2.5mm_P10.16mm_Horizontal
R3: 10k; R_Axial_DIN0207_L6.3mm_D2.5mm_P10.16mm_Horizontal
R4: 22R; R_Axial_DIN0207_L6.3mm_D2.5mm_P10.16mm_Horizontal
R5, R6: 4k7; R_Axial_DIN0207_L6.3mm_D2.5mm_P10.16mm_Horizontal
SW1: Power Switch; JST_XH_B2B-XH-A_1x02_P2.50mm_Vertical
U1: XIAO-ESP32-C6; XIAO-ESP32C6-DIP

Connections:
BAT+: C2.1, C3.1, D1.1 (K), J8.1, J10.2, R1.1, SW1.2 (B)
BAT-: C2.2, J2.6, J3.2, J4.1, J5.2, J6.2, J7.2, J8.2, J9.3, J11.2, Q1.3 (S), R2.1, R3.1, U1.13 (GND)
unnamed: C3.2, D1.2 (A), J10.1, Q1.2 (D)
unnamed: J1.1, R1.2, R2.2, U1.1 (GPIO0/A0/D0)
unnamed: J1.2, J9.1, U1.2 (GPIO1/A1/D1)
unnamed: J1.3, U1.3 (GPIO2/A2/D2)
unnamed: J1.4, J5.1, U1.4 (GPIO21/D3)
unnamed: J1.5, J3.3, J5.3, J6.3, J11.3, R6.1, U1.5 (GPIO22/D4/SDA)
unnamed: J1.6, J3.4, J5.4, J6.4, J11.4, R5.1, U1.6 (GPIO23/D5/SCL)
unnamed: J1.7, J11.1, U1.7 (GPIO16/D6/TX)
unnamed: J2.1, R4.2, U1.8 (GPIO17/D7/RX)
unnamed: J2.2, U1.9 (GPIO19/D8/SCK)
unnamed: J2.3, U1.10 (GPIO20/D9/MISO)
unnamed: J2.4, U1.11 (GPIO18/D10/MOSI)
unnamed: J7.1, SW1.1 (A)
unnamed: Q1.1 (G), R3.2, R4.1
VBUS: J2.7, J4.2, U1.14 (VBUS)
VDC: J2.5, J3.1, J6.1, J9.2, R5.2, R6.2, U1.12 (3V3)

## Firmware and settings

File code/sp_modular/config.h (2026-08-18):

#pragma once

#include <Arduino.h>

// =====================================================================
//  Smart Plants — configuration
//
//  As of the runtime-config rework, the values that a user may want to
//  change per device (feature toggles, device identity, sleep interval,
//  calibration, pump behaviour) are stored in NVS/Preferences and edited
//  from the WiFiManager setup portal — NOT recompiled.
//
//  The DEFAULT_* macros below are only the factory defaults, applied on
//  first boot (or after a settings reset). Pin assignments stay
//  compile-time because they depend on the physical board.
// =====================================================================

// ============ FEATURE DEFAULTS ============
// Initial state of each module. All sensor code is always compiled in;
// these just set the runtime default in settings.useBme / useTsl / usePump.
#define DEFAULT_USE_BME280   true   // Temperature, humidity, pressure (I2C)
#define DEFAULT_USE_TSL2591  true   // Light sensor — lux + IR (I2C)
#define DEFAULT_USE_PUMP     true   // Automatic watering pump via MOSFET

// ============ DEVICE INFO DEFAULTS ============
// Editable in the setup portal. Device name and ID are shown on the
// dashboard. API key is provided at the workshop.
#define DEFAULT_DEVICE_NAME  "SmartPlant"
// Prefix for the generated device_id (the chip-derived suffix is appended).
// Keep to [A-Za-z0-9_-] — the API rejects anything else.
#define DEFAULT_DEVICE_ID_PREFIX "smartplant"
#define DEFAULT_PROJECT      ""   // Groups devices on the dashboard; empty = ungrouped. Set per workshop in the portal (e.g. "workshop-2026").
#define DEFAULT_API_URL      "https://diy-sensor.org/sensor/measurement"
#define DEFAULT_API_KEY      "public-test-key"

// ============ SLEEP DEFAULTS ============
#define DEFAULT_TIME_TO_SLEEP_SEC 3600      // Wake interval in seconds (default: 1 hour)
#define uS_TO_S_FACTOR 1000000ULL

// ============ CALIBRATION DEFAULTS ============
// Adjust MIN/MAX per sensor batch — measure voltage in wet soil and dry air.
#define DEFAULT_MIN_MOIST_V   0.60f  // Voltage when soil is saturated (wet)
#define DEFAULT_MAX_MOIST_V   2.45f  // Voltage in open air (dry)
#define DEFAULT_BATT_DIVIDER  2.0f   // Voltage divider ratio on the battery ADC pin

// ============ PUMP DEFAULTS ============
#define DEFAULT_MOISTURE_THRESHOLD  50.0f  // Pump triggers below this moisture percentage
#define DEFAULT_PUMP_DURATION_SEC   2      // How long to run the pump per cycle (seconds)

// ============ PIN CONFIG (compile-time — board dependent) ============
// --- Waveshare ESP32-C6 Zero + smart_plants_breakout_ws-board_rev2 (main build) ---
#define PIN_MOISTURE     1   // A1  — capacitive moisture sensor (ADC)
#define PIN_BATTERY      0   // A0  — battery voltage via 2× divider (ADC)
#define PIN_SENSOR_POWER 21  // GPIO 21 — moisture sensor power gate (PCB rev2 silkscreen incorrectly labels this "D1-powered")
#define PIN_BME_POWER    2   // GPIO 2  — BME280 power gate
#define PIN_TSL_POWER    3   // GPIO 3  — TSL2591 power gate
#define PIN_PUMP         22  // GPIO 22 — pump MOSFET gate
#define PIN_SDA          4   // GPIO 4  — I2C data
#define PIN_SCL          5   // GPIO 5  — I2C clock

// --- SEEED Studio XIAO ESP32-C6 + smart_plants_breakout_rev1 ---
// To build for XIAO: comment out the Waveshare block above and uncomment this one.
// #define PIN_MOISTURE     A1
// #define PIN_BATTERY      A0
// #define PIN_SENSOR_POWER D1
// #define PIN_BME_POWER    D0
// #define PIN_TSL_POWER    D2
// #define PIN_PUMP         D10
// #define PIN_SDA          SDA
// #define PIN_SCL          SCL

// ============ RUNTIME SETTINGS ============
// Persisted in NVS/Preferences; edited from the setup portal.
// Defined in settings.ino; loaded once at boot via loadSettings().
struct Settings {
  char     deviceName[32];
  char     deviceId[32];        // public device_id on the dashboard; not user-editable
  char     project[48];         // dashboard grouping; empty = ungrouped
  char     apiKey[48];
  char     apiUrl[128];
  uint32_t sleepSec;
  float    minMoistV;
  float    maxMoistV;
  float    battDivider;
  float    moistureThreshold;   // %
  uint32_t pumpDurationSec;
  bool     useBme;
  bool     useTsl;
  bool     usePump;
};

extern Settings settings;

void loadSettings();                 // populate `settings` from NVS (or defaults on first boot)
void saveSettings();                 // persist `settings` to NVS
void resetSettingsToDefaults();      // overwrite `settings` with DEFAULT_* values (RAM only; call saveSettings() to persist)

// ============ SHARED DATA STRUCT ============
struct SensorPacket {
  float moistV;
  float moistPct;
  float battV;
  float temp;
  float hum;
  float press;
  float lux;
  uint16_t ir;
  uint16_t full;
  int pumpSeconds;
  int wifiRssi;
};

// Functions taking SensorPacket by reference need explicit prototypes: the
// Arduino auto-prototype generator skips reference parameters.
SensorPacket readAllSensors();              // sp_modular.ino
int          sendData(const SensorPacket &d);  // send_data.ino — HTTP code, -1 if offline
bool         setupWiFi();                   // wifi.ino — associate with saved credentials
bool         ensureWiFi();                  // wifi.ino — reconnect if the link dropped

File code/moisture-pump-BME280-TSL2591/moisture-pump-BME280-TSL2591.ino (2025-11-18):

#include <Wire.h>
#include <Adafruit_Sensor.h>
#include <Adafruit_BME280.h>
#include <Adafruit_TSL2591.h>
#include <WiFi.h>
#include <HTTPClient.h>
#include <WiFiManager.h>

// ================= USER SETTINGS =================
const char* deviceName = "INSERT NAME";
const char* deviceUUID = "INSERT UUID";
const char* apiUrl  = "INSERT API URL";
const char* apiKey  = "INSERT REAL KEY HERE";

// Moisture calibration
const float minMoistureVoltage = 0.60;
const float maxMoistureVoltage = 2.45;
const float batteryDividerRatio = 2.0;

// Pump control
const int pumpPin = D7;                 // MOSFET gate for pump
const float moistureThreshold = 30.0;   // % threshold below which pump activates
const int pumpDuration = 5;             // seconds pump runs when soil is too dry

// Sleep config
#define TIME_TO_SLEEP 3600
#define uS_TO_S_FACTOR 1000000ULL
RTC_DATA_ATTR int bootCount = 0;

// ========== PIN CONFIG ==========
const int moisturePin     = A1;
const int batteryPin      = A0;
const int sensorPowerPin  = D10;  // Moisture sensor power
const int bmePowerPin     = D6;   // BME280 + TSL2591 power
const int SDA_PIN         = D4;
const int SCL_PIN         = D5;

// ========== OBJECTS ==========
Adafruit_BME280 bme;
Adafruit_TSL2591 tsl = Adafruit_TSL2591(2591);

// ========== FUNCTIONS ==========
void printWakeupReason() {
  esp_sleep_wakeup_cause_t reason = esp_sleep_get_wakeup_cause();
  if (reason == ESP_SLEEP_WAKEUP_TIMER) Serial.println("Wakeup: Timer");
  else Serial.printf("Wakeup not from timer: %d\n", reason);
}

void setupWiFi() {
  WiFi.mode(WIFI_STA);
  WiFi.begin();
  int retries = 0;
  Serial.print("Connecting to Wi-Fi");
  while (WiFi.status() != WL_CONNECTED && retries < 20) {
    delay(500); Serial.print(".");
    retries++;
  }
  Serial.println();

  if (WiFi.status() == WL_CONNECTED) {
    Serial.println("Wi-Fi connected: " + WiFi.localIP().toString());
    return;
  }

  Serial.println("Wi-Fi failed. Starting WiFiManager...");
  WiFiManager wm;
  String apName = "SmartPlant-Setup-" + String(deviceName);
  wm.setConfigPortalTimeout(120);
  if (!wm.autoConnect(apName.c_str())) {
    Serial.println("WiFiManager failed or timed out. Sleeping...");
    esp_sleep_enable_timer_wakeup(TIME_TO_SLEEP * uS_TO_S_FACTOR);
    esp_deep_sleep_start();
  }
}

float readBatteryVoltage() {
  analogRead(batteryPin);
  delay(50);
  uint32_t Vbatt = 0;
  for (int i = 0; i < 16; i++) Vbatt += analogReadMilliVolts(batteryPin);
  return batteryDividerRatio * Vbatt / 16 / 1000.0;
}

float readMoistureVoltage() {
  delay(50);
  uint32_t Vraw = 0;
  for (int i = 0; i < 16; i++) Vraw += analogReadMilliVolts(moisturePin);
  return Vraw / 16.0 / 1000.0;
}

float moistureVoltageToPercent(float voltage) {
  float percent = (maxMoistureVoltage - voltage) / (maxMoistureVoltage - minMoistureVoltage) * 100.0;
  return constrain(percent, 0.0, 100.0);
}

bool readBME280(float &temperature, float &humidity, float &pressure) {
  pinMode(bmePowerPin, OUTPUT);
  digitalWrite(bmePowerPin, HIGH);
  delay(150);

  Wire.begin(SDA_PIN, SCL_PIN);
  bool status = bme.begin(0x76);
  if (!status) {
    Serial.println("BME280 not found!");
    temperature = humidity = pressure = NAN;
    return false;
  }

  temperature = bme.readTemperature();
  humidity = bme.readHumidity();
  pressure = bme.readPressure() / 100.0F;
  return true;
}

bool readTSL2591(float &lux, uint16_t &ir, uint16_t &full) {
  bool status = tsl.begin();
  if (!status) {
    Serial.println("TSL2591 not found!");
    lux = NAN;
    ir = full = 0;
    return false;
  }

  tsl.setGain(TSL2591_GAIN_MED);        // Medium gain
  tsl.setTiming(TSL2591_INTEGRATIONTIME_100MS);

  uint32_t lum = tsl.getFullLuminosity();
  ir = lum >> 16;
  full = lum & 0xFFFF;
  lux = tsl.calculateLux(full, ir);

  Serial.println("Light sensor: Full=" + String(full) + " IR=" + String(ir) + " Lux=" + String(lux, 2));
  return true;
}

int controlPump(float moisturePercent) {
  pinMode(pumpPin, OUTPUT);
  digitalWrite(pumpPin, LOW);

  if (moisturePercent < moistureThreshold) {
    Serial.println("Soil dry (" + String(moisturePercent, 1) + "%) — activating pump for " + String(pumpDuration) + " s");
    digitalWrite(pumpPin, HIGH);
    delay(pumpDuration * 1000);
    digitalWrite(pumpPin, LOW);
    Serial.println("Pump deactivated.");
    return pumpDuration;
  } else {
    Serial.println("Soil moisture sufficient (" + String(moisturePercent, 1) + "%) — pump off.");
    return 0;
  }
}

void sendData(float moistureVoltage, float moisturePercent, float batteryVoltage,
              float temperature, float humidity, float pressure,
              float lux, uint16_t ir, uint16_t full, int pumpDurationTriggered) {
  if (WiFi.status() == WL_CONNECTED) {
    HTTPClient http;
    http.begin(apiUrl);
    http.addHeader("Content-Type", "application/json");
    http.addHeader("x-api-key", apiKey);

    String json = "{";
    json += "\"name\": \"" + String(deviceName) + "\",";
    json += "\"device_uuid\": \"" + String(deviceUUID) + "\",";
    json += "\"sensors\": {";
    json += "\"moisture_voltage\": {\"value\": " + String(moistureVoltage, 3) + ", \"unit\": \"V\"},";
    json += "\"moisture\": {\"value\": " + String(moisturePercent, 1) + ", \"unit\": \"%\"},";
    json += "\"battery_voltage\": {\"value\": " + String(batteryVoltage, 2) + ", \"unit\": \"V\"},";
    json += "\"temperature\": {\"value\": " + String(temperature, 2) + ", \"unit\": \"°C\"},";
    json += "\"humidity\": {\"value\": " + String(humidity, 1) + ", \"unit\": \"%RH\"},";
    json += "\"pressure\": {\"value\": " + String(pressure, 1) + ", \"unit\": \"hPa\"},";
    json += "\"light_lux\": {\"value\": " + String(lux, 2) + ", \"unit\": \"lux\"},";
    json += "\"light_ir\": {\"value\": " + String(ir) + ", \"unit\": \"raw\"},";
    json += "\"light_full\": {\"value\": " + String(full) + ", \"unit\": \"raw\"},";
    json += "\"pump_duration\": {\"value\": " + String(pumpDurationTriggered) + ", \"unit\": \"s\"}";
    json += "}}";

    int httpResponseCode = http.POST(json);
    Serial.println("POST response code: " + String(httpResponseCode));
    Serial.println("Payload: " + json);
    http.end();
  } else {
    Serial.println("WiFi not connected, skipping data send.");
  }
}

void shutdownAndSleep() {
  digitalWrite(sensorPowerPin, LOW);
  digitalWrite(bmePowerPin, LOW);
  digitalWrite(pumpPin, LOW);
  WiFi.disconnect(true);
  WiFi.mode(WIFI_OFF);
  delay(200);
  Serial.flush();
  Serial.end();
  esp_sleep_enable_timer_wakeup(TIME_TO_SLEEP * uS_TO_S_FACTOR);
  esp_deep_sleep_start();
}

// ========== MAIN ==========
void setup() {
  Serial.begin(115200);
  delay(1000);

  ++bootCount;
  Serial.println("Boot #" + String(bootCount));
  printWakeupReason();

  setupWiFi();

  pinMode(sensorPowerPin, OUTPUT);
  digitalWrite(sensorPowerPin, HIGH);
  delay(200);

  float moistureVoltage = readMoistureVoltage();
  float moisturePercent = moistureVoltageToPercent(moistureVoltage);
  digitalWrite(sensorPowerPin, LOW);

  float batteryVoltage = readBatteryVoltage();

  float temperature = NAN, humidity = NAN, pressure = NAN;
  readBME280(temperature, humidity, pressure);

  float lux = NAN;
  uint16_t ir = 0, full = 0;
  readTSL2591(lux, ir, full);

  Serial.println("Moisture: " + String(moisturePercent, 1) + "%, Light: " + String(lux, 2) + " lux");

  int pumpDurationTriggered = controlPump(moisturePercent);

  sendData(moistureVoltage, moisturePercent, batteryVoltage,
           temperature, humidity, pressure, lux, ir, full, pumpDurationTriggered);

  shutdownAndSleep();
}

void loop() {}

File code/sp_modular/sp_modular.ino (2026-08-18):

#include <Wire.h>
#include <WiFi.h>
#include <HTTPClient.h>
#include <WiFiManager.h>
#include "config.h"

// RTC boot counter (definition, with attribute)
RTC_DATA_ATTR uint32_t bootCount = 0;

static void printWakeupReason() {
  esp_sleep_wakeup_cause_t cause = esp_sleep_get_wakeup_cause();
  switch (cause) {
    case ESP_SLEEP_WAKEUP_TIMER:  Serial.println("Wakeup: timer");      break;
    case ESP_SLEEP_WAKEUP_EXT0:   Serial.println("Wakeup: ext0");       break;
    case ESP_SLEEP_WAKEUP_EXT1:   Serial.println("Wakeup: ext1");       break;
    default:                      Serial.println("Wakeup: power-on or reset"); break;
  }
}

// Read every enabled sensor once. Does NOT run the pump — that stays in the
// normal measurement path so live-view polling can't trigger watering.
SensorPacket readAllSensors() {
  SensorPacket d;
  d.temp = d.hum = d.press = NAN;
  d.lux = NAN; d.ir = d.full = 0;
  d.pumpSeconds = 0;
  d.wifiRssi = WiFi.RSSI();

  d.moistV   = readMoistureVoltage();       // moisture always on
  d.moistPct = moistureToPercent(d.moistV);
  d.battV    = readBatteryVoltage();        // battery always on

  if (settings.useBme && !readBME280(d.temp, d.hum, d.press)) {
    Serial.println("BME280 read failed");
  }
  if (settings.useTsl && !readTSL(d.lux, d.ir, d.full)) {
    Serial.println("TSL2591 read failed");
  }
  return d;
}

void setup() {
  Serial.begin(115200);
  delay(800);

  ++bootCount;
  Serial.println("Boot #" + String(bootCount));
  printWakeupReason();

  loadSettings();
  bool doubleReset = detectDoubleReset();

  if (settings.useBme || settings.useTsl) {
    Wire.begin(PIN_SDA, PIN_SCL);
  }

  bool connected = setupWiFi();

  // Open the commissioning portal on a double reset, or when a *fresh start*
  // cannot get online — that is the case where the user is standing there with
  // the device and needs to enter credentials.
  //
  // A scheduled wake is deliberately excluded. Deep in a measurement series a
  // failed association means the network blipped, not that the device needs
  // commissioning, and opening a 5-minute AP there would cost the reading we
  // woke up to take plus a large share of the hourly power budget. Better to
  // skip the cycle and try again next hour.
  bool timerWake = (esp_sleep_get_wakeup_cause() == ESP_SLEEP_WAKEUP_TIMER);
  if (doubleReset || (!connected && !timerWake)) {
    runCommissioningPortal();
  }

  SensorPacket d = readAllSensors();

  if (settings.usePump) {
    d.pumpSeconds = runPump(d.moistPct);
  }

  int code = sendData(d);
  if (code != 200 && code != 201) {
    // The reading only lives in RAM and deep sleep destroys it, so this is the
    // moment it is lost. Nothing records that yet — see the diagnostics note.
    Serial.println("Measurement NOT delivered (code " + String(code) + ") — reading lost");
  }

  goToSleep();
}

void loop() {}

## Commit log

2025-09-18 Adds build instructions and images
    Adds a comprehensive instructions document detailing the steps to assemble the moisture sensor project, including preparation, circuit assembly, programming, and final testing.
    Includes associated images for each step to aid visual understanding.
    [moisture_circuit.fzz]
2025-09-18 Updates images and adds spacing for clarity
    Improves the visual presentation of the assembly instructions.
    Adds spacing between steps for better readability and increases the size of circuit diagrams for improved clarity.
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2025-09-18 Adds initial project files and instructions
    Initializes the "Smart Plants Starter Kit" project with a README,
    instructions, and an image of the ESP32-C6 pinout.
    The project provides a hands-on introduction to building a low-power,
    Wi-Fi-connected plant monitoring system.
    Uses a local image for the ESP32-C6 pinout in the instructions.
2025-09-23 Adds WiFi Manager for configuration
    Implements WiFi Manager to allow for easy configuration
    of the WiFi connection via a web interface if the device
    is unable to connect using the stored credentials.
    Also refactors the WiFi connection logic into its own function.
2025-11-18 Adds 3D-models
    [a8-i48-t3_cable_plug-Body.obj, a8-i48-t4_cable_plug-Body.obj, a8-i5-t3_cable_plug-Body.obj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]
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2025-11-18 Adds PCB breakout design files
    [smart_plants_breakout_rev1.csv, smart_plants_breakout_rev1.kicad_pcb, smart_plants_breakout_rev1.kicad_sch]
2025-11-18 fixed error in 3D-design
    [pump_housing-Top_large.obj]
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2025-11-18 Fixed errors in the fritzing layouts and added new ones
    [moisture+pump+i2c_circuit.fzz, moisture+pump+i2c_circuit_lipo.fzz, moisture+pump_circuit.fzz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]
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2025-11-18 Added 3D-files and Attribution
    [moisture_sensor_housing.stl, moisture_sensor_lid.stl]
2025-11-18 Updated instructions
    [full_BOM.ods]
2025-11-18 updated BOM
    [full_BOM.ods]
2026-03-06 Added PCB
    [Waveshare-ESP32-C6-Zero.step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]
2026-04-07 WS PCB bug fixes
    [smart_plants_breakout_ws-board_rev1-B_Cu.gbr, smart_plants_breakout_ws-board_rev1-B_Mask.gbr, smart_plants_breakout_ws-board_rev1-B_Paste.gbr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]
2026-04-07 WS PCB rev2
    [smart_plants_breakout_ws-board_rev2-B_Cu.gbr, smart_plants_breakout_ws-board_rev2-B_Mask.gbr, smart_plants_breakout_ws-board_rev2-B_Paste.gbr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]
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2026-04-22 fix: apply code review improvements to sp_modular firmware
    - Remove hasAnyData guard that prevented data from being sent when
    optional sensors are disabled (#3)
    - Add moisture_voltage field to JSON payload (#9)
    - Power off BME280 and TSL2591 after reading to save battery (#4)
    - Move Wire.begin() to setup() and guard it with feature flags (#5)
    - Add warm-up ADC read for battery voltage to discard noisy first
    sample (#6)
    - Log sensor init failures for BME280 and TSL2591 (#7)
    - Add serial logging to pump activation/deactivation (#8)
    - Add printWakeupReason() called on every boot (#10)
    - Change bootCount to uint32_t (#12)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
    [send_data.ino, sp_modular.ino, tsl2591.ino]
2026-04-22 reodering 3D-print files
    [light_sensor_bottom.3mf, light_sensor_bottom.stl, moisture_sensor_housing.stl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]
2026-04-22 moving light sensor file
    [light_sensor_bottom.3mf, light_sensor_bottom.stl, ring.3mf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]
2026-04-23 fix: send light sensor data when lux/IR are 0 at night
    calculateLux(0, 0) produced NaN due to internal division by zero,
    causing lux to be filtered out by isValidFloat(). The ir/full guard
    `d.ir > 0 || d.full > 0` also blocked valid zero readings.
    Fix: short-circuit calculateLux for all-zero readings, initialize
    d.lux to NAN so sensor failure is distinguishable, and gate ir/full
    on lux validity instead of a nonzero check.
    Fixes #3
    [send_data.ino, sp_modular.ino, tsl2591.ino]
2026-04-24 changed pins
    [smart_plants_breakout_ws-board_rev2.kicad_pcb]
2026-04-24 fix(tsl2591): re-init Wire with correct pins before begin(), add I2C scan debug
    Adafruit_I2CDevice::begin() calls Wire.begin() internally without
    parameters, which on ESP32 may reset SDA/SCL to default pins and
    override the Wire.begin(PIN_SDA, PIN_SCL) set in setup(). Re-calling
    Wire.begin with explicit pins in readTSL() guards against this.
    Added I2C bus scan and pin printout before tsl.begin() to give
    actionable Serial output when the sensor is not found.
    [tsl2591.ino]
2026-04-24 fixed TSL bug manually, Caude was to stupid
    [config.h, send_data.ino, sp_modular.ino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]
2026-04-28 chore: repo housekeeping for PCB-era restructure
    - Move four monolithic breadboard sketches to code/legacy/
    - Delete src/ Fritzing diagrams (superseded by img/ PNGs)
    - Untrack KiCAD auto-generated backup ZIPs (add to .gitignore)
    - Add .tmp/ to .gitignore
    The breadboard-era state is preserved at git tag v0-breadboard.
    [moisture+pump+i2c_circuit.fzz, moisture+pump+i2c_circuit_lipo.fzz, moisture+pump_circuit.fzz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]
2026-04-28 refactor: restructure hardware and code for PCB era
    Code:
    - sp_modular/config.h: add board compatibility note, calibration
    comments, and feature flag descriptions
    - sp_modular/sp_modular.ino: replace hardcoded test credentials with
    labelled placeholders + shared workshop API key
    - code/legacy/README.md: document legacy sketches as unsupported
    Hardware:
    - Archive Waveshare PCB rev1 to hardware/pcb/legacy/
    - Add hardware/pcb/README.md with ordering and KiCAD guidance
    - Add hardware/pcb/legacy/README.md
    - Add hardware/laser_files/README.md
    - Update hardware/3d-print/README.md with full parts list
    - Move light_sensor_bottom.stl into its subfolder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
    [light_sensor_bottom.stl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]
2026-04-28 fix: correct pin config board labels and add XIAO TODO
    - config.h: label active pins as Waveshare (not shared), add
    commented-out XIAO block with TODO to verify GPIO numbers
    - hardware/pcb/README.md: link each PCB to its firmware pin block
    [config.h]
2026-04-28 docs: restructure instructions and update all documentation
    Instructions:
    - Move breadboard-era guides to instructions/legacy/
    - Delete incomplete i2c_sensor_add-on.md
    - Add instructions/legacy/README.md
    - Add instructions/waveshare_pcb.md — full PCB build guide for the
    main Waveshare + ws-board_rev2 workshop build
    README.md:
    - Rewrite for PCB era: board variant table, updated kit contents,
    repo structure overview, correct instructions link
    CLAUDE.md:
    - Add both supported boards and their board packages
    - Correct device credential location (sp_modular.ino, not config.h)
    - Remove reference to deleted src/ Fritzing diagrams
    - Note XIAO GPIO TODO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
2026-04-28 refactor: move device credentials to config.h, archive BOM
    - config.h: replace extern declarations with #define for DEVICE_NAME,
    DEVICE_UUID, API_URL, API_KEY — students now configure everything
    in one file
    - sp_modular.ino: remove the credential definitions (now in config.h)
    - instructions/full_BOM.ods: move to instructions/legacy/
    [full_BOM.ods]
2026-04-28 docs: add BME280 and TSL2591 sections to background information
    Each section follows the existing pattern: comparison table of sensor
    alternatives, context on trade-offs, and workshop choice rationale.
    Placed between soil moisture and pump sections.
2026-04-28 docs: action comments left in build_instructions.md
    - 2.1: add component table from PCB BOM with orientation notes
    - 2.1: replace photo TODO + comment with actual image tag
    - 4.3: update credential snippet to reference config.h (not sp_modular.ino)
2026-04-28 docs: review and clean up build_instructions.md
    - Fix typos (resistors, through, groove, Stevenson)
    - Add image tags for 2.4 (pump), 2.5 (BME280), 3.1, 3.3
    - Add TODO placeholder for missing TSL2591 assembly images
    - Rewrite wire-colour warning as a blockquote callout (consistent in 2.5 and 2.6)
    - Add diffuser explanation in 2.6 (why the ping-pong ball helps)
    - Fix sub-section numbering in Section 3 (was 2.x, now 3.x)
    - Update Section 5 to reflect that physical assembly is in Section 3
    - Update What's Next to describe the full sensor set
    - background_information.md: add diffuser explanation to TSL2591 section
2026-04-28 fix: document PCB rev2 silkscreen bug and fill in XIAO pin block
    config.h:
    - PIN_SENSOR_POWER: replace misleading "D1" comment with "GPIO 21"
    and note the PCB silkscreen bug inline
    - XIAO block: fill in correct Arduino D-pin labels (D0, D1, D2, D10,
    A0, A1, SDA, SCL) — remove TODO
    build_instructions.md:
    - Add known issue callout at the top about the "D1-powered" silkscreen
    label on the moisture sensor connector
    [config.h]
2026-04-28 docs: restructure section 4 and add troubleshooting section
    Section 4 — Program the Microcontroller:
    - 4.2: add Adafruit Unified Sensor to library list + Install All note
    - 4.4: move WiFi setup here (was 4.6), fix AP name to show it uses DEVICE_NAME
    - Remove test/calibration steps from section 4
    Section 5 — Troubleshooting (new):
    - 5.1: moisture sensor test sketch (moved from 4.4)
    - 5.2: moisture calibration (moved from 4.5), with re-upload reminder
    - 5.3: pump test sketch (new)
    - 5.4: I2C sensor test sketch (new) — bus scan + BME280 + TSL2591 reads
    Section 6 — Final Test and Deployment (renumbered from 5)
2026-04-28 docs: action remaining Claude comments and fix minor wording
    - 2.6: fix 'Caude' typo, add TSL2591 image tags
    - 3.4: replace Claude comment with assembled.jpg image tag
    - 2.5/2.6: add missing blank line before section heading
    - 2.2: add missing period, tighten wording
    - 2.7/2.8: remove trailing spaces, add missing periods, clarify JST XH type
2026-04-28 docs: add missing tools to section 1
    Add crimping tool, wire cutters, wire strippers, and conditional drill
    to the tools list — all used in section 2 but previously unlisted.
2026-04-28 add system overview section and workshop images
    Explains in plain language how the firmware cycle works, what an API is,
    and how the FastAPI→PostgreSQL→Grafana pipeline connects device to dashboard.
    Also adds images referenced in build instructions (sensors, assembly, connectors).
2026-04-28 add KiCAD exports and ignore .Rhistory
    [smart_plants_breakout_ws-board_rev2.csv]
2026-04-28 added new cable_plugs
    [a8-i48-t3_cable_plug-Body.obj, a8-i48-t4_cable_plug-Body.obj, a8-i5-t3_cable_plug-Body.obj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]
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2026-04-28 update CLAUDE.md with session learnings
    - Fix credentials location (config.h, not sp_modular.ino)
    - Note API key is not sensitive
    - Add Adafruit Unified Sensor library dependency
    - Document PCB rev2 silkscreen bug (D1-powered → GPIO 21)
    - Document TSL2591 Wire.begin() quirk
    - Clarify XIAO pins are Arduino symbolic names, unverified on hardware
    - Add documentation section with file purposes and server stack
2026-04-28 add printable quick reference one-pager
    Single A4 page with all build steps, PCB BOM with references, wire
    orders, and a QR code linking to the full build instructions.
2026-04-29 fixed wm connection bug
    [wifi.ino]
2026-04-30 add WiFi RSSI to sensor payload
    Adds wifi_rssi (dBm) to SensorPacket and includes it in every POST to the API.
2026-04-30 revert device name and UUID to defaults
    [config.h]
2026-05-18 updated PCB files
    [smart_plants_breakout_ws-board_rev2-B_Cu.gbr, smart_plants_breakout_ws-board_rev2-B_Mask.gbr, smart_plants_breakout_ws-board_rev2-B_Paste.gbr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]
2026-06-25 added dedicated BOMs
    [bom.csv]
2026-06-26 updated BOMs
    [battery_case-Body6.3mf, bom.csv]
2026-07-01 Refactor firmware to runtime settings stored in NVS
    Move per-device configuration out of compile-time #defines in config.h
    into a Settings struct persisted in NVS/Preferences, so a single binary
    can be reconfigured without recompiling (prep for web flasher + portal).
    - config.h: feature flags and tunables become DEFAULT_* factory values;
    add Settings struct + load/save/reset declarations. Pins stay
    compile-time (board dependent).
    - settings.ino: new module with loadSettings/saveSettings/
    resetSettingsToDefaults, seeded from defaults on first boot, versioned
    for future layout migrations.
    - Convert USE_BME280/USE_TSL2591/USE_PUMP from #if guards to runtime
    settings.useBme/useTsl/use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
    [config.h, moisture.ino, send_data.ino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]
2026-07-01 Add commissioning portal with editable settings and live sensors
    Open the WiFiManager setup portal on a double reset (or when no valid
    credentials are saved) and let all runtime settings be edited there, with
    a live sensor-reading page that refreshes every 10s to confirm sensors work.
    - resetdetect.ino: NVS-backed double-reset detector (survives EN reset,
    unlike RTC RAM on C6); armed on manual reset, disarmed at deep sleep so
    scheduled wakeups never false-trigger and cause no flash wear.
    - portal.ino: non-blocking WiFiManager portal with WiFiManagerParameter
    fields for every setting (text + checkbox toggles), a saveParams
    callback that persists to NVS, and custom routes:
    /sensor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
    [portal.ino, resetdetect.ino, sp_modular.ino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]
2026-07-01 Add browser-based web flasher (ESP Web Tools)
    New web-flasher/ directory: a static page that flashes the firmware over
    Web Serial, so students don't need the Arduino IDE or USB drivers.
    - index.html: ESP Web Tools install button with unsupported-browser and
    insecure-context fallbacks, and step-by-step + deep-sleep-recovery notes.
    - manifest.json: single merged image for chipFamily ESP32-C6 at offset 0.
    - README.md: how to export the merged .bin (Arduino IDE or arduino-cli,
    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
2026-07-01 Update CLAUDE.md for runtime config, portal, and web flasher
    - Settings are now edited at runtime in the WiFiManager portal and stored
    in NVS; config.h holds only DEFAULT_* factory values.
    - Document the huge_app partition requirement and the web-flasher install
    path; note all sensor libraries are now always required.
    - Rewrite the execution flow and key-files table for the new modules
    (settings.ino, portal.ino, resetdetect.ino) and runtime feature gating.
    - Explain how to open the portal (no creds / double reset), the 5-min
    timeout + keep-awake toggle, and the live 10s sensor page.
2026-07-01 Fix portal crash on WiFi connect (double config-portal shutdown)
    On a successful connect in non-blocking mode, WiFiManager's
    processConfigPortal() calls shutdownConfigPortal() internally and frees
    `server`. Our loop then called stopConfigPortal() again, hitting the
    unguarded `server->handleClient()` on a null server -> load access fault
    (Guru Meditation) right after "Got IP Address".
    - setDisableConfigPortal(false) so WiFiManager no longer tears the portal
    down on connect; we own the lifecycle. This also keeps the live-sensor
    server alive through the connect.
    - Only call stopConfigPortal() when getConfigPortalActive() is true, as a
    belt-and-suspenders guard against a double shutdown.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
    [portal.ino]
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2026-07-01 Fix double-reset window and add portal factory reset
    Double reset was unreliable when WiFi was already known: the arming flag
    was cleared at deep sleep, so the window was only "while awake during the
    first boot" and the second press usually landed after the device had
    already slept and disarmed.
    - resetdetect.ino: on a manual reset, arm the flag and block for a fixed
    3s window during which a second reset is caught, then self-disarm.
    Scheduled timer wakeups still return early (no delay, no flash wear).
    - sleep.ino: drop the now-obsolete disarmDoubleReset() call.
    - portal.ino: add a "Factory Reset (settings + WiFi)" menu button and a
    POST /factoryreset route that restores config.h defau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
    [portal.ino, resetdetect.ino]
2026-07-01 Add "Send to API" test button on the live sensor page
    Lets the user POST the current readings on demand from the portal to
    confirm the API connection works, with clear pass/fail feedback.
    - send_data.ino: sendData() now returns the HTTP response code (-1 if
    WiFi not connected) instead of void.
    - portal.ino: POST /sendtest reads sensors, sends, and returns
    {code, ok}; live page gains a "Send to API (test connection)" button
    showing green "200 OK", "Not connected to WiFi", or the API's code.
    - config.h: declare readAllSensors() and sendData() prototypes here
    (Arduino's auto-prototype generator skips reference parameters, so
    sp_modular.ino couldn't see the new sendData signature othe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
    [config.h, portal.ino, send_data.ino]
2026-07-01 Generate a unique per-device name and UUID from the chip MAC
    Prevent setup-AP and dashboard collisions when many students provision
    boards at once. On first boot / factory reset, derive an 8-hex id from
    the factory MAC (ESP.getEfuseMac) and use it as the device UUID and as a
    suffix on the default name, e.g. "SmartPlant-1a2b3c4d". The id is stable
    per board (survives reboot/reflash/reset), so a device keeps its identity.
    DEFAULT_DEVICE_UUID in config.h is now unused; DEFAULT_DEVICE_NAME serves
    as the name prefix.
    [config.h, settings.ino]
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2026-07-01 Replace the "reconnect to AP" saved-credentials message with links
    WiFiManager's default post-save page tells the user it will return to the
    AP if it can't connect — misleading now that the portal stays up in
    AP+STA. Inject a head script (via setCustomHeadElement) that, only on
    /wifisave, rewrites the .msg text to "Credentials saved. Connecting…" with
    links back to the setup home and to the live sensor page.
    [portal.ino]
2026-07-01 Docs: make web flasher the default install path
    Rework build_instructions §4-5 around the web flasher and the runtime
    setup portal, and split the Arduino-IDE "from source" workflow into a
    separate file.
    - build_instructions.md: §4 now flashes from the browser then configures
    Wi-Fi/sensors/calibration in the setup portal (with live sensor check
    and API test); §5 troubleshooting leads with the Live Sensor Readings
    page and portal-based calibration.
    - firmware_from_source.md (new): Arduino IDE setup, huge_app partition,
    upload, and the standalone component test sketches moved out of the
    main guide.
    - CLAUDE.md: point to the new from-source doc and note the flasher default.
2026-07-02 BOM: drop duplicate Smart Plants Breakout PCB row
    The PCB is already listed as the first PCB Component (bare board); remove
    the redundant entry from the Electronics section to match bom.csv.
    [bom.csv]
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2026-07-02 Quick reference: make the PCB table full page width
    Move section 1 (soldering table) out of the two-column grid to a
    full-width block and set the table's HTML width=100% (LibreOffice's
    writer_web ignores the CSS width). The table now spans the full page and
    the Notes column no longer wraps; section 1 keeps page 1 to itself and
    section 2 onward stays on page 2. Regenerated the PDF.
2026-07-02 Quick reference: render with Chromium, drop page break, enlarge QR
    LibreOffice mis-indented the h2/th "bars" (mapping them to an indented
    Heading paragraph style CSS couldn't override), so headings weren't flush
    left. Render the PDF with headless Chromium instead, which honors the CSS
    faithfully — all headings and numbers now sit flush at the left margin.
    - Drop the page-break-before on section 2 so content flows naturally
    (single column, fills both pages evenly instead of a half-empty page 1).
    - Enlarge the QR code (72 -> 100 px).
    - Remove the h2 inline-style LibreOffice workaround; HTML is clean again.
    - CLAUDE.md: document the Chromium print-to-pdf regen command.
2026-07-02 CLAUDE.md: correct double-reset, portal, identity, and hosting details
    Final review pass to match the current code:
    - Double reset self-disarms after a ~3 s window; goToSleep() no longer
    disarms (fix execution-flow step 11 and the resetdetect.ino row).
    - Portal stays open in AP+STA until "Finish" or timeout; note the
    Send-to-API test, WiFi badge, Finish, and factory-reset actions.
    - Document the MAC-derived unique device name/UUID (SmartPlant-<uid>).
    - Web flasher is live on GitHub Pages, published from the gh-pages branch.
2026-07-03 firmware: add project grouping + per-sensor units; fixed device UUID
    - Payload now includes an optional top-level "project" string (portal-editable,
    omitted when unset) to group devices on the new dashboard.
    - Every sensor object carries an intrinsic ASCII "unit" (ir/full remain raw
    counts, no unit).
    - Device UUID is derived from the chip MAC and no longer editable in the portal;
    it's shown prominently on the portal's main page instead.
    - Bump flasher manifest to 1.1.1.
    [config.h, portal.ino, send_data.ino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]
2026-07-03 docs: fixed device UUID, project grouping, per-sensor units
    - build_instructions §4.2: UUID no longer editable and shown large on the portal
    home page; add the optional Project (dashboard group) field.
    - quick_reference (html + regenerated pdf): mention project; note the fixed UUID
    display.
    - CLAUDE.md: update the Configuration section (UUID read-only, project grouping).
    - background_information: example payload gains "project" and ASCII units; fix the
    stale "UUID you set in config.h" (now auto-generated from the chip).
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2026-08-18 firmware: retry a failed measurement instead of dropping it
    A reading only ever exists in RAM, and deep sleep destroys it, so a POST
    that fails loses the measurement for good. Nothing retried, and the
    return code of sendData() was discarded, which made every failure mode --
    no WiFi, DNS, TLS, timeout -- indistinguishable from the outside.
    sendData() now splits into buildPayload()/postPayload() so retries reuse
    one JSON string, and retries up to 3 times with a 2s/4s backoff inside a
    45s ceiling. The ceiling matters on battery: an unreachable server must
    not be able to hold the radio up for minutes.
    Only transport errors, 429 and 5xx are retried. Any other 4xx is our own
    malformed or unautho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
    [config.h, send_data.ino, wifi.ino]
2026-08-18 firmware: don't open the commissioning portal on a scheduled wake
    A failed association mid-series means the network blipped, not that the
    device needs commissioning -- but it opened a 5 minute AP portal anyway,
    costing the reading we woke up to take plus a large share of the hourly
    power budget. Skipping the cycle and trying again next hour is cheaper.
    The portal now opens on a double reset, or when a fresh start cannot get
    online, which is the case where the user is standing there with the
    device. Scheduled wakes are excluded via the wakeup cause rather than
    bootCount: RTC RAM is not reliably retained across an EN reset on the
    ESP32-C6 (see resetdetect.ino), so the boot counter is the weak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
    [sp_modular.ino]
2026-08-18 Update flasher firmware to 1.3.0
    Picks up the send retries and the portal-on-scheduled-wake fix. Minor
    bump: behaviour changes only, no config or API change, so an existing
    device keeps its saved settings across the update.
